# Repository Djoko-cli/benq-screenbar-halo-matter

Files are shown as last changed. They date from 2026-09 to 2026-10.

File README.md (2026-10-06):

[Français](README.fr.md) · **English**

# BenQ ScreenBar Halo → Matter

Control a **BenQ ScreenBar Halo (1st generation)** from any home-automation
app, by having an ESP32 pose as its 2.4 GHz remote.

The ESP32 is a native **Matter node**: no Homebridge, no MQTT broker. Since
Matter is multi-admin, the same device can be shared between several
ecosystems at once — see the certification caveats below.

Every document comes in English and in French (the `.fr.md` files), with a
language switch at the top.

## What is exposed

| Endpoint | Matter type | Controls |
|---|---|---|
| EP1 "Halo" | Color Temperature Light | on/off, brightness, temperature 153-370 mireds |
| EP2 "Halo avant" | On/Off Light | front lamp on (power AND front lamp) |
| EP3 "Halo arriere" | On/Off Light | back lamp on (power AND back lamp) |
| ~~EP4 "Halo auto"~~ | On/Off Plug-in Unit | **disabled by default** (see below): presses button A (auto mode), turns itself back off after 1 s (`matter impulsion <ms>`); pressing A on the remote triggers the same pulse |

- A radio frame carries a single value: both lamps share brightness and
  temperature, hence a single slider of each on EP1.
- Turning EP1 on restores the last lamp selection, like the remote's power
  button. Turning off EP2 then EP3 turns the lamp off.
- EP4, if re-enabled, is ignored when the lamp is off, and when it arrives
  together with a power or lamp command (room command, grouped tile): in
  Apple Home, show the accessories as separate tiles.
- Names are set in the app. The Kelvin values (~6500 to ~2700 K) are
  nominal, not measured.
- In `src/config.h`: `HALO1_SELECTORS_AS_LIGHTS 0` exposes EP2 and EP3 as
  outlets (a room-wide "turn off the lights" no longer touches them).
- Nothing is sent to the lamp at startup: the node restores the saved state,
  and only a command (Matter or `lampe ...`) triggers a transmission.

> **Upgrading to 0.3.0 from EP1..EP4** (Halo, front, back, auto): flash over
> the same environment (`pio run -e esp32c6thread -t upload` for the Apple
> Home Thread node), without `-t erase` or `decommission`: the pairing is
> kept, only EP4 disappears.
>
> **From the old endpoint layout** (power, front light, back halo, sensor,
> auto mode): the node must be commissioned again. Remove the accessory from
> each app, run `decommission` (or hold BOOT for 8 s, then release), then add
> it again with the pairing code (`matter`).

### EP4 "Halo auto": disabled for now

Since 0.3.0 (decision of Sep 23), `HALO1_EXPOSE_AUTO` defaults to 0: button A
is no longer exposed in Matter. The code remains, but is compiled out of the
firmware: no endpoint, no mirroring of the remote's A presses, no pulse
setting (`matter impulsion` says so, `matter` shows « bouton A (EP4) :
desactive »). EP1 to EP3 keep their numbers (EP4 was created last). Button A
remains available from the console: `lampe auto`.

On a node that is already paired, EP4 disappears from the node's endpoint
list, but Apple Home kept its "Halo auto" tile, "No Response", even after
restarting the bridge and the home hub (field test, 06/10). Since 0.4.1 the
bridge publishes the ConfigurationVersion attribute of Basic Information (EP0,
Matter 1.4) and raises it when its endpoint list changes (EP4 exposed or not,
EP2 and EP3 as lights or plugs), and on the first boot of a firmware that
tracks it: a controller that follows it then reads the device again.
`matter` prints the published version (`configuration` line). In the field
(06/10), the ESP32 layer of the stack refuses to store it (`pile REFUSE`): a
controller may still read 1, and the effect on Apple Home is not established.
What removed the tile: removing the bridge from Apple Home, `decommission` (or
8 s on BOOT), then pairing it again; "Halo auto" did not come back. "Remove
Accessory" from the tile removes the whole bridge: only do it for that.

To **bring it back**, add `-DHALO1_EXPOSE_AUTO=1` to the environment's
`build_flags` (for example `[env:esp32c6thread]` in `platformio.ini`), or
change the default in `src/config.h`, then reflash the same environment
(`pio run -e esp32c6thread -t upload`, without erasing). EP4 comes back with
the same number, its pulse duration saved in NVS (`halo1/impulsion`) is
restored, and the app shows it as a new accessory to place.

### Node identity

The Basic Information cluster (EP0) carries the product identity, set at
every boot before `Matter.begin()` (values in `src/config.h`, `MATTER_*`
macros, overridable with `-D`):

| Attribute | Value |
|---|---|
| VendorName | `Djoko-CLI` |
| ProductName | `Pont ScreenBar Halo` |
| NodeLabel | `Halo` (rewritten at every boot: a name written to this attribute by a controller is replaced) |
| SerialNumber | `HALO1-` + the factory MAC address as 12 hex digits, unique per board |
| HardwareVersion / HardwareVersionString | `1` / `ESP32-C6 SuperMini + BM5602` |
| SoftwareVersionString | `0.4.1-<commit>` ("Firmware" in Apple Home) |

- The VID and PID do not change (`0xFFF1` / `0x8000`, test certificate), nor
  do the discriminator and the pairing code: no re-commissioning. An app may
  take a while to re-read these values.
- `SoftwareVersionString` is the version from the application descriptor
  (`esp_app_desc`), which `src/app_desc.c` replaces: without it, it was the
  commit of Arduino's lib-builder (`6671d0b`). `FW_VERSION` is set in
  `platformio.ini` (`build_src_flags`); the commit comes from
  `tools/git_rev.py`, followed by `-dirty` if a tracked file was modified at
  build time, or if an untracked file was lying in `src/`, `include/` or
  `lib/`.
- `matter` shows these values as the stack reports them (`identite` and
  `versions` lines), except the NodeLabel (requested value, not read back),
  and flags any rejected value. Boot prints `firmware 0.4.1-<commit>` and
  warns if the descriptor read from the flashed image differs. Without a
  board, the same version (`App version`) can be read with:
  `pio pkg exec -p tool-esptoolpy -- esptool.py --chip esp32c6 image-info .pio/build/<env>/firmware.bin`.

## Companion app (macOS)

[Halo Compagnon](apps/macos/README.md) supervises the bridge over USB or over
the Thread network: target and raw state of the lamp, radio module, Thread
and Matter, live decoded frames, charts, commands and console. It installs
from a `.dmg` in the Halo Compagnon [releases](https://github.com/Djoko-cli/benq-screenbar-halo-matter/releases)
(`compagnon-vX.Y.Z`), then updates itself ([Installing](apps/macos/README.md#installing)).
Screenshots in demo mode (no hardware):

<p>
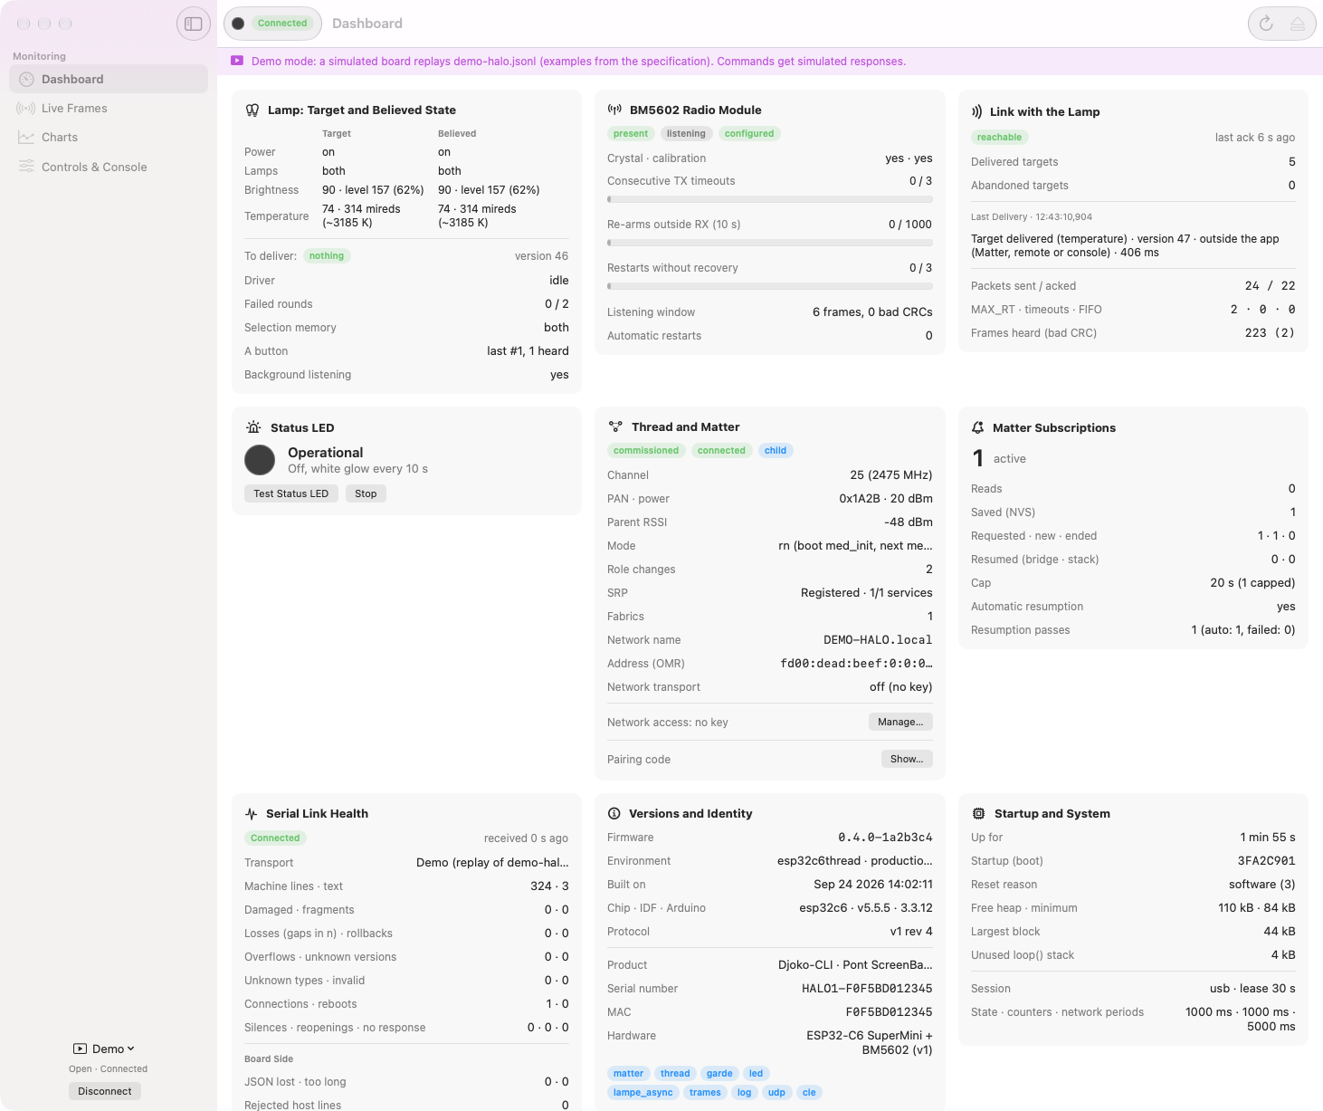
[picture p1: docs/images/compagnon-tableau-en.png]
Halo Compagnon: dashboard
  
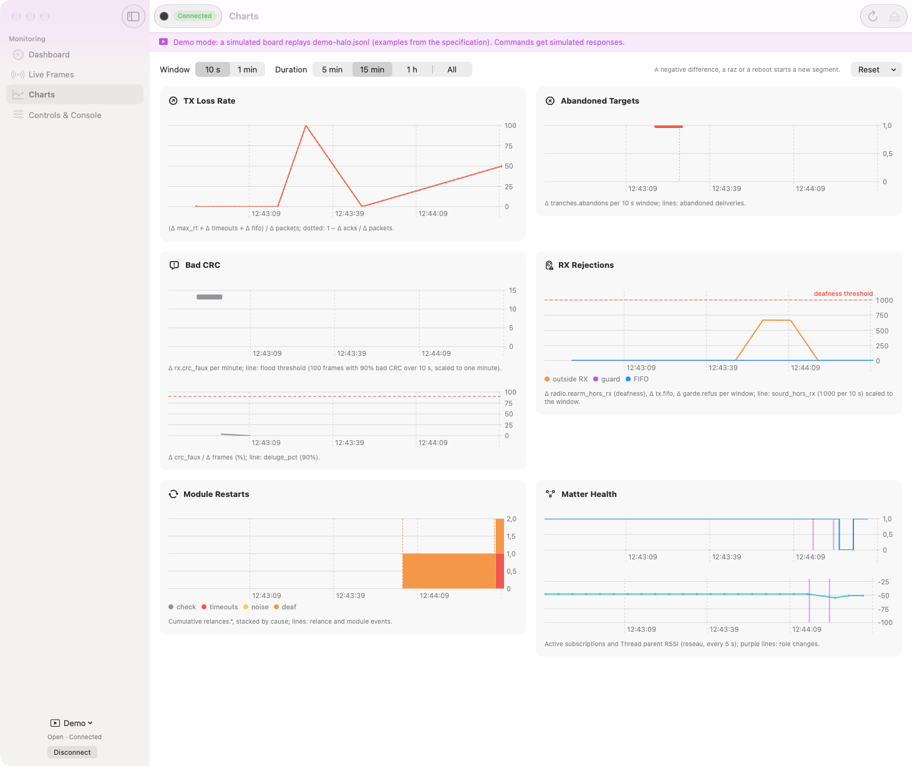
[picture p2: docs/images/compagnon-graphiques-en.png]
Halo Compagnon: charts
  
</p>

## Hardware

| Part | Role | Approx. price |
|---|---|---|
| **ESP32-C6 SuperMini** | MCU + Thread radio + Matter | ~€5 |
| **Holtek BM5602-60-1 RF module** | 2.4 GHz transceiver | ~$3–4 |

### Why the ESP32-C6

The bridge joins Apple Home over **Matter over Thread** (`esp32c6thread`
target). It needs an 802.15.4 radio: among the boards tried, only the C6 has
one. The C3, the S3 and the classic ESP32 only have Wi-Fi. Their targets still
build, as Matter over Wi-Fi, but the bridge does not use them and they are no
longer tested.

| Target | Matter network | Commissioning | Firmware size |
|---|---|---|---|
| **ESP32-C6 SuperMini** (`esp32c6thread`) ✅ | Thread | BLE | 2.50 MB |
| ESP32-C3, ESP32-S3 | Wi-Fi only | BLE | 1.79 / 1.97 MB |
| Classic ESP32 | Wi-Fi only | IP: credentials set first (`wifi <ssid> <mdp>`), the Bluetooth stack does not fit | 1.81 MB |

C6 size measured on Sep 24 (2,616,992 bytes). The other targets have not been
rebuilt since: their figures are older.

### Why the BM5602 and not a CC2500 or an nRF24L01+

The BenQ transmits **GFSK at 125 kbps**, with an Enhanced ShockBurst frame
format: preamble, 4-byte address, 9-bit PCF, CRC, and above all **hardware
auto-ACK** — the lamp answers *only* in the ACK slot.

| Chip | 125 kbps | Arbitrary 32-bit sync word | ESB auto-ACK |
|---|---|---|---|
| nRF24L01+ / BK2425 | ❌ 250 k / 1 M / 2 M only | ✅ | ✅ |
| CC2500 | ✅ | ❌ the 32-bit mode repeats the 16-bit word | ❌ must be done in software |
| **BC5602 / BM5602-60-1** | ✅ 125 / 250 / 500 k | ✅ | ✅ |

The nRF24 is ruled out right away: it cannot go down to 125 kbps. The CC2500
can, but you would have to reimplement the nRF24 CRC in software (computed
over address + PCF + payload, not the CC2500's), work around the sync word
limit, and produce the ACK within a window of about 130 µs. Doable on paper,
very painful in practice.

The BC5602 is **exactly the chip inside the lamp and the remote** (confirmed
by the FCC filings and by a PCB teardown). The whole protocol is handled in
hardware.

### Where to buy it

The module is the project's main friction point — it is not a mass-market
part.

- [Best Modules Corp](https://www.bestmodulescorp.com/en/bm5602-60-1.html) —
  a Holtek subsidiary, ~$3.10–4.28
- [Sourcengine](https://www.sourcengine.com/part-info/BM5602-60-1-145144816391)
- Official Holtek distributors
- [Holtek product page](https://www.holtek.com/page/vg/BM5602-60-1)

Buy two: at ~$4 each, it saves you wondering whether the module is dead when
something does not work.

## Wiring

See [docs/WIRING.md](docs/WIRING.md). In short, on the ESP32-C6 SuperMini
(the default target):

| BM5602 | C6 SuperMini |
|---|---|
| `VDD` / `VSS` | 3V3 / GND |
| `SCK` | IO18 |
| `GIO2` | IO19 (MISO) |
| `SDIO` | IO20 (MOSI) |
| `CSN` | IO14 |

> `GIO2` serves as MISO: the firmware switches the module to 4-wire SPI at
> init. The module has no markings, and the order of its pads reverses
> depending on the side you look at: see
> [docs/WIRING.md](docs/WIRING.md#bm5602-60-1-module-pinout).

In the enclosure, the C6 lies upside down (seen from the back) and the BM5602
flat side up, turned a quarter turn, antenna away from the C6:

<p align="center">
  Halo bridge wiring in its enclosure: six wires between the C6 SuperMini seen from the back and the BM5602 flat side up
</p>

## Enclosure

A 3D-printed enclosure holds both boards, with their antennas at opposite ends
(25 mm apart), and screws under the desk with two Ø3.5 × 16 mm countersunk wood
screws. The WS2812 status LED shows through a diffusing window, and the USB-C
port stays accessible.

<p align="center">
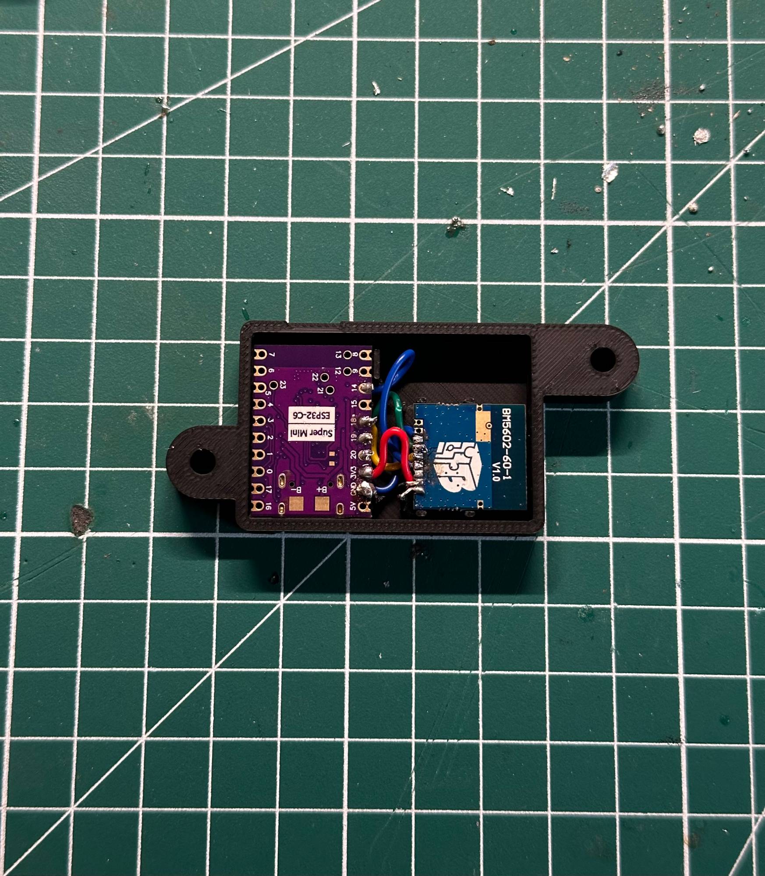
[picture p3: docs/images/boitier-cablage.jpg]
Both boards wired in the enclosure base
  
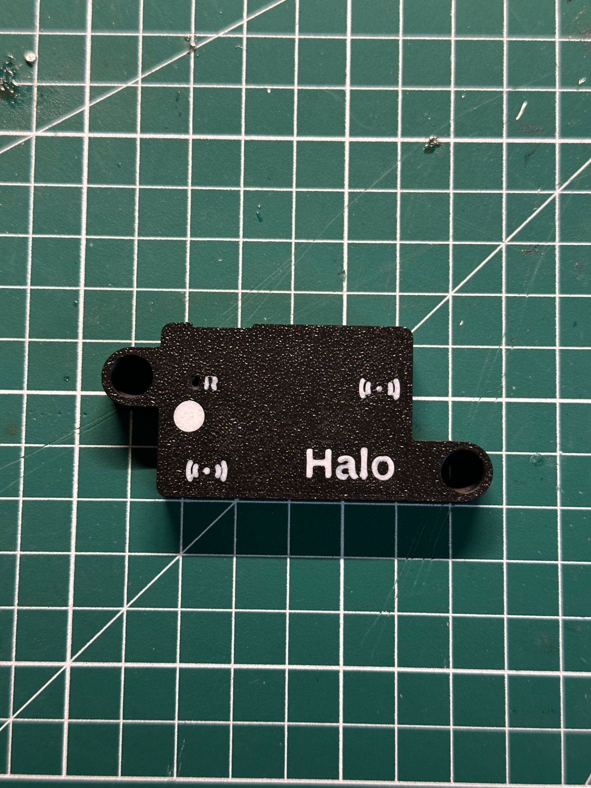
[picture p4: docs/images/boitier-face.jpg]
Engraved Halo face, with the status LED window
  
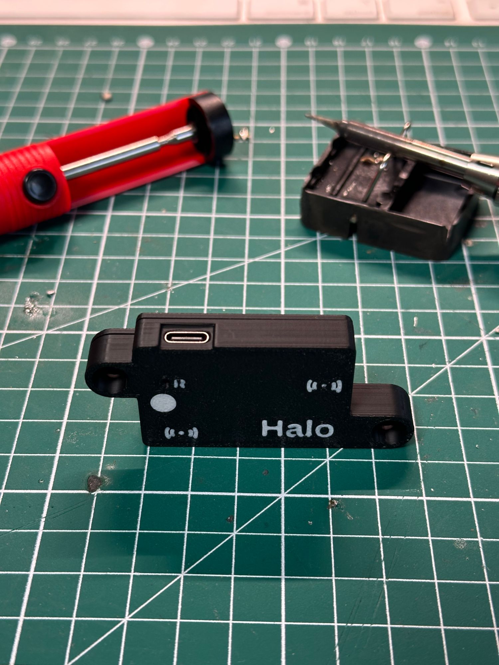
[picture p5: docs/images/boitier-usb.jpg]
Closed enclosure, USB-C side
  
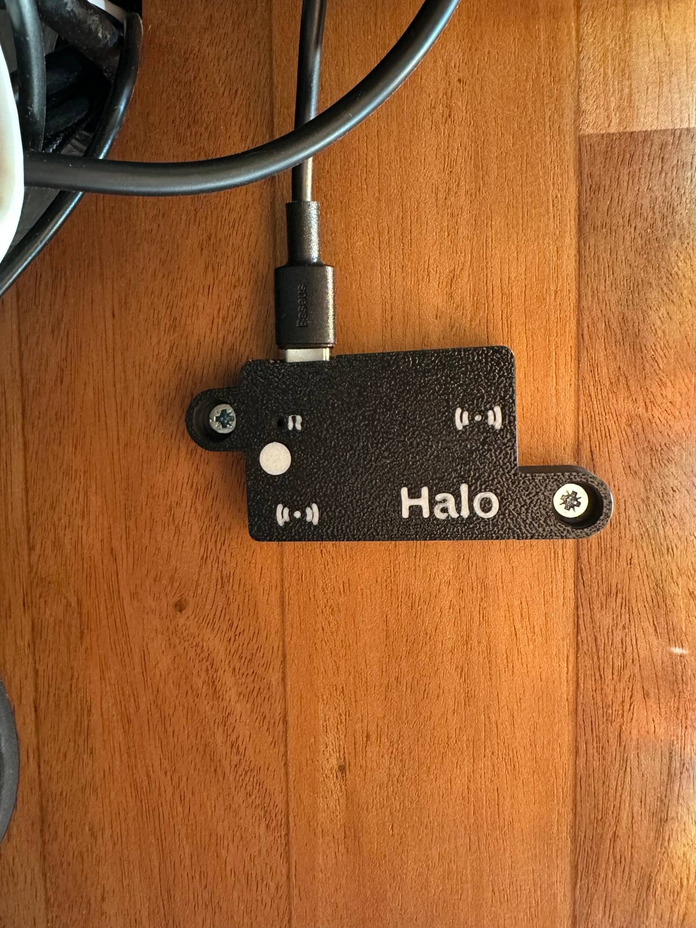
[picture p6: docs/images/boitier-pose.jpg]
Enclosure screwed under the desk
  
</p>
<p align="center">
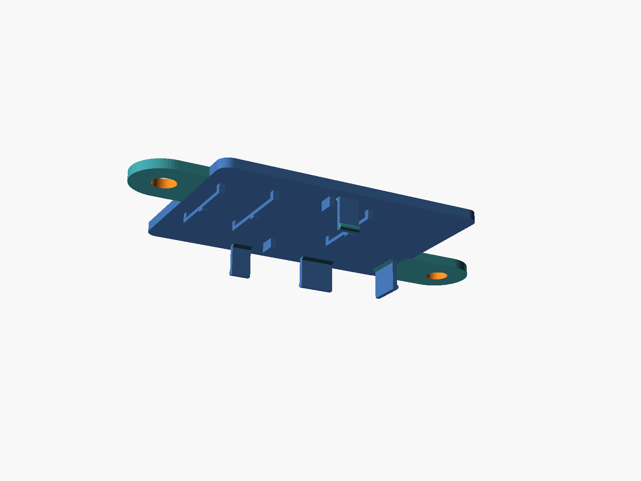
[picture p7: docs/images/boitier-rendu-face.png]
Render: engraved face
  
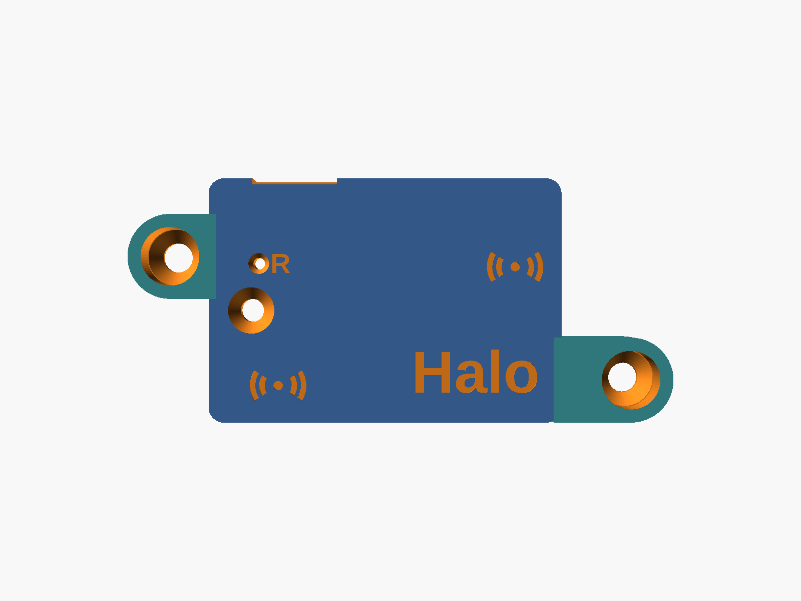
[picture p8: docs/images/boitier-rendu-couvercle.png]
Render: lid, clips and springs
  
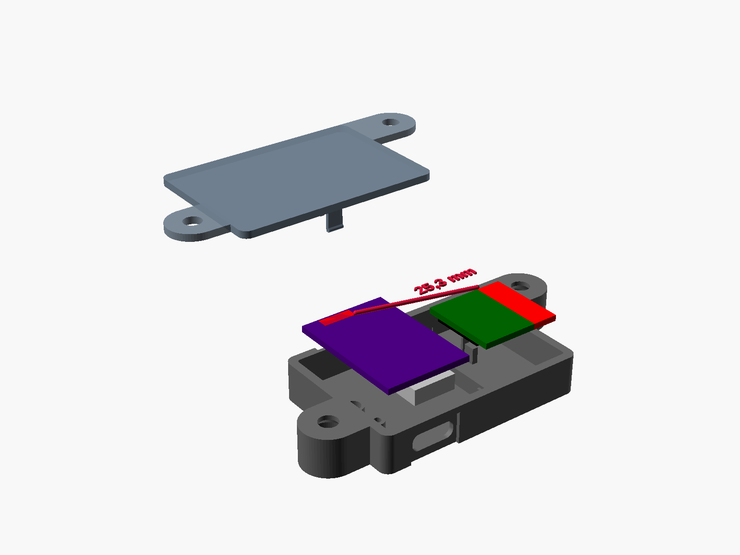
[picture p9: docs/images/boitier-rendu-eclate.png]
Exploded render: 25.3 mm between the antennas
  
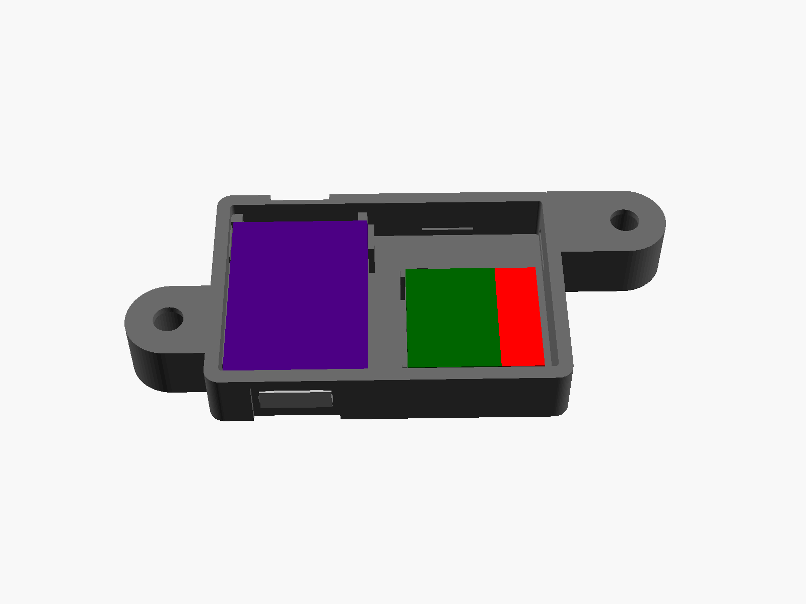
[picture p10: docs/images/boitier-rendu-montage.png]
Render: both boards in the base
  
</p>

The files are in [hardware/boitier](hardware/boitier):

| File | Part |
|---|---|
| `halo-bridge-housing.3mf` | Bambu Studio project: the four parts, already placed |
| `Back.stl` | base (70.7 × 31.6 × 8.2 mm): the visible face, engraved "Halo" |
| `Front.stl` | lid (70.7 × 31.6 × 7.0 mm): against the desk, clipped on; its springs press the boards down |
| `Diffuser.stl` | white disc for the status LED window (AMS option) |
| `Engravement.stl` | fill for "Halo", the R and the antenna marks (AMS option) |

**Printing**: black PLA, 0.2 mm layers, 4 walls, 15 % infill, no supports.
With an AMS, assign the engraving and the diffuser to a white PLA, without
moving them. **Without an AMS, delete them before slicing**: printed in black,
they would fill the engraving and block the status LED window.

**Assembly**: the C6 components side down, USB-C in its opening; the BM5602
flat side up, antenna toward the far wall (diagram above). The lid clips on,
then the two screws go through the whole assembly.

## Building

```bash
pio run -t upload -t monitor
```

The default target is `esp32c6thread` (Matter over Thread), the bridge's. The
others are selected with `-e`: `esp32c6supermini` (Matter over Wi-Fi),
`esp32c3`, `esp32s3`, `esp32dev`.

> Do not flash a Wi-Fi build onto a node paired over Thread: the pairing stays
> in NVS, but the node becomes unreachable until the Thread build comes back.

If the board boot-loops right after flashing, the clone's flash memory does
not like QIO mode: add `board_build.flash_mode = dio` to the environment.

Two build constraints, both already set in `platformio.ini`:

- **The platform is the [pioarduino](https://github.com/pioarduino/platform-espressif32) fork.**
  The Matter library ships with the Arduino-ESP32 3.x core (nothing to
  install through `lib_deps`), whereas PlatformIO's official platform stayed
  on core 2.0.x, which has no Matter at all.
- **`huge_app.csv` partitions** (3 MB APP). The Matter stack alone weighs
  ~1.4 MB. Accepted consequence: **no OTA** on a 4 MB flash.
  `min_spiffs.csv` would leave room for OTA but only fits on the C3 and the
  classic ESP32, with ~150 KB of headroom — it overflows on the S3 and C6.

## Commissioning

### 1. Check the link with the lamp

The firmware already knows the lamp's link address: `63 FD F0 4F` on air,
i.e. `4FF0FD63` in the BM5602's write order, channel 5 (2405 MHz), 125 kbps.
`lampe adresse` shows it. Nothing to search for.

In the serial monitor, listen to the remote while you use it (30 s by
default):

```
ecoute 4FF0FD63 5
```

Every gesture should print frames decoded with a correct CRC (`C4 xx` for
the dial, for example). Then `lampe` shows the driver state: target, raw
state, fields to deliver, link and radio. A first command, `lampe on` or
`lampe lum A0`, should end with an `ok ... accuses` line.

The link address depends on the remote (it comes from BenQ's pairing). For
another lamp/remote pair, `lampe adresse XXXXXXXX` (write order) stores it
in NVS. How it was found: [docs/PROTOCOL.md](docs/PROTOCOL.md).

### 2. Pair the Matter node

The pairing code is printed at boot, and `matter` shows it again:

```
code manuel : 34970112332
```

A Matter controller is required — HomePod, Apple TV, Google Nest, Echo, or
Home Assistant's *Matter Server* add-on.

Holding the **BOOT** button for 8 s, then releasing it, or the
`decommission` command, removes all fabrics so you can re-pair from scratch
(see "4. BOOT button").

### 3. Status LED

The product's indicator is the board's RGB LED (WS2812), on IO8, in the
`esp32c6thread` and `esp32c6supermini` builds. Low brightness, since it
lives under the desk: 24/255 at most per channel, 8/255 for the white glow.

| LED | Meaning |
|---|---|
| blinking blue (2 Hz) | not commissioned yet: add the accessory from the app |
| slow orange (1 s on, 1 s off) | commissioned, but no network (Thread lost; Wi-Fi for `esp32c6supermini`) |
| off, brief white glow every 10 s | all good (sign of life); also a glow when the network comes back |
| steady red | radio module down: automatic restarts did not help (see below), or module lost; lasts until it recovers |
| green flash (150 ms) | a command has just been delivered to the lamp (acknowledged) |
| red, 3 blinks | lamp unreachable: the driver gives up the command (also when the radio module is lost or down) |
| rainbow | "Identify" requested from Apple Home (Identify cluster), for the whole identification |
| red, black, purple, black, fast | BOOT button held 8 s: release to unpair, then unpairing in progress until the reboot (see "4. BOOT button") |
| white flash (150 ms) | BOOT button, short press released: reboot |

Priority: rainbow > BOOT button > red ×3 > steady red > green > network state
(the blacks of the three blinks remain visible over the steady red). On the
bench, `led test` plays each pattern in turn (21 s; the button takes over)
and `led` reports the current pattern and the radio module state. If green
and red are swapped, the board's WS2812 is not GRB:
`-DSTATUS_RGB_ORDER=LED_COLOR_ORDER_RGB` in `platformio.ini`.

The small LED on IO15 stays an input, so it is off whatever its polarity: a
single indicator. As an input, it also does not interfere with the CC2500's
GDO2, which lands on IO15 when the capture board is plugged in. The
diagnostic build only sets the WS2812 to black at boot: it keeps its last
color across a reset or a flash, and a product build's blue would otherwise
stay lit on the bench. Among the other targets, only `esp32dev` blinks its
simple LED (IO2) with the same patterns, without the glow; on the C3 and S3
DevKits, `PIN_STATUS_LED` (IO8, IO48) is the pin of their WS2812, not
declared: no visible indicator.

**Automatic radio module restart.** On Sep 24, the metal tip of a sliding
caliper resting on the BM5602's crystal locked it up for ~70 min: every
transmission timed out (186 in a row at the end), listening went deaf (no
frame at the end, after ~96,000 frames with a bad CRC since boot), while its
configuration still read back correctly; only `rfinit` cured it. So the
driver restarts the module on its own (`halo.begin()`, ~300 ms, up to
~0.5 s if the crystal or the calibration do not respond) on three chip
symptoms: 3 transmissions in a row with neither TX_DS nor MAX_RT (30 ms
timeout); while listening, at least 100 frames in 10 s, of which at least
90 % with a bad CRC (the remote's dial produces ~9 per second, with a
correct CRC); or deaf listening, at least 1000 re-arms in less than 10 s on
a chip that does not stay in receive mode (the incident produced ~450 per
second, seen within ~2-3 s; normally estimated at well under one per second,
inferred from the totals, to be confirmed with « hors RX » in
`lampe stats`). An unplugged lamp (MAX_RT, silence) never triggers a
restart. At most one restart per minute; after 3 restarts in a row without
recovery (an acknowledgement, a listening window with mostly correct CRCs,
or, after a restart for deafness, 10 s of listening during which the chip
stays in receive mode with no timed-out transmission), if the symptom comes
back, the module is **DOWN**: steady red, one attempt every 10 min. Each
restart writes `[lampe] BM5602 : ...` lines on the console (never blocking:
lost if the serial buffer is full); `lampe` shows the state and the last
restart, `lampe stats` the restarts by cause and the latest ones, with
timestamps. Details and thresholds:
[docs/PLAN-PILOTE-HALO1.md](docs/PLAN-PILOTE-HALO1.md), C.5.

### 4. BOOT button

In the 3D-printed case, only **BOOT** (IO9, marked B) remains accessible: no
RST. So it is used to reboot and to unpair. Everything is decided **on
release**:

| Press | LED during the press | On release |
|---|---|---|
| less than 2 s | nothing special | white flash (150 ms), then **reboot** (lamp state saved first, like `reboot`) |
| 2 to 8 s | nothing special | **cancelled**: nothing happens (safeguard against a mistake) |
| 8 s or more | red, black, purple, black, fast (100 ms each) from 8 s: "release to unpair" | **unpairing**: removal of all Matter fabrics (the accessory leaves Apple Home), then reboot; the LED keeps the red/purple until the reboot |

IO9 is a strapping pin: **held low at reset, it makes the C6 boot into
download mode**, where it stays inert until a power cycle. So the firmware
never acts while the button is pressed: it waits for the release (30 ms
debounce), then 100 ms of uninterrupted high readings, and reads the pin
again 100 ms right before acting (pressed and held again at that moment, the
action is abandoned). Finally, **every** software reboot (button, `reboot`,
`decommission`, and the end of unpairing, which the Matter stack triggers
itself a while later) waits until the pin has read high for 50 ms in a row:
BOOT held during a reboot delays it until release, with no limit (a stuck
button blocks the board, which restarts as soon as it is released, instead
of leaving it in download mode). Other safeguards:
- a button already pressed at boot is ignored until it is released;
- a new press while an action is pending abandons it: it counts on its own;
- during unpairing, the button is inert (a reboot in the middle of the erase
  would leave Matter half removed); if the board is still running 10 s
  later, it reboots on its own;
- if `loop()` was blocked for more than 100 ms during the press or at one of
  its edges (bench tool, radio module restart), the duration is uncertain:
  the press is ignored (except a long press already armed, which is
  certain);
- every decision is announced on the console, `[bouton] ...` (`log`
  message, `src` `bouton`, in `json log 1` mode, outside the log cap).

Diagnostic build (no Matter, no LED): a short press reboots; a long press
only explains itself on the console. Pure logic, tested on the host:
`src/boot_button.*`.

### Certification: what works and what needs an extra step

The firmware uses the **Matter SDK test certificates**: `VID 0xFFF1`,
`PID 0x8000`. This is the normal development mode, but each ecosystem
treats it differently:

| Ecosystem | Behavior |
|---|---|
| **Home Assistant** | accepts it directly (Matter Server) |
| **Apple Home** | adds the accessory while showing an "uncertified accessory" warning, which you just confirm |
| **Google Home** | refuses it, unless you create a project in the [Google Home Developer Console](https://developers.home.google.com/matter/get-started) declaring the same test VID/PID pair |
| **Alexa** | not checked |

Removing the warning entirely would require a CSA-assigned VID and a
certification — out of reach for a personal project.

## Serial commands

`help` lists everything. Commands and their output are in French.

| Command | Effect |
|---|---|
| `info` | hardware, radio configuration, driver state |
| `matter` | Matter state, pairing code, node identity and versions, bridge counters, Identify requests |
| `matter impulsion [300..15000]` | duration of the EP4 pulse in ms, kept in NVS (only when EP4 is re-enabled; otherwise a message says so) |
| `matter reprise` | (Thread) immediately restarts the resumption of Apple Home's saved subscriptions |
| `matter reprise auto [0\|1]` | (Thread) restarts on its own after a reboot: Thread + SRP ready for 10 s, not before 50 s (plus the saved floor), for each saved subscriber with no active subscription; CASE session first (a failure costs the stack nothing), then resumption; then 30 s, 60 s, 5 min after each failure, and a check every 5 min as long as a subscription is active (NVS) |
| `matter med [0\|1\|2]` | (Thread) device type at the next boot: 0 router, 1 MED from init (no new attach), 2 MED after `Matter.begin()` (old behavior) (NVS) |
| `matter maxint [0\|10..3600]` | (Thread) cap on the max interval of new subscriptions, 20 s by default, 0 = the controller's (NVS). Only applies from Apple's next new subscription: a resumed subscription keeps its saved interval |
| `lampe` | Halo 1 driver: target, raw state, fields to deliver, link, radio |
| `lampe on` / `lampe off` | turn on / off, same rules as Matter |
| `lampe avant on\|off` / `lampe arriere on\|off` | one lamp, front or back (like EP2 / EP3) |
| `lampe mode avant\|arriere\|deux` | lamps lit (and power on) |
| `lampe lum 4C..FE` / `lampe niveau 1..254` | raw brightness (hex) / Matter level |
| `lampe temp 0..100` / `lampe mired 153..370` | temperature: 0 cold, 100 warm / in mireds |
| `lampe auto` | button A (refused when the lamp is off) |
| `lampe sync` | resends everything known |
| `lampe trace 0\|1` / `lampe stats` | per-event log / counters, including the automatic module restarts by cause |
| `lampe adresse [8 hex]` | lamp address (write order), in NVS |
| `lampe help` | all `lampe` commands (settings and bench) |
| `led` | status LED: current pattern, displayed color, radio module state |
| `led test` / `led stop` | plays each LED pattern in turn (21 s), without blocking / stops it |
| `ecoute 4FF0FD63 5 [ms]` | passive listening to the remote, never acknowledging |
| `txack <adr> <canal> <charge> [n] [ms]` | bench: standard-format transmission, automatic acknowledgement, verdict per attempt |
| `regs` | dump of the BC5602 registers |
| `rfinit` | re-tests the module after fixing the wiring, without reflashing |
| `wifi <ssid> <mdp>` | Wi-Fi credentials (classic ESP32 only) |
| `decommission` | removes all Matter fabrics |
| `reboot` | saves the lamp state, then reboots |

`help` also lists the bench and reverse-engineering tools: `prxack`, chip,
spectrum and GIO3 probes, CC2500 module. `addr` and `chan` only configure
those tools; the driver has its own address (`lampe adresse`).

A line longer than 127 characters is refused (`Ligne refusee (trop_long)`),
instead of being truncated and then executed; Ctrl-U clears the current
line.

### Machine mode (companion app, since 0.4.0)

The supervision app (macOS first) talks to the board over the same USB
port, or over the Thread network (UDP, section 10), with the protocol in
[docs/PROTOCOLE-JSON.md](docs/PROTOCOLE-JSON.md): it sends console commands
prefixed with `id=<n> `, and the board answers with machine lines (RS byte
0x1E + a compact JSON object + LF, 1024 bytes at most), mixed with the usual
text. Without `json 1` and without `id=`, the human console is unchanged.

| Command | Effect |
|---|---|
| `json` | session state, as text |
| `json 1 [bail 0\|10..600]` | machine mode: echo, prompt and `Serial.flush()` disabled; `hello`, `config`, then the full snapshot; 30 s lease by default, renewed by any received line (`json ping`); `bail 0` on the bench: until `json 0` |
| `json 0` | back to human mode (`fin` message, then the prompt); over the network, also frees the session's slot (rev 4) |
| `json etat` / `json hello` | snapshot (`etat`, `compteurs`, `reseau`) / `hello` and `config`, once, even in human mode |
| `json periode\|compteurs\|reseau <ms>` | periods of the `etat` messages (0 or 200..60000, 1000 by default), `compteurs` (same), `reseau` (0 or 1000..60000, 5000); `hb` every 2 s if the `etat` messages are off or slow |
| `json trames 0\|1` / `json log 0\|1` | `rx` and `tx` events (on by default) / `[lampe]` and `[matter]` announcements as `log` messages instead of text |

- With `id=`, every line receives a `reponse`; the `lampe` state commands
  (`on`, `off`, `avant`, `arriere`, `mode`, `lum`, `niveau`, `temp`,
  `mired`, `auto`, `sync`) become asynchronous: `reponse` right away (code
  `accepte`, `differe` or `ok`), then `livraison` when the driver is done.
  The other commands keep their text, between `reponse debut` and
  `reponse fin`.
- The board never waits for the app: a line that does not fit in the
  transmit buffer is lost and counted (`etat.sante.sys.json_perdus`), and
  `n` skips. One exception, without blocking the loop: a deferred `reponse`
  (after the snapshot of `json 1`, `json etat`, `json hello`, or the `fin` of
  a command whose text filled the buffer, such as `help`) waits in a queue
  for room for a whole line. At most 20 lines per second from the host
  (`cadence`).
- Nothing is persisted: every boot starts in human mode. `json cle` sets the
  network transport key (section 10.4), over USB only.
- On the bench, `python3 tools/json_check.py <capture>` checks a raw capture
  of the port (framing, types, required fields, sizes, gaps in `n`); a field
  unknown to v1 is only a warning (`--strict`: an error).

## Halo 1 protocol

The protocol is established, and verified by transmitting to the lamp:
standard BC5602 frame (4-byte address, 9-bit PCF, hardware CRC-16), two-byte
payload (power / lamps / selector flags, then value), empty
acknowledgement. So the lamp's state cannot be read: the driver tracks the
state it sends and what it hears from the remote. Details, evidence and
still-open questions: [docs/PROTOCOL.md](docs/PROTOCOL.md) (header block,
then the Halo 1 sections at the end).

## Layout

```
platformio.ini            4 ESP32 targets, pioarduino platform, huge_app partitions
src/config.h              pins, Halo 1 driver settings, Matter identity
src/fw_version.h          firmware version (FW_VERSION + git revision)
src/app_desc.c            application descriptor: version reported by Matter
src/bc5602.{h,cpp}        low-level transceiver driver
src/cc2500.{h,cpp}        minimal CC2500 driver: raw listening (cc* commands)
src/swd.{h,cpp}           bit-banged SWD (swd command)
src/halo.{h,cpp}          module startup (also the driver's restart), bench tools
src/halo1_proto.{h,cpp}   pure Halo 1 protocol: frames, CRC, scheduling
src/halo1_map.{h,cpp}     Matter <-> lamp mappings, intent rules
src/halo1_radio.{h,cpp}   proven BC5602 sequences, non-blocking reconfiguration
src/halo1_watch.{h,cpp}   when to restart the module on a chip symptom (pure logic, tested on the host)
src/halo1_lamp.{h,cpp}    driver: target, acknowledged bursts, tracking of the remote
src/cli_lampe.cpp         'lampe ...' commands
src/matter_bridge.{h,cpp} Matter endpoints, intent box, mirror of the target, Identify
src/matter_resume.h       resumption schedule of Matter subscriptions (Thread bridge)
src/halo1_events.h        driver events as plain data (frames, packets, restarts, module)
src/json_out.{h,cpp}      JSON protocol: machine line writer, messages, queue (pure, tested on the host)
src/json_mode.{h,cpp}     machine mode: session, 'json' commands, periodic state, events, deliveries
src/h1_proto.{h,cpp}      H1 envelope of the network transport: sessions, MAC, replay (pure, tested on the host)
src/h1_crypto.cpp         HMAC-SHA256 and SHA-256 (mbedTLS)
src/net_udp.{h,cpp}       network transport: UDP over Thread, port 5480, key in NVS
src/status_led.{h,cpp}    status LED: patterns and priorities (pure logic, tested on the host)
src/boot_button.{h,cpp}   BOOT button: short press = reboot, 8 s = unpair (pure logic, tested on the host)
src/net.{h,cpp}           Wi-Fi for targets without BLE commissioning
src/cli.{h,cpp}           reverse-engineering serial console
src/main.cpp              assembly
docs/PROTOCOL.md          radio protocol, known / to confirm, capture methods
docs/PROTOCOLE-JSON.md    JSON protocol between the board and the companion app (machine mode)
docs/WIRING.md            wiring and hardware pitfalls
docs/AUDIT-2026-09-23.md  audit of the frame format and of the bugs, with their status
docs/PLAN-PILOTE-HALO1.md Halo 1 driver plan, steps and bench results
docs/BRIEF-BOITIER.md     brief for the 3D-printed case
docs/PISTES-FUTURES.md    ideas outside the current scope
docs/ETUDE-THREAD-COMPAGNON.md  study of the network transport and of the companion app
apps/macos/               macOS companion app (SwiftUI): USB and Thread network
hardware/boitier/         3D-printed enclosure: 3MF project and 4 STL parts
tools/test_halo1.sh       host tests of the Halo 1 protocol, module watchdog, status LED, BOOT button and JSON protocol, without a board
tools/json_check.py       checks captured machine lines (and the examples in docs/PROTOCOLE-JSON.md)
tools/git_rev.py          git revision for FW_GIT_REV (PlatformIO dynamic flag)
tools/halo_udp.py         bench client of the network transport (key, session, refusal)
tools/macos/thread-route/ macOS system helper that keeps the Thread route (kernel bug)
```

## Credits

The Halo 2 protocol was reverse-engineered by
[kuzmin-no](https://github.com/kuzmin-no/BenQ_ScreenBar_HALO_2_HA_integration)
(MicroPython, Raspberry Pi Pico W, MQTT output). This project started as a
C++ port of that work, for ESP32 with native Matter; the Halo 1 turned out to
speak a different protocol (two-byte payload, empty acknowledgement), and the
Halo 2 layer was removed once the Halo 1 driver was validated.

Identifying the BC5602 in the Halo 1 is credited to `hertzg`, and the PCB
teardown to `b4shful`, on the
[Home Assistant thread](https://community.home-assistant.io/t/benq-screenbar-support/490864).

Halo Compagnon embeds [Sparkle](https://sparkle-project.org) 2.10.0 (automatic
updates), under the MIT license; the text of the license is shipped in the
`.dmg`, next to the app (`Sparkle-LICENSE.txt`).

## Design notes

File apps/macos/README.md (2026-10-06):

[Français](README.fr.md) · **English**

# Halo Compagnon (macOS)

Native SwiftUI app that supervises the BenQ ScreenBar Halo 1's ESP32-C6
bridge over USB or over the Thread network (UDP, section 10), following the
machine protocol from [`docs/PROTOCOLE-JSON.md`](../../docs/PROTOCOLE-JSON.md)
(v1). The same protocol code will later serve the iOS app.

> **Status.** Tried on the bench with the bridge (firmware 0.4.0, protocol
> revision 4) on Sep 25 and Sep 27, over USB and over the Thread network: see
> "To Verify on the Bench". Faced with older firmware, the app detects it
> (`Commande inconnue : "id=1"`) and stays in console-only mode. Everything
> can be seen in **Demo Mode**, with no hardware: the screenshots below come
> from it.

## Screenshots

Demo Mode, no hardware: dashboard, live frames, charts, controls and console.

<p>
  Dashboard
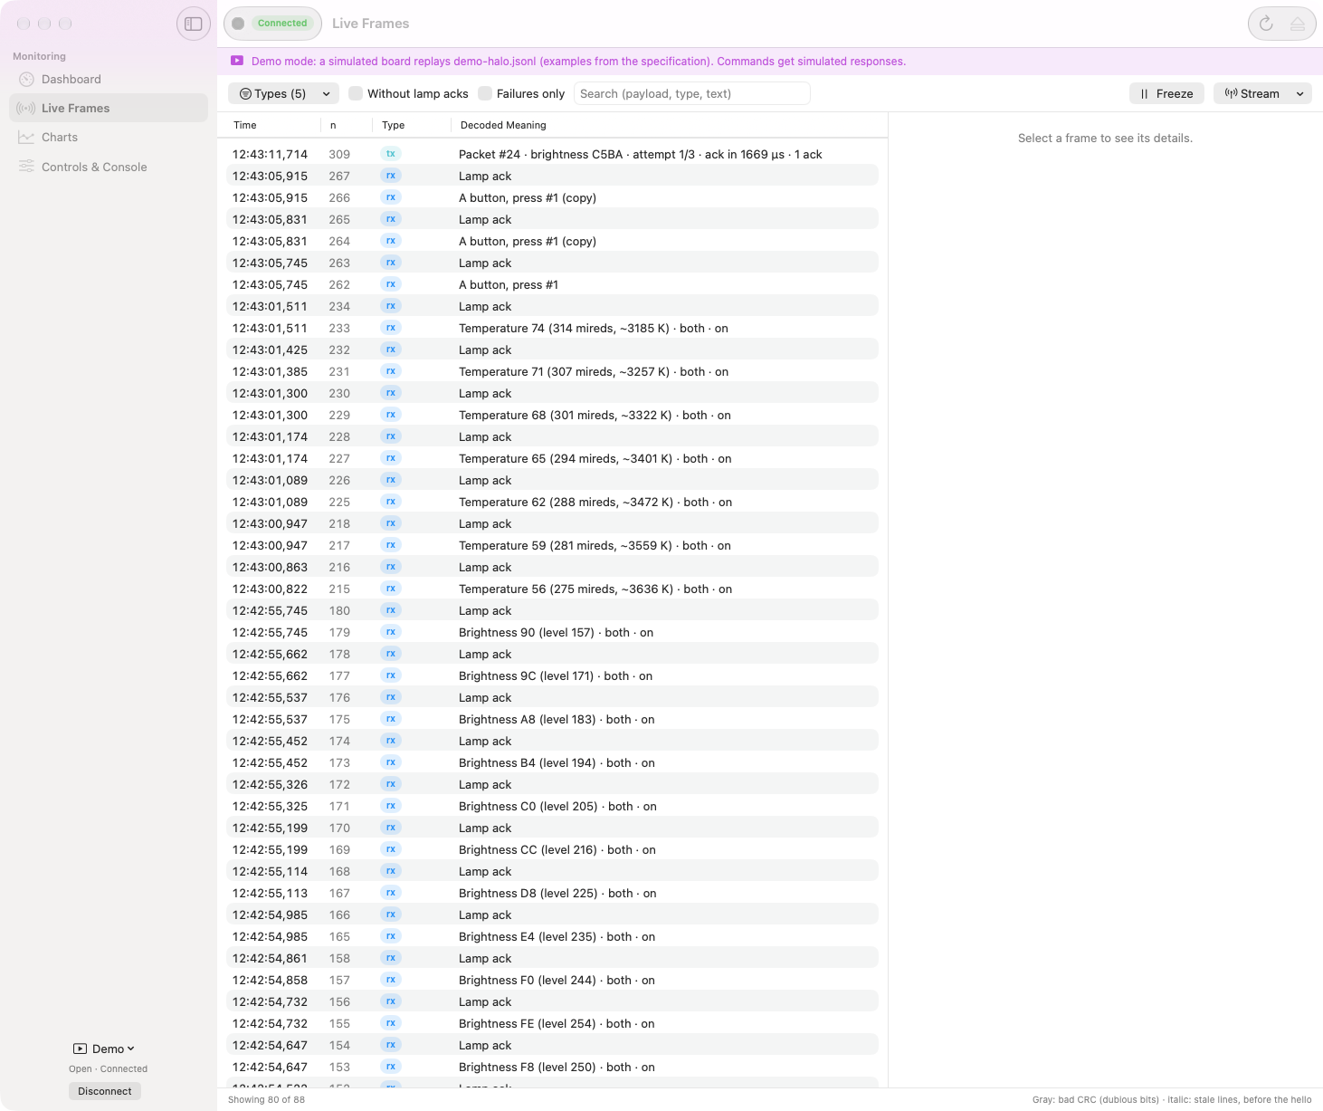
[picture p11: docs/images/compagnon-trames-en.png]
Live Frames
  
  Charts
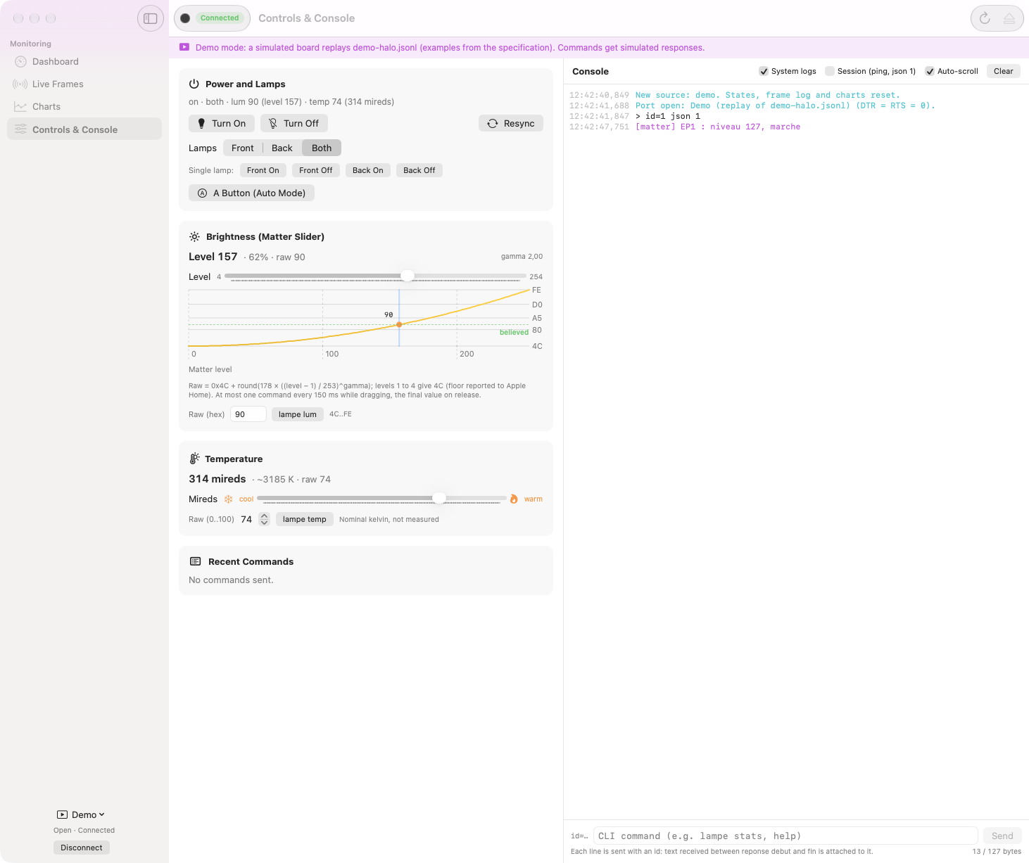
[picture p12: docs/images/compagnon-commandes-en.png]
Controls & Console
  
</p>

## The Four Screens

| Screen | Content |
|---|---|
| **Dashboard** | Target and raw state side by side (mismatches and fields awaiting delivery in orange), pilot phase, active slices; link with the lamp (acks, deliveries, drops); BM5602 module (mode, delay / deafness / restarts-without-recovery gauges, **DOWN** banner); status LED animated from `status_led.h` (and `led test`); Thread and Matter (role, parent RSSI, SRP, fabrics, network name and OMR address, network transport); Matter pairing: **Add to Home** card up front when the bridge is not commissioned (large QR code, 11-digit code grouped as in Home, Copy button, steps), otherwise a **Pairing code…** button in the Thread and Matter card (the bridge's label, and when it applies; codes received over USB only, firmware revision 3); subscriptions; serial link health (damaged lines, fragments, `n` gaps, JSON lost on the board side, last rejected line); versions, identity, capabilities; startup (`boot`, cause, `up_s`) and system. |
| **Live Frames** | `rx`, `tx`, `livraison`, `relance` events (and `module`, `intent`, `abonnement`, `thread`, `led`, `reponse`...) with their decoded meaning ("Brightness A5 (level 180) · both · on", "MAX_RT (no ack) at 11476 µs"...). Filters by type, without the lamp's acks, failures only, search; detail and JSON for each frame. Bad CRC in gray, old lines (before the `hello`) in italics. Stream menu: `json trames 0/1`, `json log 0/1`, `lampe ecoute 0/1`. |
| **Charts** | Swift Charts, computed as section 8 describes: `compteurs` block differences over a 10 s or 1 min window, new segment on a negative difference, `raz`, or restart. TX loss rate and its complement, dropped targets (and `livraison` `abandon` markers), bad CRC per minute and as a share of frames (flood thresholds), reception refusals (`rearm_hors_rx` with the deafness threshold, `tx.fifo`, `garde.refus`), stacked restarts by cause (`relance`, `module` markers), Matter health (active subscribers, parent RSSI, role changes). `lampe stats raz` with confirmation. |
| **Controls & Console** | Turn on, turn off, lamps (`lampe mode`, `lampe avant/arriere on/off`), button A, `lampe sync`; brightness slider in Matter level with the board's gamma mapping (`gamma_c`) plotted (level → raw 4C..FE); temperature slider from coldest to warmest (mireds, nominal Kelvin, raw value); raw values (`lampe lum`, `lampe temp`); recent commands and their fate (accepted, delivered, dropped, no response...). Raw console: each line leaves with an `id`, the text received between `reponse debut` and `fin` is attached to it, `reponse` and `livraison` are rendered human-readable there. |

## Installing

Download `Halo-Compagnon-X.Y.Z.dmg` from the latest Halo Compagnon
[release](https://github.com/Djoko-cli/benq-screenbar-halo-matter/releases) (`compagnon-vX.Y.Z`),
open it, and drag **Halo Compagnon** onto **Applications**. macOS 15 or later.

- **First launch (Gatekeeper).** The app is signed with a self-signed
  certificate, `Djoko-cli Code Signing`, not with an Apple Developer ID, and
  isn't notarized. macOS refuses to open it the first time: in System
  Settings, Privacy & Security, click "Open Anyway" next to Halo Compagnon,
  then confirm with your password (since macOS 15, a right-click no longer
  does it). Only once.
- **Automatic Updates** (Sparkle 2). The app checks for a new version at
  launch and then every 24 hours, downloads it, checks its Ed25519 signature,
  and installs it when the app quits, or right away with "Install and
  Relaunch". An update installed this way doesn't go back through Gatekeeper:
  the signature takes its place. "Check for Updates…" is in the Halo
  Compagnon menu; Settings, General, "Updates", has "Check for updates
  automatically" and "Install updates automatically", both on by default. A
  copy downloaded before the first version with Sparkle (1.0.0) doesn't
  update itself.
- **Keychain.** Every published version is signed by the same certificate:
  an update keeps access to the bridge's key in the keychain (network
  source). macOS will likely ask again only when switching between a work
  build, signed ad hoc, and a published version.
- **Thread Route.** The network source needs the Mac's route to the Thread
  network, which Thread Route keeps (see "No IPv6 route" under "Network
  Source"). It installs from a copy of this repository:
  `sh tools/macos/thread-route/installer.sh` (administrator password). If
  halo-routes, its former name, is still there, the installer stops it, waits
  (up to 25 s) until launchd has unloaded it, and only then removes its files;
  if the wait runs out, it stops with nothing removed. Settings, General,
  shows its status.

## Credits

The app embeds [Sparkle](https://sparkle-project.org) 2.10.0 (automatic updates), under the MIT
license; the text of the license is shipped in the `.dmg`, next to the app (`Sparkle-LICENSE.txt`).

## Build, Test, Run

Requirements: macOS 15 or later, Xcode 16 or later (developed with Xcode 27),
[XcodeGen](https://github.com/yonaskolb/XcodeGen) (`brew install xcodegen`).
One dependency, Sparkle 2 (2.10.0, the updates), through the Swift Package
Manager. The Xcode project is generated: only `project.yml` is tracked.

```sh
cd apps/macos
xcodegen generate
xcodebuild -project HaloCompagnon.xcodeproj -scheme HaloCompagnon -destination 'platform=macOS' build
xcodebuild -project HaloCompagnon.xcodeproj -scheme HaloCompagnon -destination 'platform=macOS' test
```

Swift 6 (full strict concurrency), warnings treated as errors: the build
produces no warnings at all.

Running it: open `Halo Compagnon.app` (in `DerivedData/.../Build/Products/Debug/`),
or `xed .` then ⌘R. Useful launch arguments:

```sh
open "…/Halo Compagnon.app" --args -demo -ecran trames   # démo directe, écran choisi
```

(`-ecran`: `tableau`, `trames`, `graphiques`, `commandes`.)

The app **never opens a port on its own**: you have to choose a source in
the sidebar (the Espressif port, VID 303A, is offered first) or Demo Mode
(⇧⌘D).

### Signing for the Network Source

`Signature.xcconfig` (committed) signs ad hoc by default: the repo builds
and tests everywhere, with no Apple account, but with no stable local
network authorization and no keychain that survives from one build to the
next. For the network source, create `apps/macos/Local.xcconfig` (ignored
by git, see `.gitignore`):

```
DEVELOPMENT_TEAM = <équipe, 10 caractères>
CODE_SIGN_IDENTITY = Apple Development
```

Team: `security find-certificate -c "Apple Development" -p | openssl x509 -noout -subject` (the OU field).

Two pitfalls hit on Sep 25:
- **Sandbox container.** Switching from an ad hoc install to team signing
  on an already-installed app: macOS protects the container created by the
  first ad hoc build. Quit the old app, then accept the system prompt about
  access to "other apps' data" — otherwise hosted tests stay stuck on
  "test runner hung before establishing connection".
- **`DerivedData` under `~/Documents`.** macOS adds extended attributes
  there that the test bundle's ad hoc signature rejects ("resource fork,
  Finder information, or similar detritus not allowed"). Always build with
  a `-derivedDataPath` outside `~/Documents`, for example:

  ```sh
  DD=$HOME/Library/Developer/Xcode/DerivedData/halo-sdd
  xcodebuild -project HaloCompagnon.xcodeproj -scheme HaloCompagnon -destination 'platform=macOS' -derivedDataPath "$DD" test
  ```

### Publishing a Version

`apps/macos/Outils/publier.sh X.Y.Z` publishes version X.Y.Z, the
`MARKETING_VERSION` of `project.yml`, from an up-to-date `main`. Before any
test, it checks that the tag and the version in the feed don't exist yet (and
that the version is higher than the head of the feed), that the tree is clean,
that the Git author and committer are `Djoko-cli` at the GitHub noreply address,
that the keychain holds a single `Djoko-cli Code Signing` certificate whose subject is
only that name, and that the anonymization check is on the Mac (it is
private): outside a rehearsal, without it, nothing is published. Then it runs
all the tests (the app in French and English, the host tests of the bridge,
Thread Route), builds in Release without debug symbols and with neutral source
paths, signs the app with that certificate (`IDENTITE_SIGNATURE`, in
`publier.sh` only: work builds and tests stay ad hoc), and makes the `.dmg`
(the app, a shortcut to Applications and Sparkle's license). It refuses any
binary (Sparkle's included) that carries the home folder, `/Users/` or the
account name, and any real data found by the anonymization check. It signs the
`.dmg` with the Ed25519 key of the keychain (`sign_update` from the Sparkle
2.10.0 archive, whose `bin` folder is given by `SPARKLE_BIN`), then adds the
version, with the notes of `NOTES-VERSIONS.md`, at the top of the update feed,
`apps/macos/appcast.xml`, which keeps every published version. Just before the
first public step it reads the state again (`main` unchanged and up to date,
`gh` logged in, `git push --dry-run` passing, release absent). It then creates
the GitHub release with `gh release create --target`, which also creates the
`compagnon-vX.Y.Z` tag (the app's own tags, apart from the bridge's) on the
checked commit, with the `.dmg`; commits the feed on `main` and pushes it right
away; and copies the `.dmg` to the Desktop. Each step done is noted in
`gestes.txt`, in `apps/macos/build/publication/X.Y.Z/`: if the script stops
halfway, the rest is resumed from that file and that folder, step by step, not
by running the script again. The build number, which Sparkle compares, is the
number of commits of `main` (the whole repository).
The app reads its feed in the repository, at
`https://raw.githubusercontent.com/Djoko-cli/benq-screenbar-halo-matter/main/apps/macos/appcast.xml`;
each `.dmg` stays in its release.
With `--repetition`, the same without GitHub or Desktop, for a local trial,
with a test key pair and a test certificate in a separate keychain if given;
only there may the anonymization check be missing.
A notarization step (Developer ID) is written but off: `NOTARISER=1`, with
`PROFIL_NOTARISATION`, the keychain profile of `notarytool store-credentials`.
Tests: `/usr/bin/python3 -m unittest discover -s Outils/tests`.

## Languages: French and English

The app speaks French (development language: the catalog keys are the
French text) and English. **Settings** (⌘,) › **Language**: "System
Default" (the default), *English*, or *Français*. The choice is kept in
the app's preferences (`langue`).

- **Live**: window content changes right away, without restarting or
  losing the current screen, filters, or console. Views (`Text("...")`)
  read the environment's locale; computed text (decoded meaning, labels,
  notes, errors, app menus) goes through `Localisation` (framework), which
  is observable: a view that has read one redraws itself. The decoded
  meaning in the frame log is recalculated (search follows along), as are
  the alert banner and the chart markers.
- **At the next launch**: what macOS draws itself (the Halo Compagnon,
  Edit, Window menus, system dialogs), which follows the app's
  `AppleLanguages`; the choice writes it. System Settings (Language &
  Region › Applications) writes to the same place: the value that was
  there before the first *English*/*Français* choice is kept
  (`AppleLanguagesAvantChoix`), and "System Default" restores it (or
  removes `AppleLanguages` if there wasn't one). Settings says so.
- **Keep their language until the next text update** (Settings says this
  too): lines already written to the console (it's a log), the reason for
  a reconnection or a port error in the sidebar, the last rejected line,
  and the console's input error. These texts are made at the moment of the
  event, partly from system text (`strerror`, decoding errors).
- **System Default**: the first of the preferred languages the app knows
  how to serve (`en-GB` gives English); none of them (German...): French,
  like AppKit, which falls back to the development language.
- **Formats** (times, numbers, bytes, relative dates): the chosen language
  combined with the user's region, as macOS does for a language chosen on
  a per-app basis (English in France: `en_FR`, 24 h, decimal comma, "kB"
  and not "ko"). Quantities keep their thousands separators; identifiers
  (`id`, packet numbers, versions), kelvins, microseconds, and hex stay
  raw, on every screen.
- **Technical terms stay unchanged** in both languages: JSON fields and
  values (`lum`, `temp`, `raz`...), CLI commands (`lampe stats raz`,
  `json trames 0`), hex, units. The only exceptions are the closed-list
  values with French names (`ValeurFirmware`): startup cause (`reset`:
  `mise_sous_tension` → *power-on*...), `build`, button A's outcome from an
  `intent`, origin, mode, and subscription-resumption verdicts; an unknown
  value stays raw. English lexicon: consigne → *target*, état
  cru → *believed state*, livraison → *delivery*, accusé → *ack*, relance
  du module → *module restart*, redémarrage de la carte → *reboot* (like
  the `reboot` command), désappairage → *unpairing*, voyant → *status
  LED*, tranche → *slice*, bail → *lease*, EN PANNE → *DOWN*. Case:
  sentence case in French; in English, *Title Case* for titles (screens,
  cards, sections, menus, buttons, alerts), sentence case for body text,
  row labels, checkboxes, and badges.

Catalogs (String Catalogs): `HaloProtocole/Localizable.xcstrings`
(framework: decoded meaning, labels, errors, session notes, with plurals),
`HaloCompagnon/Ressources/Localizable.xcstrings` (app), and
`HaloCompagnon/Ressources/Titres.xcstrings` (section titles whose French
text already serves as the label, with different English casing). Keys
are extracted by the compiler (`SWIFT_EMIT_LOC_STRINGS`): Xcode adds them
while building; from the command line, after a text change:

```sh
I=<DerivedData>/Build/Intermediates.noindex/HaloCompagnon.build/Debug
xcrun xcstringstool sync HaloProtocole/Localizable.xcstrings \
    --stringsdata $I/HaloProtocole.build/Objects-normal/arm64/*.stringsdata
xcrun xcstringstool sync HaloCompagnon/Ressources/*.xcstrings \
    --stringsdata $I/HaloCompagnon.build/Objects-normal/arm64/*.stringsdata
```

then translate the new keys. The tests (`LocalisationTests`) check that
every key has its English counterpart (complete plurals, matching
interpolated values), that none is stale, and that the code and the
catalogs are in sync. To test the whole app in the other language:
`xcodebuild ... test -testLanguage en -testRegion US`.

## Demo Mode

The "Demo Mode" source replaces the serial port with a simulated board
(`HaloCompagnon/Demo/`). It replays `HaloCompagnon/Ressources/demo-halo.jsonl`,
a 195 s timeline built from the examples in section 12:

| t | Event |
|---|---|
| 0 s | connection snapshot from 12.1, word for word (`hello`, `config`, `etat`, `compteurs`, `reseau`) |
| 6 s | Apple Home sets the brightness (`intent`, level 127), 3 packets acked, `livraison`, green status LED |
| 14 s | **remote's dial**: service frame, 26 `lum` frames and their acks, 2 bad CRCs |
| 22 s, 27 s | temperature dial, button A (3 copies of the same press) |
| 33 s | Matter: brightness and temperature, two slices delivered |
| 40-58 s | **lamp unplugged**: Matter command failing (5 MAX_RT per round, 3 rounds, `livraison` `abandon` `injoignable`, red status LED); your own commands fail too during this window |
| 64-66 s | an IDF log cuts a machine line in two (damaged line + fragment), two lines lost (a gap in `n`) |
| 74-84 s | the chip goes deaf (rearms outside RX), **module restart** `sourde` |
| 96-105 s | the Thread parent disappears (`thread` `detached`, subscription ended, orange status LED), then comes back |
| 116-150 s | TX delays on every command, three restarts without recovery, **`module` `panne`** (DOWN, solid red) |
| 176 s, 182 s | `module` `retabli`, then Apple Home turns the lamp off |

Periodic blocks are only written to the file when they change: the
simulated board re-emits them at the session's rate (`json periode`,
`json compteurs`, `json reseau`, `hb` if the link is down). It answers the
app's lines the way firmware 0.4.0 would: `json 1` (echo and human-mode
prompt beforehand), snapshot, `json ping`, a 30 s lease, `json etat`,
`json hello`, asynchronous `lampe` commands (`reponse`
`accepte`/`differe`/`usage`/`refuse`, 3 `tx`, `livraison` carrying the
`id`s, status LED), legacy commands (`reponse debut`, text, `reponse fin`),
`led test`, `lampe stats raz`, `reboot`. The app's commands override the
target and the counters until the next change coming from the file.

At the end of the timeline, the board "reboots": the stream closes like a
USB re-enumeration, the app reopens after 300 ms and sees a new `boot`
(states cleared, new chart segment), and the demo starts over.

File format (JSON-lines, ASCII): a machine line exactly as the board emits
it between RS and LF (object with `v`), or `{"texte": "...", "ms": N}`
(human text line), or `{"demo": "<directive>", "ms": N, ...}`
(`lampe_debranchee`, `lampe_rebranchee`, `ligne_coupee`, `saut_n`,
`entete`). The file is regenerated with `python3 Outils/generer_demo.py`;
the script checks that the first lines match the examples in 12.1 and that
its `brut` frames match those in 12.3 (a port of `encodeAir` and the CRC).

## Connecting to the Board (Section 3)

- `/dev/cu.*` port (never `/dev/tty.*`) opened with
  `O_RDWR | O_NOCTTY | O_NONBLOCK`, then `ioctl(TIOCEXCL)`: `pio device
  monitor` cannot attach to it at the same time.
- **DTR and RTS set to 0 in a single `ioctl(TIOCMSET)`** right after
  opening, and never touched again: never the RTS=1, DTR=0 state that
  restarts the C6. `HUPCL` removed (closing doesn't touch the lines),
  `cfmakeraw`, 8N1, `CLOCAL | CREAD`, 115200. Code:
  `HaloCompagnon/Serie/PortSerie.swift`.
- On opening: everything before the first LF is discarded, then
  `0x15 0x0A` and `id=<n> json 1`. With no `hello` within 2 s: three
  resends, then one attempt every 30 s ("download mode?").
  `Commande inconnue : "id=1"`: old firmware, console-only (lines with no
  `id`).
- The session is established on this attempt's `hello`, and the command
  queue only resumes at the `json 1`'s `reponse fin` (one command in
  flight at a time, 6.5). A response with no `hello` (hello lost or cut by
  a log, `ok:false`, `cadence`) establishes nothing: `json 1` goes out
  again 2 s later. A response lost after the `hello`: considered lost
  after 3 s, and the queue resumes.
- `json ping` after 10 s with no other command, or at a third of the lease
  if it's shorter (`json 1 bail 10` typed into the console); silence of
  3 × max(period, 2 s) (outside a bench command): `json 1`, then closing
  and reopening with no `hello` within 5 s. Before any `json 1` sent
  mid-session (silence, lease expired, restart), the in-flight command is
  marked lost; on restart, expected deliveries are too.
- Re-enumeration (restart, `reboot`, cable): IOKit reports ports leaving
  and arriving (`IOServiceAddMatchingNotification` on
  `IOSerialBSDClient`); the app reopens after 300 ms, then 1 s, 2 s, 5 s,
  and finds the same board again by its USB serial number (its MAC
  address). After 40 timed attempts (~3 min), it stops trying blindly but
  still reopens whenever the port comes back.
- **Release Port** (⇧⌘L, the ⏏ button): `json 0`, then closing once the
  tty's output queue is empty (`TIOCOUTQ`, 300 ms at most: the descriptor
  is `O_NONBLOCK` and closing would drop the rest), no reopening before
  "Reconnect": `pio run -t upload` can then flash it. "Disconnect",
  changing source, and quitting the app also send `json 0`, except during
  a bench command (the CLI stops reading).
- Port open: the app holds a `ProcessInfo` activity (no App Nap),
  otherwise the ping could miss the 30 s lease while the window is hidden.
- One command in flight at a time, at most 20 lines per second (50 ms
  between two lines, `cadence` refusal from 6.5); with no `reponse` within
  3 s: "no response", `json etat`, never a re-send. A `debut` (even
  arriving after this verdict) makes it a bench command: nothing goes out,
  neither ping nor a silence `json 1`, until its `fin`. Sliders: at most
  one command every 150 ms during the drag (queued values are merged), the
  final value on release.
- Console: at most 127 bytes including the prefix (judged with the longest
  possible `id`), printable ASCII, never JSON or RS; confirmation required
  for `reboot`, `decommission`, `erase`, `wifi`, `addr`, `chan`, `xo`,
  `debit`, `amble`, `aw`, `holtek`, `regcfg`, `lampe oublie`,
  `lampe adresse <x>`, `lampe stats raz`, `matter med|maxint|reprise auto`,
  `json cle efface`; `json 0` refused (use "Release Port" instead);
  `json cle nouvelle` refused (use the Thread and Matter card's "New
  key…" instead: the returned key has to go into the keychain); the key
  in `json cle` is masked everywhere it could be displayed (console, log,
  rejected lines, recent commands; any case and spacing, any run of 64 hex
  digits; inside a damaged line, a fragment, or an overflow, wherever a
  log might cut the key, also the `"cle":"` field with no closing quote,
  and any run of 16 hex digits or more), and it never enters the input
  history. Before the response to `json 1`, a typed line waits in the
  queue with its `id`.

### Sandbox: Yes, with `com.apple.security.device.serial` and `com.apple.security.network.client`

The app is sandboxed (`HaloCompagnon/HaloCompagnon.entitlements`) with two
entitlements, nothing else: `com.apple.security.device.serial`, the one
the spec calls for (3.1), for serial ports and the IOKit registry (read
access, allowed inside the sandbox; it covers `open`, `TIOCEXCL`,
`TIOCMSET`, and `termios` on `/dev/cu.*`); and
`com.apple.security.network.client`, for the network source (outgoing UDP
only; details, local network authorization, and signing in "Network
Source (UDP over Thread)" further below). Nothing else on disk is opened;
and the same app will be signable and distributable with no changes. If
the bench turned up a sandbox refusal on an `ioctl`, removing
`com.apple.security.app-sandbox` is enough (no code depends on the
sandbox).

## Network Source (UDP over Thread)

A second source reaches the bridge with no cable: UDP over Thread, through
Apple border routers (see `docs/PROTOCOLE-JSON.md`, section 10). Once
connected, the app shows the same screens as over USB, within the limits
of the bridge's allowlist and its remote profile. The `H1` envelope and
`TransportUDP` live in the `HaloProtocole` framework (`Reseau/`,
`Transport/TransportUDP.swift`), not in the app: their tests need a local
UDP peer, which a test hosted inside the app's sandbox does not allow.

**Creating the key (USB only).** The bridge only talks over the network if
it shares a key with this Mac. **Settings › Thread Network Access**,
"Bridge Plugged In over USB" section (the bridge connected over USB):
bridge with no key → "Enable network access…" button; bridge's key = this
Mac's key (same fingerprint) → "Key known to this Mac", with "New key…"
as an option; a different key → "Key unknown to this Mac" (in orange),
and the same button. The "Thread and Matter" card on the dashboard shows
this status read-only, with "Manage…", which opens this tab. The
confirmation warns that any network sessions in progress will drop. The
created key is stored in this Mac's keychain and never appears anywhere
else (console, log, command tracking): the command is shown without its
random value, and the response's `cle` field is masked everywhere the
line might be displayed. A response arriving after the 3 s USB timeout is
still stored; a creation interrupted by the transport closing is noted in
the console; a new attempt is only allowed once the previous one has
finished. Demo Mode simulates a "DEMO-HALO" bridge with its own in-memory
keychain, isolated from the real keychain, from the "Network" section,
and from the default source choice.

**Connecting.** Sidebar, source menu. "Serial Ports" only lists Espressif
boards (VID `303A`: no Bluetooth, no debug console, no displays), under
the board's name: its model, taken from its serial number (`id.serie`
`HALO1-<MAC>` from the `hello`, learned by MAC address on first
connection and kept in preferences; "ESP32" before that), then its MAC
address ("HALO1 · 58:E6:C5:66:5B:CE"), with the port path as subtitle
(`/dev/cu.usbmodem…`). "Network": clicking a known bridge connects to it
directly; same naming ("Halo Bridge" as long as the board has never been
seen), "`<nom>.local` · key XXXXXXXX" as subtitle. **Settings › Thread
Network Access** lists known bridges; "Forget…" removes a bridge's key
from this Mac's keychain after confirmation (the bridge keeps its own;
"Enable network access" over USB recreates one).

**What's allowed remotely.** The bridge applies its own allowlist
(section 10.5): `json 1/0/etat/hello/ping`, period settings within their
network bounds, `json trames`/`json log`, `lampe` commands, and
`led test|stop`. Everything else (`json cle...`, `reboot`,
`decommission`, `erase`, `wifi`, `matter ...`, the radio bench tools)
comes back `interdite`, nothing is executed; the board has the final say,
but the app also grays out these commands (Controls screen, bench tools)
with the reason as help text. The remote profile (section 10.6) applies
as soon as the network `json 1` happens: `etat` every 2 s, no
`compteurs`, `reseau` every 30 s, neither trames nor `log`. R3 (MAX_RT
with a remote client) is not measured: the app does not ask for any
faster rate for now.

**Errors and recovery.**

| Case | Banner / message | Recovery |
|---|---|---|
| Keychain missing or erroring, bridge without a key ("port unreachable", ICMPv6 `ECONNREFUSED`) | banner; "Reconnect" button in the sidebar panel | stopped: recreate or check the key over USB |
| Local network denied (System Settings › Privacy & Security › Local Network; macOS refuses to resolve `<nom>.local`: `NoSuchRecord` right away) | banner, held during retries | automatic, like the next row: a denied attempt never leaves the Mac, and the connection resumes on its own as soon as access is reauthorized |
| No IPv6 route (`EHOSTUNREACH`, `ENETUNREACH`, `ENETDOWN`), bridge not found (`<nom>.local` with no response within 5 s, or `EHOSTDOWN`: the node isn't responding), no DEFI (a different key, or a keyless bridge whose ICMPv6 never comes back), path lost mid-session ("Network connection lost: <cause>") | sidebar status line ("waiting: ...") and a note in the console; no banner | automatic: 0.3 s, 1 s, 2 s, 5 s (40 attempts), then on a network path change or when the Mac wakes |
| DEFI received, then no `hello` (two other sessions already active?) | "No answer to json 1 over the network…" banner | new handshake 30 s after the last `json 1`, and so on (see below) |

The same cause is logged only once in the console as long as it doesn't
change.

**No `hello` after the handshake.** The board first opens only a
provisional H1 session, which it forgets 30 s after the SALUT (or as soon
as another SALUT replaces it), and only establishes it on the first valid
message if it still has one of its two slots free
(`docs/PROTOCOLE-JSON.md`, 10.4). With no `hello`, `json 1` is resent with
the same `id` at 2, 4, and 6 s; at 8 s, the banner appears. 30 s after the
last `json 1`, the app does not resend `json 1` on a session the board
has forgotten: it closes and reopens the source (note "new handshake",
new name resolution, new SALUT, then `json 1`), and so on, roughly every
30 s; "Retry json 1" does the same right away. The banner persists from
one attempt to the next, its note is not repeated, and it clears on the
first `hello`.

**Closing.** "Disconnect", "Release Port", changing source, clicking the
already-connected bridge again, and quitting the app all send `json 0`
(sealed) before closing a session or an attempt in progress: its slot on
the board frees up right away. On a network source, "Release Port" has
nothing to flash: the note and the sidebar say "Network session closed",
and nothing reopens before "Reconnect".

The "No IPv6 route" message depends on Thread Route, the
`tools/macos/thread-route/` system helper (formerly halo-routes). The app
reads its status from macOS (`SMAppService.statusForLegacyPlist`, which the
sandbox allows), with every message and every time Settings opens (General,
Thread Route): active, the message says the route comes back on its own;
absent, or halo-routes still there, it points to
`sh tools/macos/thread-route/installer.sh`; turned off in System Settings,
it says to allow it there.

**Signing and local network authorization.** The network source requires
the `com.apple.security.network.client` entitlement and
`INFOPLIST_KEY_NSLocalNetworkUsageDescription` (French and English, via
`InfoPlist.xcstrings`). Signing with an Apple Development team is
necessary for this authorization and the keychain to stay stable from one
build to the next: see "Build, Test, Run".

**`halo_udp.py` and the keychain.** `tools/halo_udp.py` reads back the key
the app created, in this order: `HALO_CLE` (file); the keychain
(`security find-generic-password -s fr.djoko.halo.pont -a <nom> -w`; for
a plain address, the only bridge in the keychain, an error if there is
more than one; macOS asks once to authorize `security`, "Always Allow");
`~/.config/halo-pont/cle` as a last resort, with a warning on stderr (key
missing from the keychain, or access denied: this file may be stale; the
key is never displayed). Its `cle <port>` command (bench use without the
app) requires `HALO_CLE` and warns that the app's key then becomes stale.

`json cle nouvelle` typed into the console is refused, on any transport:
the board would change its key, but the returned key would not be stored
anywhere (use "New key…" instead). Limitation left aside for now: the
iOS app remains out of scope (phase 3).

## Architecture

```
apps/macos/
├── project.yml                  XcodeGen project (3 targets, 1 scheme)
├── HaloProtocole/               framework without AppKit or SwiftUI: the protocol, independent of transport
│   ├── Tramage/                 RS + JSON + LF over raw bytes (2.4), text classification (2.5)
│   ├── Messages/                one Codable per (t, block), tolerant enums (unknown case), decoder
│   ├── Commandes/                id=<n> lines (2.6), console rules and allowlist (6.4, 10.5), correlation (6.2-6.5)
│   ├── Session/                 session state machine (3.3-3.6): json 1, resends, old firmware, ping, silence, reboot, n continuity
│   ├── Etat/                    last snapshot of each (t, block), timestamping by ms and the hello anchor
│   ├── Courbes/                 section 8 calculations
│   ├── Correspondances/         Matter level <-> raw mapping (gamma), mireds <-> temp mapping (port of halo1_map.cpp)
│   ├── Interpretation/          decoded meaning and labels
│   ├── Localisation/            current language (observable), the language setting's choice, formatting locale
│   ├── Localizable.xcstrings    framework text (French source, English)
│   ├── Reseau/                  H1 envelope (EnveloppeH1, CryptoKit), ErreurReseau, CleReseau (10.4): pure code, tested without a network
│   └── Transport/                Transport protocol (open, send, close, byte stream); TransportUDP (UDP over Thread, section 10)
├── HaloProtocoleTests/          Swift Testing: framing, decoding of every example line from the spec, key coverage (no field lost), correlation, session, charts, mappings, demo file, catalogs and decoded meaning in both languages, H1 envelope and TransportUDP (local UDP peer)
├── HaloCompagnon/               the app
│   ├── Serie/                   PortSerie (POSIX, DTR/RTS), TransportSerie (DispatchSource), SurveillantUSB (IOKit)
│   ├── Demo/                    ScriptDemo, SimulateurDemo (actor), TransportDemo
│   ├── Modele/                  Pont (@Observable, main actor): connects transport, receiver, engine, state, logs; language setting; network source and key creation; updates (MisesAJour, Sparkle)
│   ├── Reseau/                  Trousseau (this Mac's session keychain, service fr.djoko.halo.pont), AlerteReseau (banner, "No IPv6 route" message), ThreadRoute (Thread Route status)
│   ├── Vues/                    the four screens, their components, Settings
│   └── Ressources/              demo-halo.jsonl, text catalogs (Localizable, Titres)
├── HaloCompagnonTests/          end-to-end on the simulated board (connection, delivered command, refusal, whole timeline sped up, restart, source change), app language
├── NOTES-VERSIONS.md            release notes, in French and English
└── Outils/                      generer_demo.py (demo timeline generator), publier.sh and publication.py (publishing a version, tests in Outils/tests)
```

The protocol layer is pure code: `RecepteurLignes`, `MoteurSession`, and
`Correlateur` are `struct`s that take the time as an argument and return
effects (send, reopen, restart detected...). `Pont` feeds them from the
transport and executes the effects. A transport is a `Transport`
(`HaloProtocole/Transport/Transport.swift`): the network source uses
`TransportUDP` (`HaloProtocole/Transport/TransportUDP.swift`, one
datagram = one line, `H1` envelope from `HaloProtocole/Reseau/`, section
10.4) without touching the rest; `PolitiqueCommandes.autoriseeADistance`
already applies the allowlist from 10.5. The iOS app (phase 3) will reuse
the same framework; to add it there, extend the `HaloProtocole` target's
platforms (it only imports Foundation, Observation, CryptoKit, Network,
dnssd, and Synchronization, all available on iOS).

## Interpretation Choices

- **Old lines**: whatever arrives before the session's `hello` is logged
  (in italics) but does not update the state (3.1, step 5).
- **Timestamping**: everything is timestamped by `ms`, mapped to the local
  time at the last `hello` (signed 32-bit difference, correct across
  `millis()` wraparound).
- **An RS earlier in a line** (the start of a machine line with no LF of
  its own): counted as a damaged line, never shown as text; the text
  before it remains text.
- **Delivery**: it covers every accepted command whose `id` does not
  exceed the largest of its `ids` (target merging, `ids_perdus`).
- **`id` numbers**: increasing over the app's whole lifetime, never reset
  to 1 on reconnection: the board's list of pending ids survives a
  reconnection, and a late `livraison` must not land on a new command
  with the same number.
- **Lost fin**: an `etat` or `hb` block received after a `reponse debut`
  proves the board's loop is running again (it emits nothing during a
  command): the command is closed as "lost fin" and the queue resumes.
- **Source change** (another port, demo): engine, `boot`, states, frame
  log, and charts all start over from zero (no false restart).
- **Charts**: a gap of more than max(30 s, 3 `compteurs` periods) between
  two blocks (app suspended, sleep) opens a new segment, just like a
  `raz`; the flood threshold is `deluge_trames` × `deluge_pct`% bad CRC
  per `fenetre_ms` (540 per minute at the default values), as in
  `halo1_watch.cpp`.
- **Capabilities** (`hello.caps`, 5.1): status LED test with no `led`,
  `json trames` with no `trames`, `json log` with no `log`, and Thread and
  Matter cards with no `matter` are not offered; with no `lampe_async`,
  the Controls screen warns that every `lampe` command blocks the board.
- **Restart** seen outside a `hello` (`etat`, `hb`): `json 1` is resent;
  seen in the `hello` of a new connection: states cleared only.
- **Required fields**: the envelope (`v`, `t`, `n`) and, per message,
  whatever carries the meaning (`reponse`: `id`, `etape`, `ok`, `code`;
  `etat.lampe`: `consigne`, `cru`; `rx.type`, `tx.verdict`,
  `livraison.issue`...); everything else is optional, and a `null`
  invalidates nothing.

## To Verify on the Bench (App Side)

- **U1, U2**: 50 open-close cycles by the app, `boot` unchanged and `up_s`
  continuous (the dashboard shows them; a restart shows up as a marker).
- **U3**: `reboot` from the console (confirmation): re-enumeration,
  reconnection in under 5 s, `hello` with `reset` `logiciel`.
- **U4**: `chiplog` active: damaged lines and fragments show up in
  "Serial Link Health", with no wrong value displayed.
- **U5**: Mac asleep or app suspended for 60 s: fragments classified as
  such on wake (`NSWorkspace.didWakeNotification`), lease expired then
  `json 1` resent.
- The sandbox against `PortSerie`'s `ioctl`s (`TIOCEXCL`, `TIOCMSET`).
- **Network key**: app connected over USB, Settings › Thread Network
  Access → "Enable network access…" → "Key XXXXXXXX known to this Mac";
  then `python3 tools/halo_udp.py session <nom SRP>.local --duree 10`
  (macOS asks to authorize `security`: "Always Allow") → session opens
  with the app's key.
- **Network source**: "Release Port", then the source menu → "Network"
  section → connect (local network authorization the first time) →
  `hello` rev 4 transport `udp`, `etat` every 2 s; `lampe niveau 200`
  from the app, delivered; `lampe stats raz` grayed out.
- **R5**: restart the bridge (USB: `reboot`, from the app or
  `pio device monitor` with no `json cle`) → the app recovers on its own
  within ~15 s. Seen on Sep 25 (power outage): 4.5 s after plugging back
  in.
- **First local network authorization**: on a Mac where the app has never
  yet joined the local network, first network connection → macOS prompt;
  note what the app shows during the prompt, then click "Allow": does the
  app recover on its own (does the `NWPathMonitor` path monitor call back
  on the authorization change?), or is "Reconnect" needed? Seen on
  Sep 25: the prompt did appear on the first connection.
- **R7**: System Settings › Privacy & Security › Local Network: turn off
  Halo Compagnon → an open session keeps going (the flow routed to the
  bridge's ULA isn't cut); "Reconnect" → "Local network access denied…"
  banner, retrying in the background; re-authorize → recovers on its own
  within 1 to 2 s. Seen on Sep 25: no banner, "Bridge not found" instead
  (fixed).
- **Network source debug log** (connection states, paths, raw
  Network.framework errors): quit the app, then
  `open --env HALO_DEBUG_RESEAU=1 --stderr /tmp/halo-udp.log "<chemin>/Halo Compagnon.app"`.
  Launch it with `open`, not from the shell: that way macOS grants local
  network authorization to the app, not to the terminal.
- **Route**: remove the static IPv6 route to the OMR prefix → sidebar
  status line "No IPv6 route…" (no banner) and a console note, "Transport
  closed: Network connection lost: …" if a session was open; then
  recovery by the `tools/macos/thread-route` helper (log
  `/Library/Logs/fr.djoko.thread.route.log`). Note the errno seen: the
  message states it ("No IPv6 route": `EHOSTUNREACH`, `ENETUNREACH`, or
  `ENETDOWN`; "Bridge not found": `EHOSTDOWN` or a resolution failure);
  `python3 tools/halo_udp.py refus <adresse OMR> 5480` shows the raw
  errno. Seen on Sep 25: one socket gets `EHOSTUNREACH`, the app gets
  `ENETDOWN` (Network.framework); **an open session keeps going with no
  route** (its flow keeps its existing next hop): only new connections
  fail. Helper active: a 0.3 s gap, nothing visible. To see the status
  line, stop the helper (`sudo launchctl bootout
  system/fr.djoko.thread.route`: it removes its routes on the way out),
  then "Disconnect" and "Reconnect"; restart it (`sudo launchctl bootstrap
  system /Library/LaunchDaemons/fr.djoko.thread.route.plist`): recovery 8 s
  after the route came back on Sep 25, at most one reconnection delay
  since then (a connection with no route gives up right away).
- **Bridge without a key**: `json cle efface` over USB, then a network
  connection → "No answer from the bridge…" (no DEFI) in the status
  line, with automatic recovery: seen on Sep 25, the keyless bridge stays
  silent (the port is still held by OpenThread: neither ICMPv6 nor
  `ECONNREFUSED`, `refus` returns DELAI just as with a key), and "The bridge has no key anymore…" does not appear with this firmware. Then
  recreate the key (Settings › Thread Network Access): macOS asks again
  for keychain access for `security` on the first read by `halo_udp.py`
  ("Always Allow"; with no response, the prompt expires and
  `halo_udp.py` falls back to `~/.config/halo-pont/cle`, and says so).
- **Three clients**: two sessions already open (two
  `python3 tools/halo_udp.py session <nom SRP>.local --duree 300`), then
  the app → DEFI but no `hello` (verdict `complet` on the board side,
  `udp.rejets` climbs): "No answer to json 1 over the network…" banner at
  8 s, then a "new handshake" note roughly every 30 s, banner steady, its
  note only once; stop one of the `halo_udp.py` instances (Ctrl-C:
  `json 0`) → `hello` on the next attempt, banner cleared. Then a new
  click on the already-connected bridge: `json 0` first, the new session
  gets its `hello` without waiting for the old one's 30 s of silence (the
  remaining `halo_udp.py` keeps its slot). Seen on Sep 25 (firmware
  rev 3): handshake redone every 36.5 s; `json 0` didn't free the slot
  (`hello` 43 s later, once the departed session had been silent for
  30 s); fixed in rev 4 (R9: `hello` 1 s after a client's `json 0`, seen
  on Sep 27). A `halo_udp.py` launched in the background by a script
  ignores Ctrl-C (SIGINT ignored outside a terminal): launch it in a
  terminal instead.
- **Release Port** on the network source: note "Network session closed:
  json 0 sent…", sidebar status "Network session closed (json 0)",
  nothing reopens before "Reconnect". Seen on Sep 25: as expected.
- **Status LED (U11, rev 4)**: the app's status LED white glow and the
  board's, at the same time, over USB and over the network, including
  after a green flash (`lampe` command) and after `led test`. Seen on
  Sep 27: in sync.
- **Source menu**: only Espressif boards, "HALO1 · MAC" with the
  `/dev/cu.…` path as subtitle; network bridge under the same name;
  Settings › Thread Network Access: known bridges, "Forget…", the
  plugged-in bridge's key; the Thread card's "Manage…" opens this tab.
  Seen on Sep 27: as expected.
- **`cc` with the BM5602 plugged in** (firmware): refused with its
  explanation, the board no longer crashes (reported and verified on
  Sep 27).

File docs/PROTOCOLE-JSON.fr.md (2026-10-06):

**Français** · [English](PROTOCOLE-JSON.md)

# Protocole JSON du pont Halo (v1)

Specification du protocole machine entre le firmware (ESP32-C6, env produit
`esp32c6thread`, env de banc `esp32c6diag`) et l'application de supervision :
d'abord l'app macOS native SwiftUI (`apps/macos/`, liaison USB), plus tard
l'app iOS par le reseau (Thread -> routeur de bordure Apple -> LAN). Le meme
protocole sert aux deux : seuls le transport et l'authentification changent.

Etat : IMPLEMENTE dans le firmware 0.4.0 (transport USB valide au banc le
24/09 ; transport reseau, section 10, valide au banc le 25/09 : R1 et une
partie de R2, voir 10). Les marques **(a ajouter)** datent de la
specification : les champs concernes existent desormais.
Chaque champ cite sa source dans le code (`fichier : symbole`), pour que
l'implementation n'invente rien.

## 0. Decisions en bref

| Sujet | Decision |
|---|---|
| Tramage | Une ligne machine = octet RS (0x1E) + un objet JSON compact en ASCII + LF. Au plus 1024 octets, RS et LF compris (budget de pire cas : 896). Tout le reste du flux est du texte humain ou des logs, affiches tels quels par la console. |
| Sens app -> carte | Lignes de texte de la CLI existante, prefixees `id=<n> ` pour la correlation. Pas de JSON vers la carte. |
| Session | `json 1` (mode machine, avec bail de 30 s renouvele par `json ping`), `json 0`, `json etat`. Rien n'est persiste : chaque demarrage repart en mode humain. |
| Reponses | Toute ligne portant un `id` recoit un message `reponse` (etape `fin`, precedee d'une etape `debut` pour les commandes historiques). Les commandes d'etat de la lampe portant un `id` deviennent asynchrones : `reponse` tout de suite, `livraison` ensuite. |
| Etat periodique | `etat` (1 Hz), `compteurs` (1 Hz), `reseau` (0,2 Hz), chacun en plusieurs blocs d'une ligne. Les evenements (`rx`, `tx`, ...) sont des indices ; la verite est l'instantane periodique. |
| Compatibilite | Version majeure `v` dans chaque ligne ; ajouts sans changer `v` ; l'app ignore champs, types et valeurs inconnus. |
| Reseau (0.4.0, build Thread) | Memes messages en datagrammes UDP sur l'IPv6 Thread (port 5480, nom d'hote SRP du noeud), cle partagee + HMAC-SHA256 (enveloppe H1), liste blanche de commandes a distance (section 10). |

## 1. Vocabulaire et principes

- **consigne** : l'etat voulu par Matter, la CLI ou l'app (`Halo1Lamp::target()`).
- **etat cru** : ce que le pilote croit de la lampe (`Halo1Lamp::believed()`).
- **carte** : l'ESP32-C6 et son firmware ; **app** : le client (macOS, iOS).
- **ligne machine** : une ligne RS + JSON (section 2) ; **texte** : toute autre ligne.
- **transport** : le port serie USB (v1), UDP sur Thread (section 10).

Principes :

1. **La carte n'attend jamais l'app.** Une ligne machine qui ne tient pas dans le
   tampon d'emission est perdue et comptee, comme les traces du pilote
   (`Halo1Lamp::trace`, `Halo1Lamp::notice` : `Serial.availableForWrite()`).
2. **Un seul producteur.** Toutes les lignes machine sont formatees et ecrites
   dans la tache loop (celle de `loop()`, `tick()` et de la CLI). Les rappels
   de la tache CHIP et de la tache des evenements IDF ne font que poser des
   compteurs, comme aujourd'hui (`matter_bridge.cpp : post`, `sSubMux`) ; la
   tache loop les traduit en messages.
3. **L'etat est periodique, les evenements sont des indices.** Une ligne perdue
   ou abimee ne fausse rien durablement : l'instantane suivant corrige. L'app
   ne reconstruit jamais un etat en cumulant des evenements.
4. **Rien de nouveau ne part vers la lampe** a cause du protocole : l'app passe
   par les memes consignes que Matter et la CLI (`Halo1Lamp::request`,
   `resolveMatter`).

## 2. Tramage sur le port serie partage

### 2.1 Ce qui circule sur le port

Le port USB CDC du C6 (USB Serial/JTAG, `HWCDC`) porte deja, entremeles :

| Source | Forme | Exemple |
|---|---|---|
| Sorties des commandes de la CLI | texte francais ASCII, lignes CRLF | `  consigne : allumee deux lum A5 temp 35 (a livrer : -)` |
| Echo des caracteres tapes, invite | caracteres isoles, `> ` sans fin de ligne | `> lampe` |
| Annonces du pilote et du pont | `[lampe] ...`, `[matter] ...` (`Halo1Lamp::notice`, `trace`, `bridgeLog`) | `[lampe] injoignable : consigne abandonnee` |
| Logs ESP-IDF (autres taches) | `E (12345) tag: ...` ; console secondaire USB Serial/JTAG (`CONFIG_ESP_CONSOLE_SECONDARY_USB_SERIAL_JTAG=y`), niveau par defaut ERROR, sans couleurs (`CONFIG_LOG_COLORS` absent) | `E (48213) chip[DL]: ...` (avalees par `quietVprintf` tant que `chiplog` est coupe) |
| Logs du core Arduino | `[ 1234][E][fichier.cpp:12] fonction(): ...` | |
| Banniere de demarrage, ROM | `=== BenQ ScreenBar Halo -> Matter ===`, `ESP-ROM:esp32c6-...` | rarement vues : le port se re-enumere au redemarrage |

Deux chemins materiels differents ecrivent dans la meme FIFO USB : le tampon
circulaire de `HWCDC` (4096 octets, `Serial.setTxBufferSize(4096)` dans
`setup()`) et la console secondaire d'IDF, qui ecrit directement dans la FIFO
depuis n'importe quelle tache. **Un log IDF peut donc s'intercaler au milieu
d'une ligne machine.** Le tramage ne l'empeche pas : il le rend detectable.

### 2.2 La ligne machine

```
RS  JSON  LF
0x1E {"v":1,"t":"etat","n":42,"ms":61234,...} 0x0A
```

Regles (toutes obligatoires pour la carte) :

1. Elle commence par l'octet **RS (0x1E)**, suivi immediatement de `{"v":`.
   RS n'apparait dans aucune autre sortie de la carte, d'IDF, du core ou de la
   ROM (les couleurs ANSI utilisent ESC, 0x1B). L'idee vient des sequences de
   textes JSON (RFC 7464), sans en reprendre l'exclusivite : ici, du texte
   circule entre les lignes machine.
2. Un seul objet JSON, **compact** (aucun espace hors des chaines), sur une
   seule ligne, termine par **LF (0x0A)** seul. Jamais de CR dans la ligne
   (le texte humain de la CLI finit en CRLF : l'app tolere un CR final).
3. **ASCII imprimable seulement** (0x20 a 0x7E) entre RS et LF. Dans les
   chaines, `"` et `\` sont echappes (`\"`, `\\`) ; tout octet hors de
   0x20..0x7E est remplace par `?`. Aucune sequence `\uXXXX` n'est emise.
4. **Longueur maximale : 1024 octets, RS et LF compris.** Budget de pire cas
   en v1 (tous les compteurs a 4294967295, toutes les chaines a leur taille
   maximale) : **896 octets** par message, pour laisser 128 octets aux ajouts
   de 9.1 ; un message qui approcherait le budget gagne un bloc (`bloc`),
   jamais de longueur. Plus de 1024 octets reste un bogue : non emis, compte
   (`json_trop_longs`, voir `etat.sante.sys`).
5. Les quatre premiers champs sont toujours `v`, `t`, `n`, `ms`, dans cet
   ordre, puis `bloc` pour les messages en blocs (`hello`, `etat`,
   `compteurs`, `reseau`). L'app ne doit pas en
   dependre (voir 2.4), mais cela aide a lire une capture.

Pourquoi RS plutot qu'un prefixe imprimable ou `{"v":1` en debut de ligne :
une ligne machine peut arriver apres un reste de texte sans fin de ligne (la
fin d'un log coupe, ou l'invite `> ` d'une session humaine) ; avec RS, l'app la
retrouve n'importe ou dans la ligne. RS est invisible dans `pio device monitor`
et dans un terminal : la ligne y reste lisible.

### 2.3 Emission cote carte

- Formatage dans un tampon statique de 1024 octets, puis **un seul appel**
  `Serial.write(buf, len)` : `HWCDC::write` tient son verrou (`tx_lock`) pour
  tout l'appel, donc aucune autre ecriture Arduino ne s'intercale.
- Avant d'ecrire : `Serial.availableForWrite() >= len`, sinon la ligne est
  perdue et comptee (`json_perdus`). Jamais d'ecriture partielle, jamais
  d'attente : avec `setTxTimeoutMs(1000)`, un `HWCDC::write` sur un hote qui ne
  lit plus peut bloquer jusqu'a 20 x 1000 ms (core 3.3.12, `max_consec_timeouts`).
- Lignes periodiques : au plus **une par tour de `loop()`**, et seulement s'il
  reste ensuite au moins 1024 octets libres (la place d'un evenement). Sinon
  reportee au tour suivant ; perdue (comptee) apres 500 ms de retard. Les
  instantanes complets (`json 1`, `json etat`, `json hello`) passent par cette
  file : ~4,6 Ko au pire pour `etat`, `compteurs` et `reseau` (~5,4 Ko avec
  le bloc `ip` du build Thread), ~6,3 Ko avec `hello` et `config` (~7,1 Ko),
  plus que les 4096 octets du tampon de `HWCDC` ; ecrits d'un seul trait, des
  lignes seraient perdues a chaque `json 1`. Chaque transport a sa file (une
  ligne par tour et par transport) ; sur le reseau, la place d'un evenement
  est un datagramme libre dans la file d'emission, et le retard admis 6 s.
- Evenements : ecrits tout de suite s'ils tiennent, sinon perdus (comptes).
- Le texte que le protocole emet lui-meme (fin de bail, invite apres `json 0`)
  prend le meme chemin non bloquant (3.5, 3.8).
- `n` est incremente pour chaque ligne **produite**, qu'elle soit ecrite ou
  perdue : un trou dans `n` signale une perte, cote carte (`json_perdus`) ou
  sur le fil (ligne abimee, voir 2.4).
- Jamais de formatage ni d'ecriture sous la garde d'antenne
  (`Halo1Radio::sendOne`, verrou OpenThread tenu), sous un verrou OpenThread
  ou de la pile CHIP, ni dans une section critique (`sSubMux`, `sInboxMux` :
  `portENTER_CRITICAL` masque les interruptions sur ce C6 mono-coeur). Les
  evenements `tx` se forment apres le verdict ; `sSubs`, `sResume`, `sRoles`
  sont copies sous `sSubMux` puis formates (comme `tracePoll`). Ordre des
  verrous du pont (`matter_bridge.cpp`) : jamais celui de la pile pris en
  tenant celui d'OpenThread (la tache CHIP prend OpenThread en tenant le sien).
  Un seul tampon statique : aucun formatage ne doit en appeler un autre.

### 2.4 Reception cote app

Algorithme (sur des octets bruts : aucun decodage de caracteres avant d'avoir
separe texte et JSON) :

```
tampon += octets lus
si le tampon depasse 2048 octets sans LF : le vider comme texte, compter "debordements"
pour chaque ligne terminee par LF (0x0A) :
    retirer un CR final eventuel
    i = position du DERNIER RS (0x1E) de la ligne
    si i absent :
        si la ligne finit par '}' et suit une ligne machine abimee
           (ou est la premiere lue apres une pause de lecture de l'app : veille
           du Mac, app suspendue) :
            fragment -> compter "fragments", filtre "logs systeme" seulement
        sinon :
            ligne texte -> console (decodage UTF-8 avec remplacement, jamais d'echec)
    sinon :
        avant = ligne[0..i[  -> si non vide apres retrait des espaces : texte
        json  = ligne[i+1..]
        si len(json) > 1022, ou json ne commence pas par '{"v":',
           ou ne finit pas par '}', ou n'est pas un objet JSON valide,
           ou v/t/n absents ou mal types :
            compter "lignes_abimees", ignorer (ne PAS l'afficher comme texte)
        sinon si v n'est pas une version geree : compter "versions_inconnues", ignorer
        sinon : distribuer selon t (type inconnu : ignorer)
```

Le **dernier** RS : si une ligne machine a ete coupee par un log sans que son
LF passe, sa suite peut contenir un RS valide.

Une ligne machine coupee laisse sa suite sur la ligne suivante, sans RS : un
log IDF ecrit directement dans la FIFO entre deux paquets de 64 octets, ou
`flushTXBuffer` qui jette les octets les plus anciens (le debut d'une ligne)
quand l'hote ne lit plus. C'est un fragment, jamais du texte de commande.

Controle de continuite : pour chaque transport, l'app garde le dernier `n`
recu. `n` qui saute : pertes (compter `n_nouveau - n_attendu`). `n` qui
recule : redemarrage de la carte (le confirmer par `boot`, voir 3.6) ou
lignes anciennes (voir 3.1, tampon a l'ouverture).

### 2.5 Ce que l'app classe et ignore

Lignes texte (hors RS) :

| Motif (apres retrait des sequences ANSI `ESC [ ... lettre`) | Classe | Traitement |
|---|---|---|
| `^[EWIDV] \(\d+\) [^:]+: ` | log IDF | console, filtre "logs systeme" ; niveau = premiere lettre |
| `^\[\s*\d+\]\[[EWIDV]\]\[` | log du core Arduino | idem |
| `^\[(lampe\|matter)\] ` | annonce du firmware | console ; en mode `json log 1` elles arrivent en `log` et ne passent plus ici |
| `^ESP-ROM:`, `^rst:0x`, `^boot:0x`, `^=== BenQ ScreenBar Halo` | demarrage | console, et indice de redemarrage (voir 3.6) |
| `^> ?$` | invite de la CLI (mode humain) | ignoree |
| autre | texte de commande | console, rattache a la commande en cours (voir 6.4) |

L'app ne tire **aucune** information d'etat du texte : seulement des lignes
machine. Le texte sert a la console et au journal.

### 2.6 Sens app -> carte

- Lignes ASCII imprimables (0x20..0x7E), terminees par LF ; un CR avant LF est
  ignore par la CLI (`cliPoll` : `if (c == '\r') continue`).
- **127 octets au plus**, prefixe `id=` compris : le tampon de la CLI fait 128
  octets (`cli.cpp : buf[128]`) et tronque aujourd'hui EN SILENCE au-dela.
  En v1 la carte refuse une ligne trop longue (`reponse` code `trop_long`,
  rien n'est execute) **(a ajouter)**.
- Jamais d'octet RS ni de JSON vers la carte.
- Octet 0x15 (Ctrl-U) : vide la ligne en cours de saisie **(a ajouter)**.
  L'app l'envoie a l'ouverture du port (voir 3.3) pour effacer un reste de
  ligne laisse par une session precedente, qui serait sinon execute.
- Le tampon de reception de `HWCDC` fait 256 octets (`setRxBufferSize(256)`
  dans `HWCDC::begin`) : pendant une commande bloquante, deux lignes au plus
  peuvent y attendre. D'ou la regle d'une commande en vol (6.5). Au-dela de
  256 octets en attente, l'ISR de `HWCDC` jette l'excedent sans rien dire
  (`xQueueSendFromISR` refuse) : une ligne amputee de son LF se recollerait a
  la suivante ; le `0x15` en tete de chaque tentative de connexion (3.3)
  efface un tel reste.
- En mode machine, la carte ignore tout octet recu hors 0x20..0x7E, sauf LF,
  CR, 0x15 et retour arriere **(a ajouter)**, pour que
  `Commande inconnue : "%s"` ne renvoie jamais un RS.

## 3. Session

### 3.1 Ouverture du port (macOS, C6 USB natif)

Le C6 expose l'USB Serial/JTAG : VID:PID `303A:1001`. Le debit (115200) est
ignore par ce peripherique ; l'app le regle quand meme (une variante a pont
UART, comme `esp32dev`, en a besoin : voir 9).

1. Ouvrir `/dev/cu.usbmodem*` (jamais `/dev/tty.*`, qui attend DCD) en
   `O_RDWR | O_NOCTTY | O_NONBLOCK`, puis `ioctl(TIOCEXCL)` : acces exclusif,
   `pio device monitor` ne pourra pas s'y attacher en meme temps. App
   macOS sandboxee : droit `com.apple.security.device.serial`.
2. `cfmakeraw`, 8N1, `CLOCAL | CREAD`, **`HUPCL` retire**, 115200.
3. **DTR et RTS** : voir 3.2. Recommande : les deux a 0 dans un seul
   `ioctl(TIOCMSET)` juste apres l'ouverture, et ne plus y toucher.
4. Resynchronisation : jeter tout ce qui precede le premier LF recu.
5. **Lignes anciennes** : quand l'hote ne lisait plus, `HWCDC` a pu garder
   jusqu'a 4 Ko de sortie (et, cable debranche, il remplace les plus
   anciennes : `flushTXBuffer`). Elles arrivent en premier. L'app date tout
   avec `ms` (et `boot`), jamais avec l'heure d'arrivee, et considere comme
   historique ce qui precede la reponse a son `json 1`.
6. Ouvrir le port **ne redemarre pas** la carte si les regles de 3.2 sont
   tenues. En revanche, tout redemarrage de la carte (`reboot`, panique, chien
   de garde, bouton) **re-enumere l'USB** : le noeud `/dev/cu.*` disparait
   (lecture en erreur ou EOF) puis revient, souvent sous le meme nom. L'app
   surveille l'arrivee de `303A:1001` (IOKit, `IOServiceAddMatchingNotification`
   sur `IOSerialBSDClient`) et rouvre, avec un delai de 300 ms puis 1 s, 2 s,
   5 s. Le numero de serie USB du peripherique est l'adresse MAC de la puce :
   il permet de retrouver la meme carte parmi plusieurs (a confirmer au banc).
7. Un flash (`pio run -t upload`) echoue tant que l'app tient le port
   (`TIOCEXCL`) : l'app offre "Liberer le port" (envoie `json 0` et ferme ;
   DTR et RTS sont deja a 0) et ne rouvre pas avant un clic.
8. Carte en mode telechargement (apres un flash rate, ou BOOT tenu) : meme
   VID:PID, mais la ROM ne parle que le protocole d'esptool. Aucun `hello` :
   l'app l'annonce ("aucune reponse : carte en mode telechargement ?").

### 3.2 DTR et RTS : le piege du C6

Le peripherique USB Serial/JTAG interprete DTR et RTS comme esptool les
utilise, sans aucun cablage : d'apres le manuel technique (chapitre USB
Serial/JTAG, table "CDC-ACM Settings with RTS and DTR", a relire dans sa
derniere version) et la sequence `USBJTAGSerialReset` d'esptool :

| RTS | DTR | Effet |
|---|---|---|
| 0 | 0 | aucun (efface l'indicateur de mode telechargement) |
| 0 | 1 | pose l'indicateur de mode telechargement |
| 1 | 0 | **REDEMARRE LA PUCE** (en mode telechargement si l'indicateur est pose) |
| 1 | 1 | aucun |

Consequences pour l'app :

- **Jamais l'etat RTS=1, DTR=0, meme un instant.** Un programme qui change
  DTR et RTS par deux appels separes (proprietes `rts`/`dtr` d'une
  bibliotheque, par exemple ORSSerialPort) peut y passer. Toujours
  `ioctl(fd, TIOCMSET, &bits)` avec les deux bits a la fois.
- A la fermeture, un pilote qui baisse DTR avant RTS (`HUPCL`) passe par
  RTS=1, DTR=0 : c'est le redemarrage "a la fermeture du terminal" rapporte
  sur C3 (esp-idf, issue 13075). D'ou : `HUPCL` retire, et DTR = RTS = 0 des
  l'ouverture (passage direct 1,1 -> 0,0), de sorte que la fermeture ne
  change rien.
- `HWCDC` ne conditionne pas l'emission a DTR (connexion jugee sur les trames
  SOF et la releve de la FIFO : `HWCDC::isCDC_Connected`) : DTR a 0 ne coupe
  pas le flux.
- Le registre `USB_SERIAL_JTAG_CHIP_RST_REG` a un bit `USB_UART_CHIP_RST_DIS`
  qui coupe ce redemarrage cote puce ; il couperait aussi le reset automatique
  d'esptool (flash) et un fil du forum Espressif le dit inoperant sur C6 face a
  DTR. **Non retenu** ; a n'essayer qu'au banc.

A confirmer au banc avant de s'y fier (tests U1 et U2, section 11) : 50
ouvertures-fermetures de l'app et de `pio device monitor`, `boot` inchange et
`up_s` continu.

### 3.3 Sequence de connexion

```
App                                                  Carte
ouvre le port, DTR=RTS=0, jette jusqu'au 1er LF
envoie 0x15 0x0A  ---------------------------------> ligne en cours videe, ligne vide ignoree
envoie "id=1 json 1\n" ----------------------------> mode machine : echo et invite coupes
                  <--------------------------------- hello (base, identite)
                  <--------------------------------- config
                  <--------------------------------- etat (lampe, tranches, sante)
                  <--------------------------------- compteurs (pilote, radio, matter)
                  <--------------------------------- reseau (thread, abonnements, ip)
                  <--------------------------------- reponse id=1 fin ok
... puis etat + compteurs chaque seconde, reseau toutes les 5 s, evenements
envoie "id=k json ping\n" apres 10 s sans autre commande
```

Les lignes qui suivent `json 1` passent par la file des periodiques (2.3), une
par tour de `loop()` ; la `reponse` part apres la derniere.

Sans `hello` 2 s apres `json 1` : renvoyer (3 fois). Puis :
- texte `Commande inconnue : "id=1". Tape 'help'.` recu (l'ancien firmware
  lit `id=1` comme nom de commande ; motif `^Commande inconnue : "id=\d+"`) :
  firmware sans protocole JSON ; l'app reste en console seule et le dit
  ("flasher >= 0.4.0") ;
- rien du tout, ou du texte sans `hello` : mauvais port, mode telechargement,
  ou commande de banc en cours lancee par une session precedente ; l'app
  reste a l'ecoute et renvoie `\x15\n` puis `json 1` toutes les 30 s, pas
  plus souvent : pendant une commande de banc la CLI ne lit plus, chaque envoi
  s'empile dans les 256 octets de reception (2.6), et chaque `json 1` en file
  serait execute a la sortie (instantane complet a chaque fois).

### 3.4 La commande `json`

Nouvelle famille de la CLI **(a ajouter)**, dans `cli.cpp : handleLine`. Tout
est en RAM (voir 3.7). `json` rejoint la liste `radioFree` (`cli.cpp :
kFree`), et le prefixe `id=` est retire AVANT ce test : sinon chaque ligne de
l'app (`id=17 ...`, premier mot `id=17`) et chaque `json ping` (toutes les
10 s) ferait `lamp.settleRadio()` (jusqu'a 200 ms) puis
`lamp.invalidateRadio()`, soit une reconfiguration complete du BM5602 et
`ChipWatch::forget()`, qui efface la serie de delais, la fenetre de 10 s du
deluge et celle de la surdite : la relance automatique L2 serait retardee, ou
empechee pour un deluge qui met plus de 10 s a atteindre son seuil.

| Commande | Effet | Bornes |
|---|---|---|
| `json` | etat de la session, en texte humain | |
| `json 1 [bail <s>]` | passe en mode machine sur ce transport : echo et invite coupes, reglages de session remis aux valeurs par defaut, puis `hello`, `config` et l'instantane complet par la file des periodiques (~6,3 Ko au pire), la `reponse` `fin` apres la derniere ligne. Idempotent : renvoyer `json 1` resynchronise. | bail 0 (aucun) ou 10..600 s, defaut 30 |
| `json 0` | retour au mode humain : message `fin`, puis l'invite `> ` ; par le reseau, la place de la session revient aussi au client suivant (rev 4, 10.4) | |
| `json etat` | instantane complet : `etat` (3 blocs), `compteurs` (3 blocs), `reseau` (2 blocs, 3 en build Thread), places dans la file des periodiques (une ligne par tour de `loop()`, 1024 octets libres apres, 2.3) ; la `reponse` `fin` part apres la derniere ligne. Pire cas cumule ~4,6 Ko (~5,4 Ko en build Thread), plus que le tampon de 4096 octets de `HWCDC` : jamais d'un seul trait. Marche aussi en mode humain (une fois). | |
| `json hello` | `hello` (2 blocs) et `config`, par la meme file. Marche aussi en mode humain. | |
| `json ping` | renouvelle le bail ; la `reponse` porte `bail_s` et `up_s` | |
| `json periode <ms>` | periode des `etat` | 0 (coupe) ou 200..60000, defaut 1000 |
| `json compteurs <ms>` | periode des `compteurs` | 0 ou 200..60000, defaut 1000 |
| `json reseau <ms>` | periode des `reseau` | 0 ou 1000..60000, defaut 5000 |
| `json trames 0\|1` | evenements `rx` et `tx` | defaut 1 |
| `json log 0\|1` | annonces et traces du firmware en messages `log` au lieu de texte | defaut 0 |
| `json cle [nouvelle <64 hexa>\|efface]` | cle du transport reseau (section 10.4), USB seulement ; `nouvelle` exige un `id` (la cle part dans la reponse) | build Thread ; ailleurs `refuse` |

Reglages par transport : l'USB et chaque abonne reseau ont les leurs.

### 3.5 Bail et ping

L'app peut disparaitre sans envoyer `json 0` (plantage, veille du Mac, cable
tire, `kill`). Sans garde-fou, la carte continuerait d'emettre pour personne,
et un humain qui ouvrirait ensuite `pio device monitor` recevrait du JSON.

- La carte date le dernier octet recu du transport et la fin de la derniere
  commande executee ; le bail court depuis le plus recent des deux (une
  commande de banc de 60 s ne fait donc pas expirer le bail a sa sortie).
- Bail echu : retour au mode humain, message `fin` (`cause` : `bail`), puis
  la ligne de texte `json : mode machine coupe (hote muet depuis 30 s)` et
  l'invite, ecrites par le meme chemin non bloquant que les lignes machine
  (`availableForWrite()` d'abord, sinon perdues et comptees) : l'hote est
  justement muet, et un `Serial.println` bloquerait `loop()` jusqu'a
  20 x 1000 ms.
- L'app envoie `id=<n> json ping` apres 10 s sans autre commande. Au banc,
  un humain qui tape `json 1 bail 0` garde le mode machine jusqu'a `json 0`
  ou au redemarrage.

### 3.6 Battement, silence, redemarrage

- Les blocs `etat` servent de battement. Si `periode_ms` vaut 0 ou plus de
  2000, la carte emet un `hb` toutes les 2000 ms.
- **Silence** : aucune ligne (machine ou texte) depuis 3 x max(periode, 2 s),
  hors commande en vol (6.5). L'app renvoie `json 1` ; sans reponse sous 5 s,
  elle ferme et rouvre le port.
- **Redemarrage** : `boot` (8 chiffres hexa tires au demarrage, voir
  `hello.boot` **(a ajouter)**) change, ou `up_s` recule. L'app vide ses
  etats derives, garde ses series de courbes (nouveau segment) et renvoie
  `json 1` si le mode machine est retombe (il retombe toujours : 3.7).

### 3.7 Persistance : aucune

Le mode machine et ses reglages ne sont **pas** ecrits en NVS. Au demarrage,
la carte est en mode humain, periodes par defaut. Raisons :
- sur l'USB natif, tout redemarrage re-enumere le port : l'app se reconnecte
  de toute facon, et renvoie `json 1` (idempotent) ;
- un mode persiste inonderait de JSON le `pio device monitor` d'apres un
  flash ou un redemarrage, ou une session de banc ;
- zero ecriture flash de plus (le pilote evite deja d'ecrire pres des
  emissions : `kPersistAfterTxMs`).

### 3.8 Echo et invite

En mode machine, `cliPoll` n'echo plus les caracteres, n'emet plus le saut de
ligne apres Entree ni l'invite `> `, et n'appelle plus `Serial.flush()` apres
la commande **(a ajouter)** : `HWCDC::flush()` attend jusqu'a 1000 ms sans
progres, puis met `connected` a faux et vide tout le tampon d'emission
(`flushTXBuffer(NULL, 0)`), lignes machine comprises, sans que `json_perdus`
le voie. Seul le texte des commandes historiques reste bloquant. L'app
affiche elle-meme la commande envoyee dans la console. `json 0` et
l'expiration du bail reaffichent l'invite (non bloquante). Le retour arriere
reste gere (inutile pour l'app). A verifier au banc (U5) : sans `flush`, pas
d'octets perdus entre deux commandes (le commentaire de `cliPoll` dit que
l'USB CDC du C6 en perdait "si on enchaine trop vite").

## 4. Enveloppe et conventions

Champs communs a toutes les lignes machine :

| Champ | Type | Sens | Source |
|---|---|---|---|
| `v` | entier | version majeure du protocole, 1 | constante (a ajouter) |
| `t` | chaine | type de message (sections 5 et 6) | |
| `n` | entier 0..4294967295 | numero de ligne produite sur ce transport depuis le demarrage (pas remis a 0 par `json 1`) | compteur (a ajouter) |
| `ms` | entier 0..4294967295 | `millis()` a la production de la ligne (repart a 0 apres 49,7 jours) | `millis()` |
| `bloc` | chaine | pour `hello`, `etat`, `compteurs`, `reseau` : partie du message | |

Conventions :

- **Entiers seulement**, jamais de flottant : un gamma de 2,00 s'ecrit
  `gamma_c: 200` (centiemes). Les compteurs sont des `uint32_t` qui
  reviennent a 0 apres 4294967295.
- **Unites dans le nom** : `_ms`, `_s`, `_us`, `_dbm`, `_kbps`, `_c`
  (centiemes). Sans suffixe : un nombre d'evenements.
- **Octets en hexa** : chaines majuscules sans `0x`, 2 chiffres par octet,
  dans l'ordre de l'air : charge `"C5A5"`, trame brute `"0962D2D86B000000"`,
  registre `"2E"`. Identifiants de noeud Matter : `"0x"` + 16 chiffres (ils
  depassent 2^53, limite des nombres JSON surs), comme `nodeText`.
- **Booleens** `true`/`false` ; **`null`** = inconnu ou sans objet ; un champ
  optionnel peut etre absent.
- **Enumerations** : chaines ASCII minuscules sans accents, `_` comme
  separateur. Les roles et etats OpenThread gardent le texte d'OpenThread
  (`"child"`, `"Registered"`).
- **Pas d'horloge murale** : la carte n'a pas l'heure. L'app date a la
  reception d'un `hello` (heure locale <-> `ms`) et en deduit le reste.

Objet **Etat** (consigne ou etat cru), reutilise par plusieurs messages :

| Champ | Type | Plage | Source (`halo1::State`, `halo1_map.h`) |
|---|---|---|---|
| `marche` | booleen | | `State::power` |
| `lampes` | chaine | `avant`, `arriere`, `deux` | `State::lamps & F_LAMPS` (`lampsText`) |
| `lum` | entier | 76..254 (0x4C..0xFE), brut comme sur l'air | `State::bright` |
| `niveau` | entier | 4..254, niveau Matter canonique | `levelFromRaw(bright)` |
| `temp` | entier | 0 (froid)..100 (chaud), brut (0x00..0x64) | `State::temp` |
| `mired` | entier | 153..370 | `miredFromTemp(temp)` |

`niveau` est la valeur canonique ; Apple Home peut afficher un niveau voisin
qui donne la meme luminosite brute (`displayLevel`, affichage stable E.2).

Codes de champs de consigne (`a_livrer`, `confirme`, `champs`) : `marche`
(`FLD_FLAGS` : marche et lampes), `lum` (`FLD_BRIGHT`), `temp` (`FLD_TEMP`).

## 5. Messages periodiques et de session (carte -> app)

Chaque instantane est une suite de lignes d'un meme type, une par `bloc`.
L'app remplace les valeurs d'un (`t`, `bloc`) a chaque reception ; les blocs
d'un meme cycle ne sont pas forcement dans le meme `ms`.

### 5.1 `hello`

Emis apres `json 1`, sur `json hello`, et de nouveau si une valeur change
(jamais en pratique hors `json 1`). Deux blocs : d'un seul tenant, le pire
cas (957 octets) depassait le budget de 896 (2.2).

**Bloc `base`** (pire cas 627 octets) :

| Champ | Type | Sens | Source |
|---|---|---|---|
| `rev` | entier | revision mineure du protocole : 0 en v1.0 ; 1 = motifs `led` `desappairage` et `redemarrage`, `log` de `src` `bouton` (bouton BOOT, 24/09) ; 2 = transport reseau (section 10 : caps `udp` et `cle`, `session.transport` `udp`, bloc `reseau` `ip`, `reponse` `cle` et `empreinte`, code `interdite`) ; 3 = `reseau.thread.matter.code_manuel` et `qr` aussi une fois en service (USB) ; 4 = `led.depuis_ms` (bloc `sante` et evenement `led`), `json 0` par le reseau rend sa place (10.4) | `jsonp::kRev` (`json_out.h`) |
| `fw` | chaine | version complete du firmware, ex. `0.4.0-1a2b3c4` | `FW_VERSION_FULL` (`fw_version.h`) |
| `fw_desc` | chaine | version du descripteur d'application, celle que Matter publie ; doit egaler `fw` | `esp_app_get_description()->version` |
| `date`, `heure` | chaines | compilation | `esp_app_get_description()->date`, `->time` |
| `env` | chaine | env PlatformIO, ex. `esp32c6thread` | `FW_ENV` (a ajouter : `tools/git_rev.py`, `env["PIOENV"]`) |
| `build` | chaine | `produit` ou `diag` | `DIAG_ONLY` |
| `reseau_build` | chaine | `thread`, `wifi`, `aucun` | `MATTER_NET_THREAD`, `DIAG_ONLY` |
| `puce` | chaine | `esp32c6` | `CONFIG_IDF_TARGET` |
| `idf` | chaine | ex. `v5.5.5` | `esp_get_idf_version()` |
| `arduino` | chaine | ex. `3.3.12` | `ESP_ARDUINO_VERSION_STR` |
| `boot` | chaine 8 hexa | identifiant de ce demarrage | `esp_random()` dans `setup()` avant `matterBridgeBegin()` (donc avant `Matter.begin()`), entre `bootloader_random_enable()` et `bootloader_random_disable()` (a ajouter) : aucune radio n'est encore active, et IDF ne garantit alors qu'un aleatoire pseudo |
| `reset` | chaine | `mise_sous_tension`, `broche`, `logiciel`, `panique`, `chien_int`, `chien_tache`, `chien`, `baisse_tension`, `usb`, `inconnue` | `esp_reset_reason()` (meme table que `resetReasonText`) |
| `reset_n` | entier | valeur brute de `esp_reset_reason()` | idem |
| `up_s` | entier | secondes depuis le demarrage | `esp_timer_get_time() / 1000000` |
| `session` | objet | reglages en vigueur : `transport` (`usb`, `udp`), `periode_ms`, `compteurs_ms`, `reseau_ms`, `bail_s`, `trames`, `log` | session (a ajouter) |
| `limites` | objet | `ligne_max` (1024), `cmd_max` (127) | |

**Bloc `identite`** (pire cas 467 octets) :

| Champ | Type | Sens | Source |
|---|---|---|---|
| `boot` | | comme le bloc `base` | |
| `mac` | chaine 12 hexa | MAC-48 d'usine | `esp_read_mac(mac, ESP_MAC_BASE)` |
| `id.fabricant` | chaine <= 32 | | `MATTER_VENDOR_NAME` |
| `id.produit` | chaine <= 32 | | `MATTER_PRODUCT_NAME` |
| `id.serie` | chaine <= 32 | `HALO1-` + MAC | `sSerial` (`matter_bridge.cpp : applyIdentity`) ; build diag : meme calcul, hors du pont (a ajouter) |
| `id.nom` | chaine <= 32 | NodeLabel | `MATTER_NODE_LABEL` |
| `id.hw` | entier | | `MATTER_HW_VERSION` |
| `id.hw_txt` | chaine <= 64 | | `MATTER_HW_VERSION_STRING` |
| `caps` | tableau de chaines | capacites de ce build (voir ci-dessous) | |

Capacites v1 : `matter` (pont Matter compile), `thread` (Matter sur Thread),
`garde` (garde d'antenne presente : `Halo1Radio::hasAirGuard()`), `ep4`
(`HALO1_EXPOSE_AUTO`), `led` (voyant d'etat : `PIN_RGB_STATUS_LED` ou LED
simple, hors build diag), `lampe_async` (commandes `lampe` asynchrones avec
`id`, 6.2), `trames` (`rx`/`tx`), `log`, `udp` (transport reseau, section 10),
`cle` (gestion de la cle, 10.4). L'app se regle sur `caps`, pas sur la
version du firmware.

### 5.2 `config`

Reglages lents : emis avec `hello`, et apres toute commande qui en change un
(`lampe rafale|ecart|rx|leger|garde|gamma|adresse`, `matter
med|maxint|reprise auto|impulsion`). Pire cas : 696 octets.

| Champ | Type | Source |
|---|---|---|
| `lampe.adresse` | 8 hexa, ordre d'ecriture | `Halo1Lamp::address()` |
| `lampe.air` | 8 hexa, ordre sur l'air | `Halo1Radio::air()` |
| `lampe.canal` | entier (5) | `halo1::kChannel` |
| `lampe.debit_kbps` | entier (125) | `bc5602::DATARATE_125K` |
| `reglages.paquets`, `accuses_min`, `paquets_max` | entiers | `Halo1Lamp::tuning.repeats`, `minAcks`, `maxAttempts` |
| `reglages.ecart_ms`, `reprise_ms`, `reprises` | entiers | `tuning.gapMs`, `retryMs`, `planRetries` |
| `reglages.rearm_ms`, `silence_ms` | entiers | `Halo1Radio::tuning.rearmMs`, `silenceMs` |
| `reglages.rearm_fort`, `leger`, `garde` | booleens ; `garde` : null si `!radio.hasAirGuard()` (diag, Wi-Fi) | `tuning.strongRearm`, `lightSwitch`, `airGuard` |
| `reglages.gamma_c` | entier (200 = 2,00) | `mapGamma()` |
| `seuils.delais_suite` (3), `deluge_trames` (100), `deluge_pct` (90), `fenetre_ms` (10000), `sourd_hors_rx` (1000), `sans_guerison` (3), `ecart_ms` (60000), `repli_ms` (600000) | entiers | `ChipWatch::kTimeoutRun`, `kNoiseMinFrames`, `kNoiseBadPct`, `kNoiseWindowMs`, `kDeafMinRearms`, `kFruitless`, `kGapMs`, `kBackoffMs` |
| `matter.endpoints` | objet `principal`, `avant`, `arriere`, `auto` (absent sans EP4) | `getEndPointId()` des endpoints (a ajouter) |
| `matter.lampes_en` | `lumieres` ou `prises` | `HALO1_SELECTORS_AS_LIGHTS` |
| `matter.mired_min`, `mired_max`, `niveau_plancher` | entiers | `kMiredCold`, `kMiredWarm`, `kMatterLevelFloor` |
| `matter.impulsion_ms` | entier (EP4 seulement) | `matterAutoPulseMs()` |
| `matter.med`, `matter.med_boot` | 0 routeur, 1 MED des l'init, 2 MED apres `Matter.begin()` | `matterMedMode()`, `sMedBoot` (statique : a exposer) |
| `matter.maxint_s` | entier (0 = celui du controleur) | `matterMaxIntervalCap()` |
| `matter.reprise_auto` | booleen | `matterResumeAuto()` |

Les `seuils` servent a tracer les lignes de declenchement sur les courbes.
`matter` vaut `null` dans le build diag.

### 5.3 `etat`

Periode `periode_ms` (1000 par defaut). Trois blocs : `lampe` d'un seul
tenant (pire cas 917 octets) depassait le budget de 896 (2.2), ses tranches
en sortent.

**Bloc `lampe`** (pire cas 623 octets) :

| Champ | Type | Sens | Source |
|---|---|---|---|
| `boot`, `up_s` | | comme `hello` | |
| `consigne` | Etat | etat voulu | `Halo1Lamp::target()` |
| `cru` | Etat | etat cru de la lampe | `Halo1Lamp::believed()` |
| `a_livrer` | tableau de codes | champs de la consigne pas encore livres | `Halo1Lamp::dirty()` |
| `confirme` | tableau de codes | champs confirmes depuis le demarrage | `Halo1Lamp::confirmed()` |
| `version` | entier | +1 a chaque changement de consigne | `Halo1Lamp::version()` |
| `phase` | `repos`, `rafale`, `reprise` | | `Halo1Lamp::phase_` (a ajouter) |
| `reprise_ms` | entier ou null | avant la reprise, en phase `reprise` | `max(0, (int32_t)(retryAt_ - millis()))` (a ajouter) |
| `echecs` | entier 0..`reglages.reprises` (2) | tours rates de la consigne en cours ; le suivant l'abandonne (`giveUp()` le remet a 0) | `failures_` (a ajouter) |
| `lien` | `inconnu`, `ok`, `perdu` | | `Halo1Lamp::link()` |
| `accuse_ms` | entier ou null | age du dernier accuse de la lampe (null : aucun depuis le demarrage) | `lastAckAt_`, `acked_` (a ajouter) |
| `dernier_a` | entier 0..255 | dernier numero d'appui A | `Halo1Lamp::lastAuto()` |
| `a_entendus` | entier | appuis A de la telecommande entendus (jamais remis a zero) | `remoteAutoCount()` |
| `memoire` | lampes | memoire de selection | `memoryLamps()` |
| `livrees` | entier | consignes livrees depuis le demarrage (jamais remis a zero) | `deliveredCount()` |
| `abandons` | entier | consignes abandonnees (idem) | `giveUpCount()` |
| `sauve_attente` | booleen | etat cru pas encore ecrit en NVS | `persistDirty_` (a ajouter) |
| `ecoute` | booleen | ecoute de fond de la telecommande | `listening()` |
| `trace` | booleen | traces du pilote | `tracing()` |

**Bloc `tranches`** (pire cas 422 octets, 119 sans tranche active) :

| Champ | Type | Sens | Source |
|---|---|---|---|
| `boot`, `up_s` | | comme `hello` | |
| `tranches` | tableau de 0 a 4 objets | tranches actives : `tranche` (`lum`, `temp`, `a`, `brut`), `charge` (hexa), `accuses`, `essais`, `paquets` | `slots_` : `Slot.pay`, `acks`, `attempts`, `repeats` (a ajouter) |

**Bloc `sante`** (pire cas 726 octets) :

| Champ | Type | Sens | Source |
|---|---|---|---|
| `boot`, `up_s` | | | |
| `radio.presente` | booleen | BM5602 detecte | `Halo1Radio::present()` |
| `radio.perdue` | booleen | niveau L3 : relance ratee ou sans effet | `Halo1Lamp::lost()` |
| `radio.mode` | `inconnu`, `reset`, `emission`, `ecoute`, `veille` | | `Halo1Radio::mode()` |
| `radio.configuree` | booleen | la puce porte la configuration du pilote | `Halo1Radio::configured()` |
| `radio.quartz`, `radio.calib` | booleens | au dernier `halo.begin()` | `radio.chip()->crystalReady()`, `calibrated()` |
| `surveil.panne` | booleen | EN PANNE | `ChipWatch::failed()` |
| `surveil.defaut` | booleen | critere du rouge fixe de la LED | `Halo1Lamp::moduleFault()` |
| `surveil.symptome` | `delais`, `bruit`, `sourde` ou null | symptome present (`symptom()` ne rend jamais `Verify`) | `ChipWatch::symptom()` |
| `surveil.delais_suite` | entier 0..255 | delais TX de suite (seuil 3) | `timeoutRun()` |
| `surveil.fen_trames`, `fen_crc_faux` | entiers | fenetre d'ecoute en cours (10 s) | `windowFrames()`, `windowBad()` |
| `surveil.hors_rx_10s` | entier | rearmements hors RX sur 10 s glissantes (seuil 1000) | `deafRearms()` |
| `surveil.sans_guerison` | entier | relances de suite sans guerison (EN PANNE a 3) | `unrecovered()` |
| `surveil.attente_ms` | entier | avant la prochaine relance permise | `waitMs(millis())` |
| `surveil.relances` | entier | relances automatiques comptees | `total()` |
| `surveil.derniere` | objet ou null | `cause`, `il_y_a_s` | `history(&e, 1)` |
| `led.motif` | voir `led` (7.9) | motif affiche ; null en diag | `statusLedPoll` : `sFrame.p` (a ajouter) |
| `led.test` | booleen | `led test` en cours ; null en diag | `Logic::testing()` |
| `led.depuis_ms` | entier | age de la phase du motif (ms) a l'emission : l'app cale son voyant dessus (en `operationnel`, lueur de 600 ms quand `depuis_ms % 10000 < 600`) ; null en diag (rev 4) | `statusLedState` : `millis()` moins le depart de phase note au dernier `statusLedPoll` (`Frame.t`) |
| `matter` | objet ou null | `en_service`, `connecte`, `identify` | `matterIsCommissioned()`, `matterIsConnected()`, `matterIdentifying()` ; null en diag |
| `sys.heap`, `heap_min`, `heap_bloc` | octets | tas libre, minimum historique, plus grand bloc | `esp_get_free_heap_size()`, `esp_get_minimum_free_heap_size()`, `heap_caps_get_largest_free_block(MALLOC_CAP_8BIT)` |
| `sys.pile_boucle` | octets | pile de la tache loop jamais utilisee | `uxTaskGetStackHighWaterMark(NULL)` |
| `sys.boucle_max_ms` | entier | plus long tour de `loop()` depuis le bloc precedent | mesure (a ajouter) |
| `sys.json_perdus`, `json_trop_longs`, `rejets` | entiers | par transport (la session qui recoit la ligne) : lignes machine perdues (tampon d'emission ou file des datagrammes pleins, retard, ligne deja en cours de formatage), trop longues (bogue), lignes de l'hote refusees (`trop_long`, `cadence`, `interdite`, et a distance une ligne sans `id`) | compteurs de la session (`json_mode.cpp : Sink`) |

`matterIsConnected()` sur Thread ne prend jamais le verrou OpenThread en
attente (`netPoll` : `otLockTry(0)`, une fois par seconde) : sans risque pour
`tick()`.

### 5.4 `compteurs`

Periode `compteurs_ms` (1000). Trois blocs, compteurs cumulatifs : l'app
calcule les courbes par differences (section 8). `lampe stats raz`
(`Halo1Lamp::clearStats`) remet a zero les blocs `pilote` et `radio`
(`relances.*` compris, `ChipWatch::clearCounts`), ainsi que
`etat.sante.surveil.relances` et `surveil.derniere` ; ni `sans_guerison`,
`panne`, `attente_ms`, ni `tx.total`, `livrees`, `abandons`, `a_entendus`, ni
le bloc `matter`. Le champ `raz` (nombre de `lampe stats raz` depuis le
demarrage, **a ajouter**) signale la coupure.

**Bloc `pilote`** (pire cas 701) - source `Halo1Lamp::stats` sauf mention :

| Champ | Source |
|---|---|
| `raz` | (a ajouter) |
| `tx.consignes`, `paquets`, `accuses`, `ack_trame`, `max_rt`, `delais`, `fifo` | `requests`, `packets`, `acks`, `ackForeign`, `maxRt`, `timeouts`, `fifoRefused` |
| `tx.total` | `Halo1Lamp::txCount()` (jamais remis a zero, brut compris) |
| `tranches.faibles`, `preemptees`, `annulees`, `reprises`, `abandons`, `attentes` | `weakFails`, `preempted`, `cancelled`, `retries`, `giveUps`, `holdoffs` |
| `a.livres`, `a.refuses` | `autoSent`, `autoIgnoredOff` |
| `rx.trames`, `etat`, `a`, `accuses_lampe`, `service`, `favori`, `invalides`, `crc_faux` | `rxFrames`, `rxState`, `rxAuto`, `rxLampAcks`, `rxService`, `rxReserved`, `rxInvalid`, `rxCrcBad` |
| `divers.sauvegardes`, `traces_perdues`, `relances_module` | `persisted`, `traceDropped`, `restarts` |

**Bloc `radio`** (pire cas 523) :

| Champ | Source |
|---|---|
| `raz` | (a ajouter) |
| `radio.configs`, `reconf_silence`, `reconf_tx`, `verif_ratees`, `rearm`, `rearm_hors_rx`, `brutes`, `bascules` | `Halo1Radio::stats` : `fullConfigs`, `silenceReconf`, `txReconf`, `verifyFail`, `rearms`, `rearmsOffRx`, `rxRaw`, `lightSwitches` |
| `garde` (null sans garde) : `active`, `gardes`, `refus`, `attentes`, `plafonnees`, `max_us` | `tuning.airGuard` ; `stats.guarded`, `guardRefused`, `guardWaits`, `guardCapped`, `guardMaxUs` |
| `relances.total`, `verif`, `delais`, `bruit`, `sourde` | `ChipWatch::total()`, `count(Relaunch::Verify / TxTimeout / RxNoise / RxDeaf)` |

**Bloc `matter`** (pire cas 341 ; absent en diag) - `matter_bridge.cpp : sStats`
(statique : a exposer) :

| Champ | Source |
|---|---|
| `fenetres`, `ignorees` | `windows`, `bootIgnored` |
| `a_appuis`, `a_refuses`, `a_entendus`, `a_perdus` (EP4 seulement) | `autoFired`, `autoRefused`, `autoHeard`, `autoLost` |
| `reflets`, `ecritures`, `echecs`, `verrou`, `traces_perdues` | `reflects`, `writes`, `writeFails`, `lockBusy`, `logDropped` |
| `identify` | `sIdentifyCount` |

### 5.5 `reseau`

Periode `reseau_ms` (5000). Build Thread seulement (build Wi-Fi : bloc
`thread` sans l'objet `thread` ; diag : jamais). Trois blocs (`ip` depuis la
revision 2). Les lectures
OpenThread se font sous `otLockTry(0)` (jamais d'attente) et celles de la pile
sous `TryLockChipStack()` : verrou pris ailleurs, la carte renvoie les
dernieres valeurs lues et `frais_ms` dit leur age.

**Bloc `thread`** (pire cas 685) :

| Champ | Source |
|---|---|
| `frais_ms` | age de la derniere lecture sous verrou (a ajouter) |
| `matter.en_service`, `connecte` | `Matter.isDeviceCommissioned()`, `matterIsConnected()` |
| `matter.reseau` (`thread`, `wifi`), `matter.wifi` | `Matter.getSelectedNetwork()`, `Matter.isWiFiConnected()` |
| `matter.fabriques` | nombre de fabriques (Apple Home, Google...) : `chip::Server::GetInstance().GetFabricTable().FabricCount()` sous verrou (a ajouter, facultatif) |
| `matter.code_manuel`, `matter.qr` | l'etiquette du pont, sur l'USB, mis en service ou non (revision 3 ; avant : seulement hors service) : `Matter.getManualPairingCode()` et la charge `MT:...` = parametre `data=` de `getOnboardingQRCodeUrl()`, dont `GetQRCodeUrl` encode `:` en `%3A` (decoder les `%XX`) ; valeurs en cache dans la bibliotheque, sans verrou. Elles ne servent que pendant une fenetre de mise en service (pont neuf, remis a zero, ou retire de son dernier controleur). Toujours null sur le transport reseau. |
| `thread.role` | `otThreadGetDeviceRole` -> `otThreadDeviceRoleToString` (`disabled`, `detached`, `child`, `router`, `leader`) |
| `thread.canal`, `thread.mhz` | `otLinkGetChannel` ; `2405 + 5 x (canal - 11)` |
| `thread.pan` | `otLinkGetPanId`, `"0x%04X"` |
| `thread.tx_dbm` | `otPlatRadioGetTransmitPower` |
| `thread.parent_rssi` | `otThreadGetParentAverageRssi` (null si erreur) |
| `thread.mode` | `otThreadGetLinkMode` -> `linkModeText` (`rn` = MED, `rdn` = FTD) |
| `thread.type_boot`, `type_suivant` | `routeur`, `med_init`, `med_tard` : `sMedBoot`, `matterMedMode()` |
| `thread.pret_ms` | premier instant attache + hote SRP enregistre, ou null : `sNet.readyAt` |
| `thread.roles` | changements de role depuis le demarrage : `sRoleChanges` |
| `thread.mle.attaches`, `detache`, `enfant`, `routeur`, `chef`, `parent_change` | `otThreadGetMleCounters` : `mAttachAttempts`, `mDetachedRole`, `mChildRole`, `mRouterRole`, `mLeaderRole`, `mParentChanges` |
| `thread.srp.client`, `hote`, `services`, `enregistres`, `serveur`, `port` | `otSrpClientIsRunning`, `otSrpClientItemStateToString(hote)`, services comptes et enregistres, `otSrpClientGetServerAddress` |

**Bloc `abonnements`** (pire cas 530) :

| Champ | Source (`matter_bridge.cpp`) |
|---|---|
| `abonnements.actifs`, `lectures` | `sCount.subs`, `sCount.reads` (`countPoll`, toutes les 2 s) |
| `abonnements.sauves` | `collectSaved(...)` total sous `TryLockChipStack()` (lecture NVS de chaque abonnement, verrou de la pile tenu) : au plus toutes les 30 s et sur `json etat`, derniere valeur gardee ; null si verrou ou iterateur occupe |
| `abonnements.demandes`, `neufs`, `repris_pont`, `repris_pile`, `termines`, `plafonnes` | `sSubs.requested`, `fresh`, `byBridge`, `byStack`, `terminated`, `capped` |
| `abonnements.plafond_s`, `reprise_auto` | `sMaxIntCap`, `sResumeAuto` |
| `reprise.passages`, `auto`, `sessions`, `ouvertes`, `echecs`, `sans_nouvelles`, `reprises` | `sResume.runs`, `autoRuns`, `opened`, `ok`, `failed`, `lost`, `resumed` |
| `reprise.en_cours` | `resumeInFlight(millis())` |

**Bloc `ip`** (build Thread, revision 2 ; pire cas ~770) - `net_udp.cpp :
netUdpJson`, releve OpenThread sous `otLockTry(0)` au plus toutes les 5 s,
cle ou pas (l'app lit nom et adresses par l'USB avant de regler une cle) :

| Champ | Source |
|---|---|
| `frais_ms` | age du releve (null : jamais lu) |
| `srp.nom` | nom d'hote SRP du noeud (`otSrpClientGetHostInfo()->mName`, celui que Matter enregistre), a resoudre en `<nom>.local` (10.3) ; null inconnu |
| `adresses` | au plus 4 objets : `adr` (texte IPv6), `type` (`omr` : SLAAC hors maillage, joignable du LAN ; `ml_eid` : maillage seulement ; `autre`), `pref` (preferee) ; ni RLOC, ni ALOC, ni lien local (`otIp6GetUnicastAddresses`) |
| `udp.port` | 5480 |
| `udp.ouvert` | socket ouvert (une cle existe) |
| `udp.empreinte` | empreinte de la cle (10.4), null sans cle : l'app verifie qu'elle a la bonne |
| `udp.sessions`, `udp.provisoire` | sessions H1 etablies (0..2), poignee de main en cours |
| `udp.rx`, `udp.rejets`, `udp.rx_perdus`, `udp.defis` | messages acceptes ; datagrammes refuses en silence (forme, cle, sid, MAC, rejeu, limite, SALUT sans place pour son `DEFI`) ; perdus avant lecture (trop grands, file de reception pleine, jetes a la fermeture du socket) ; `DEFI` emis |
| `udp.tx`, `udp.tx_perdus`, `udp.tx_erreurs` | datagrammes remis a OpenThread ; perdus apres leur mise en file (4 s sans depart, refus d'OpenThread, file videe par un changement de cle, session partie) ; parmi eux, ceux qu'OpenThread a refuses (une fois par datagramme). Une ligne qui ne trouve pas de place dans la file est comptee dans le `json_perdus` de sa session. |
| `udp.tampons_libres`, `udp.tampons_min` | tampons de messages OpenThread libres au releve, minimum vu avant un envoi (null : inconnu) |

### 5.6 `hb` et `fin`

`hb` : battement quand les `etat` sont coupes ou lents (3.6). Champs `boot`,
`up_s`, `json_perdus`.

`fin` : dernier message d'une session machine. `cause` : `commande` (`json 0`)
ou `bail`.

## 6. Commandes de l'app (app -> carte)

### 6.1 Choix : texte de la CLI prefixe par `id=<n>`

L'app envoie les commandes de la CLI existante, telles qu'un humain les
taperait, precedees de `id=<n> ` :

```
id=17 lampe niveau 200
```

`n` : entier decimal 1..999999999, croissant par connexion, repart a 1 apres
999999999. Sur le reseau, une connexion est une session H1 : les `id` y
croissent, et une reconnexion refait une poignee de main (10.2). Le prefixe est retire avant l'aiguillage (`handleLine`) ; aucune
commande ne commence par `id=`.

Pourquoi pas des commandes JSON :
- **un seul analyseur** cote carte, celui de la CLI, deja teste et documente
  (`lampe help`, README) ; pas de bibliotheque JSON a lier (flash : le firmware
  C6 pese deja 2,41 Mo pour une partition `huge_app` de 3 Mo, `platformio.ini`) ;
- la **console brute** de l'app et les commandes de ses boutons sont le meme
  flux, et chaque commande de l'app se rejoue a la main dans un terminal ;
- les commandes tiennent en 127 octets ; il n'y a rien a echapper ;
- le transport reseau transporte la meme ligne, dans une enveloppe signee.

Ce que l'on perd : le typage des arguments. Il est rendu par les reponses : un
argument refuse donne `code` `usage` (commandes JSON et lampe asynchrones), et
l'app ne construit ses lignes que depuis des valeurs deja bornees.

### 6.2 Semantique d'une ligne avec `id`

| Commande | Deroulement | Messages |
|---|---|---|
| famille `json` | instantanee ; `json 1`, `json etat`, `json hello` passent par la file des periodiques | lignes produites, puis `reponse` (`fin`) apres la derniere |
| `lampe on\|off`, `lampe avant\|arriere on\|off`, `lampe mode ...`, `lampe lum ...`, `lampe niveau ...`, `lampe temp ...`, `lampe mired ...`, `lampe auto`, `lampe sync` | **asynchrone** : memes regles que la commande humaine (`runIntent`, `runState`, `pressAuto`, `reassert`), mais **sans** `waitIdle` ni bilan texte | `reponse` (`fin`) en quelques ms, puis `livraison` portant l'`id` quand le pilote a fini |
| toute autre commande (dite historique) | inchangee : texte humain, parfois bloquante | `reponse` `debut`, le texte, puis `reponse` `fin` |

Sans `id`, rien ne change : texte humain, commandes `lampe` bloquantes avec
bilan (`printBilan`), aucune `reponse`. Le mode machine (`json 1`) ne change
que l'echo, l'invite et les emissions ; c'est l'`id` qui fait la semantique.

Commandes asynchrones, detail (cli_lampe.cpp) :
- `radioReady()` faux : `reponse` `ok:false`, `code` `radio_absente` ou
  `radio_perdue`, rien n'est demande ;
- arguments hors bornes : `code` `usage` (bornes de `cmdLampe` : `lum`
  4C..FE en hexa, `niveau` 1..254, `temp` 0..100 en DECIMAL, `mired`
  153..370) ;
- `lampe auto` lampe eteinte (`pressAuto()` faux) : `code` `refuse` ;
- sinon la consigne est posee ; si le pilote est occupe (`busy()`) : `code`
  `accepte`, `suite` `livraison`, et l'`id` rejoint la liste des id en attente
  (8 au plus, les plus anciens sortent : `ids_perdus`) ; une `livraison`
  (`livree`, `abandon` ou `annulee`) suivra toujours ;
- pas occupe mais des champs restent a livrer (`dirty()` non nul : lampe
  eteinte, la luminosite partira a l'allumage) : `code` `differe`, `suite`
  `aucune` ; aucune `livraison` ne viendra pour cet `id` ;
- ni l'un ni l'autre : `code` `ok`, `suite` `aucune`.

La `livraison` suivante (7.3) porte tous les id en attente : la carte fond les
consignes (une nouvelle preempte une tranche en cours), donc une livraison
couvre toutes les commandes acceptees depuis la precedente.

### 6.3 Message `reponse`

| Champ | Type | Sens |
|---|---|---|
| `id` | entier | celui de la ligne |
| `etape` | `debut` ou `fin` | `debut` : commande historique qui commence (la boucle va peut-etre bloquer) |
| `cmd` | chaine <= 40 | la commande recue, sans le prefixe, tronquee |
| `ok` | booleen | |
| `code` | chaine | voir ci-dessous |
| `msg` | chaine <= 120, facultatif | explication en francais |
| `duree_ms` | entier (`fin`) | duree d'execution |
| `suite` | `livraison` ou `aucune` (lampe asynchrone) | |
| `consigne`, `a_livrer`, `version` | (lampe asynchrone) | consigne apres la commande |
| `bail_s`, `up_s` | (`json ping`, `json 1`) | |
| `cle` | 64 hexa (`json cle nouvelle`, USB, une seule fois) | cle du transport reseau (10.4) : l'app la masque partout |
| `empreinte` | 8 hexa ou null (`json cle ...`) | empreinte de la cle, null sans cle |

Codes :

| Code | ok | Sens |
|---|---|---|
| `ok` | oui | executee |
| `accepte` | oui | lampe asynchrone : une `livraison` suivra |
| `differe` | oui | lampe asynchrone : rien a emettre maintenant |
| `en_cours` | oui | etape `debut` |
| `execute` | oui | commande historique terminee ; son resultat est dans le texte (la carte ne sait pas si elle a affiche un `Usage`) |
| `usage` | non | arguments invalides (commandes JSON et lampe asynchrones) |
| `refuse` | non | refusee par une regle (`msg` dit laquelle) |
| `radio_absente`, `radio_perdue` | non | BM5602 absent ou perdu (L3) |
| `inconnue` | non | commande inconnue (branche finale de `handleLine`) |
| `trop_long` | non | ligne de plus de 127 octets : rien d'execute |
| `cadence` | non | plus de 20 lignes par seconde sur ce transport : rien d'execute |
| `interdite` | non | interdite sur ce transport (10.5) |
| `deja_traite` | non | reseau : `id` deja traite, reponse plus disponible (ou autre commande sous cet `id`) ; rien n'est reexecute (10.2) |

### 6.4 Commandes utilisees par l'app

| Ecran | Action | Ligne envoyee | Suite attendue |
|---|---|---|---|
| tous | connexion | `json 1`, puis `json ping` | 3.3, 3.5 |
| tableau de bord | rafraichir | `json etat` | instantane complet |
| tableau de bord | tester la LED | `led test` / `led stop` | `led` (evenements), texte |
| commandes | marche / arret | `lampe on` / `lampe off` | `reponse`, `livraison` |
| commandes | lampe avant / arriere | `lampe avant on`, `lampe arriere off` | idem (regles Matter, memoire de selection) |
| commandes | mode | `lampe mode avant\|arriere\|deux` | idem (allume aussi) |
| commandes | luminosite (curseur Matter) | `lampe niveau <4..254>` (plancher `kMatterLevelFloor` ; la CLI accepte 1..254, mais 1..3 donnent 4C et sont rapportes 4) | idem |
| commandes | luminosite brute | `lampe lum <4C..FE>` (hexa) | idem |
| commandes | temperature (curseur) | `lampe mired <153..370>` | idem |
| commandes | temperature brute | `lampe temp <0..100>` (decimal) | idem |
| commandes | bouton A | `lampe auto` | idem, ou `refuse` lampe eteinte |
| commandes | resynchroniser | `lampe sync` | idem (tout est renvoye) |
| trames | pause / reprise du flux | `json trames 0\|1` | |
| trames | ecoute de fond | `lampe ecoute 0\|1` (banc) | etat visible dans `etat.lampe.ecoute` |
| courbes | remise a zero | `lampe stats raz` (confirmation) | `compteurs` avec `raz` + 1 |
| console | tout le reste | ligne tapee, prefixee d'un `id` | `reponse` `debut`, texte, `reponse` `fin` |

Curseurs : l'app envoie au plus une commande toutes les 150 ms pendant le
glissement, et toujours la valeur finale au relachement. La carte fond les
consignes (la valeur finale obtient toujours sa rafale complete :
`Halo1Lamp::setSlot`) ; inutile d'aller plus vite que la telecommande (~9
trames par seconde a la molette).

**Console brute.** Chaque ligne tapee part avec un `id`, pour que l'app sache
ou finit la sortie : le texte recu entre `reponse debut` et `reponse fin` de
cet `id` lui est rattache (au mieux : un log IDF peut s'y glisser). Les
commandes `lampe` d'etat tapees dans la console deviennent donc asynchrones
(6.2) ; l'app rend `reponse` et `livraison` en texte lisible dans la console.
Confirmation demandee par l'app avant d'envoyer : `reboot`, `decommission`,
`erase`, `wifi`, `addr`, `chan`, `xo`, `debit`, `amble`, `aw`, `holtek`,
`regcfg`, `lampe oublie`, `lampe adresse <x>`, `lampe stats raz`, `matter
med|maxint|reprise auto`, `json cle nouvelle|efface`. Apres `reboot` ou
`decommission`, l'app attend la re-enumeration (3.1).
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

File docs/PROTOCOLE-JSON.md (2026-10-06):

[Français](PROTOCOLE-JSON.fr.md) · **English**

# Halo bridge JSON protocol (v1)

Specification of the machine protocol between the firmware (ESP32-C6, product
env `esp32c6thread`, bench env `esp32c6diag`) and the supervision application:
first the native SwiftUI macOS app (`apps/macos/`, USB link), later the iOS
app over the network (Thread -> Apple border router -> LAN). The same
protocol serves both: only the transport and the authentication change.

Status: IMPLEMENTED in firmware 0.4.0 (USB transport validated on the bench
on Sep 24; network transport, section 10, validated on the bench on Sep 25:
R1 and part of R2, see 10). The **(to add)** marks date from the
specification: the fields in question now exist.
Every field cites its source in the code (`file : symbol`), so the
implementation invents nothing.
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

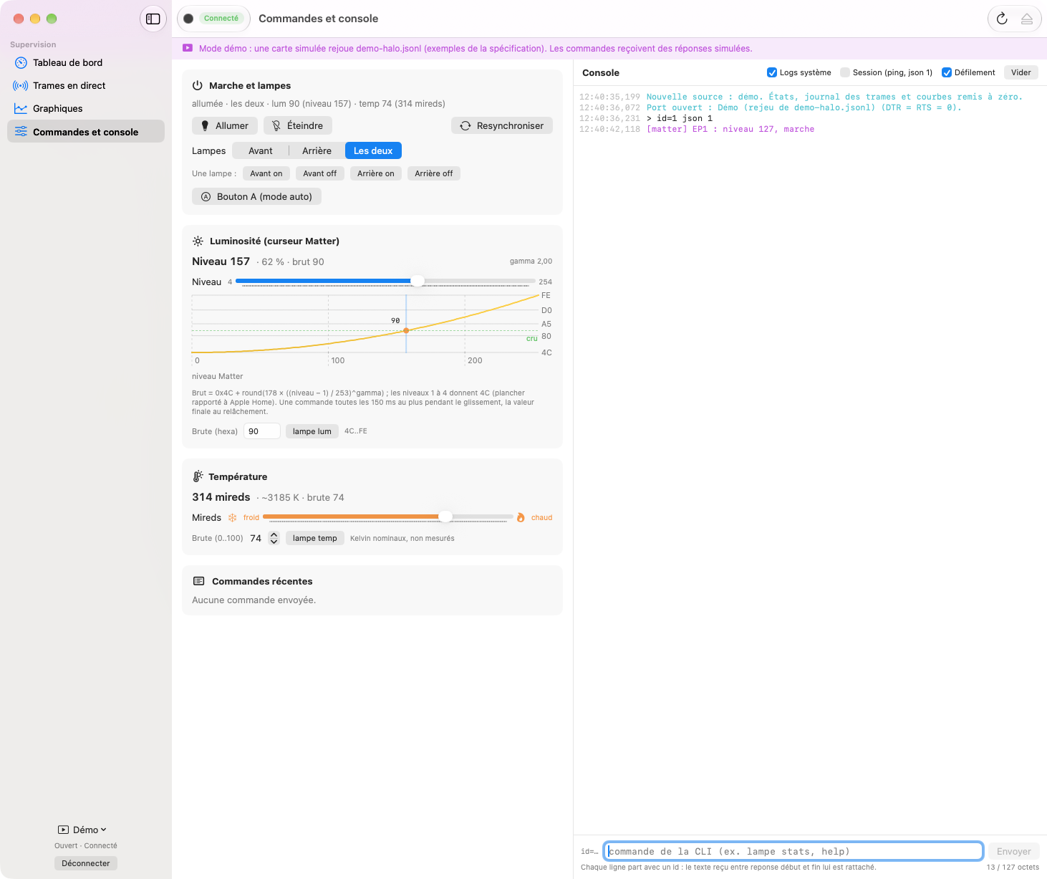
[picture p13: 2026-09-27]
docs/images/compagnon-commandes-fr.png

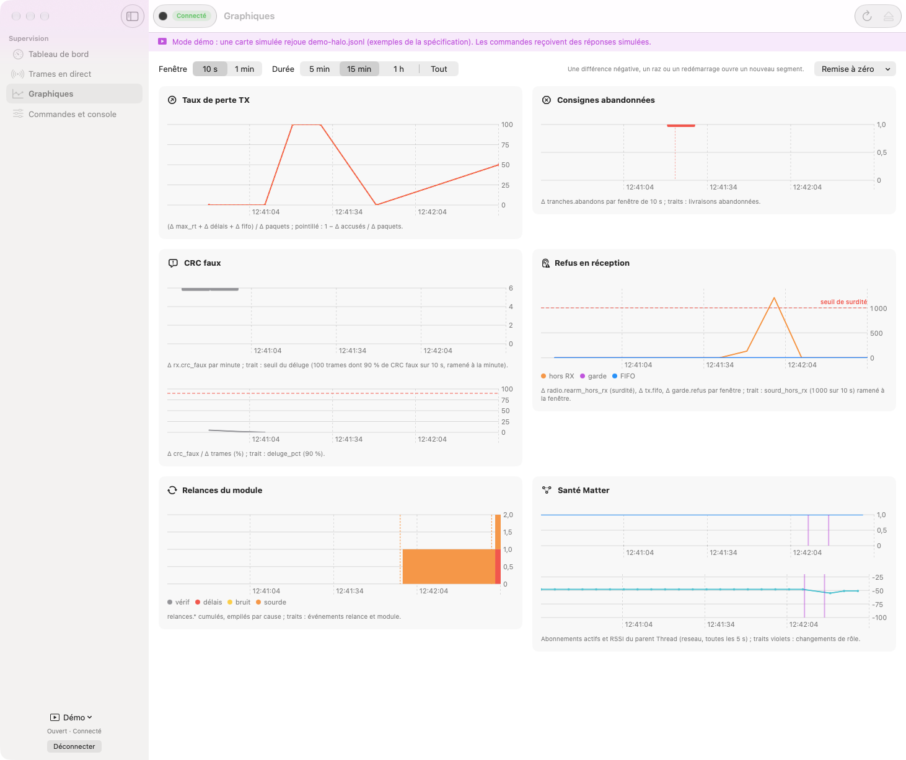
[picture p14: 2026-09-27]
docs/images/compagnon-graphiques-fr.png

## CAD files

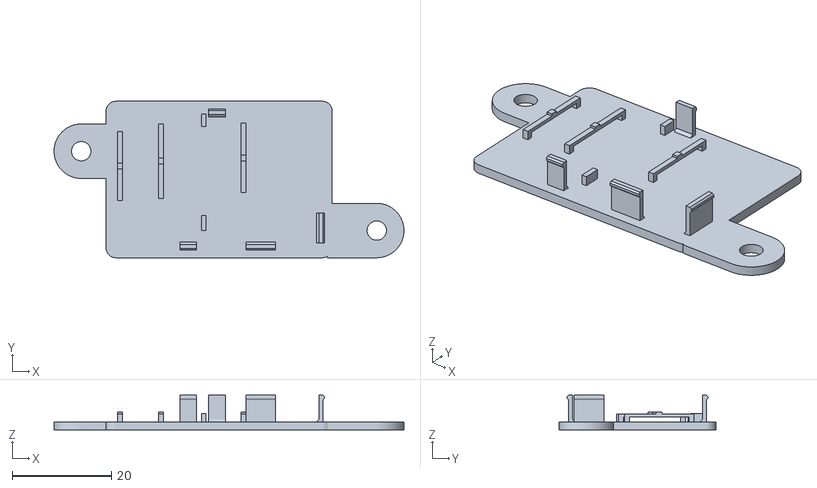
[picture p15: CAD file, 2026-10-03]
hardware/boitier/Front.stl
70.7 x 31.6 x 7.01

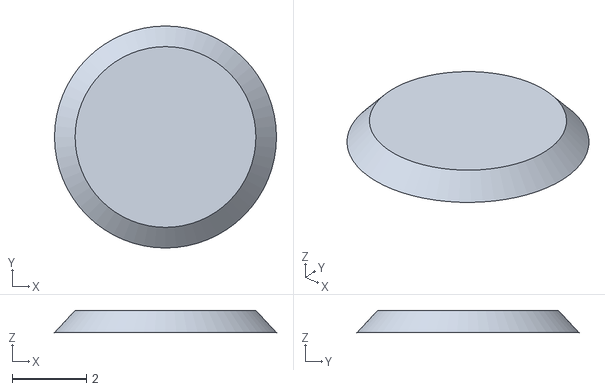
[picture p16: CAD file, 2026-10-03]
hardware/boitier/Diffuser.stl
5.98 x 5.98 x 0.6

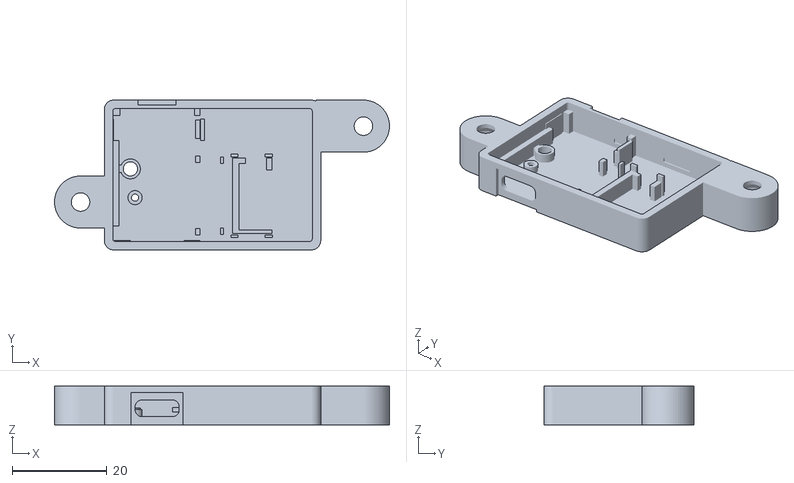
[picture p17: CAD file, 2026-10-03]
hardware/boitier/Back.stl
70.7 x 31.6 x 8.21

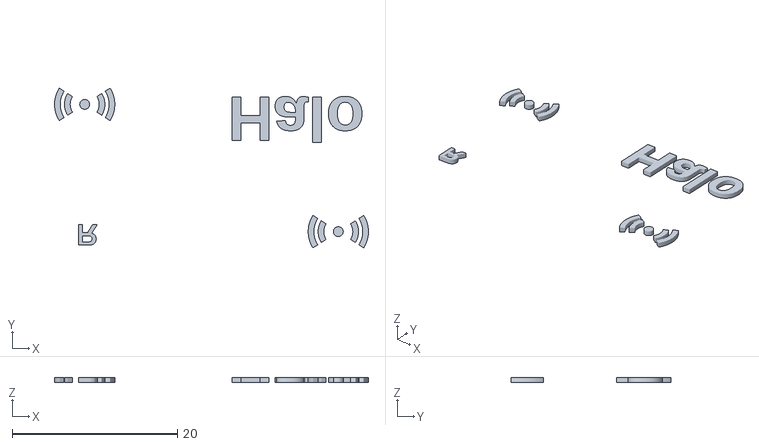
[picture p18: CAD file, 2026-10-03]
hardware/boitier/Engravement.stl
38.0 x 19.3 x 0.6

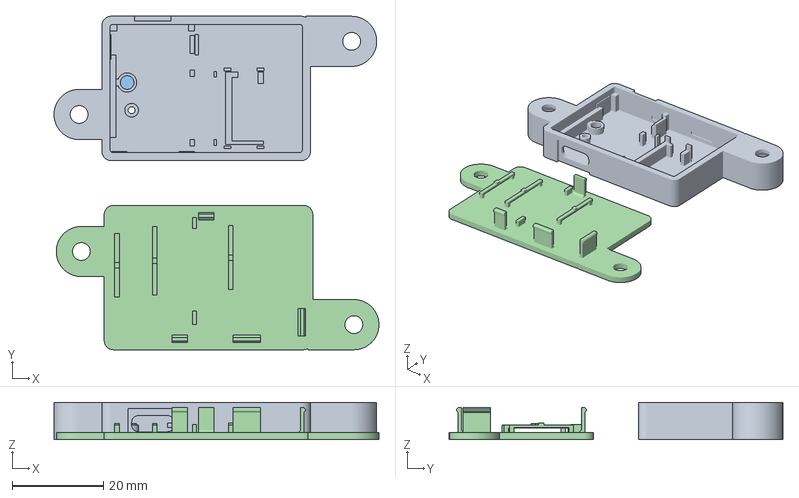
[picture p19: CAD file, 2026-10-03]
hardware/boitier/halo-bridge-housing.3mf
71.2 x 73.1 x 8.21 mm
Fond
Gravure - option AMS
Diffuseur voyant - option AMS
Couvercle (PRET A IMPRIMER).stl

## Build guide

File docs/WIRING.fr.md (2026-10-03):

**Français** · [English](WIRING.md)

# Câblage

## Module BM5602-60-1 → ESP32

Le BM5602 démarre en SPI **3 fils** (`SDIO` bidirectionnel). Le firmware bascule
le registre `IO1` en mode **4 fils** dès l'init : `GIO2` devient alors la sortie
de données, donc le MISO côté ESP32.

## Brochage du module BM5602-60-1

Le module **n'a aucun marquage sérigraphié** sur ses pastilles, et le texte
`BM5602-60-1 V1.0` est imprimé sur **ses deux faces** : il ne suffit pas à
l'orienter. Prends la **face composants**, celle de la puce et du quartz, antenne
en haut : les 9 pastilles du bord inférieur sont alors, **de gauche à droite** :

| # | 1 | 2 | 3 | 4 | 5 | 6 | 7 | 8 | 9 |
|---|---|---|---|---|---|---|---|---|---|
| | `VSS` | `VDD` | `GIO1` | `CSN` | `SCK` | `GIO2` | `SDIO` | `GIO3` | `GIO4` |
| | GND | 3V3 | — | CS | horloge | **MISO** | **MOSI** | — | — |

**Sur la face plate, l'ordre est inversé** : `GIO4` à gauche, `VSS` à droite.
Les pastilles sont des trous traversants, visibles des deux côtés : c'est le
piège.

`GIO1`, `GIO3` et `GIO4` ne servent pas. Les deux pastilles isolées sur les
bords gauche et droit, près de l'antenne, sont des `VSS` supplémentaires.

**Vérifie avant de souder** : au multimètre, en continuité, la pastille 1
(`VSS`) sonne avec ces pastilles isolées. C'est la seule de la rangée.

Source : le schéma de câblage du
[projet Halo 2](https://github.com/kuzmin-no/BenQ_ScreenBar_HALO_2_HA_integration/blob/main/img/connection_diagramm.png),
qui montre la face composants.

| BM5602-60-1 | Rôle SPI | **C6 SuperMini** | ESP32-C3 | ESP32-S3 | ESP32 (WROOM) |
|---|---|---|---|---|---|
| `VDD`  | 3,3 V | 3V3 | 3V3 | 3V3 | 3V3 |
| `VSS`  | GND | GND | GND | GND | GND |
| `SCK`  | horloge | **IO18** | GPIO 4 | GPIO 12 | GPIO 18 |
| `GIO2` | MISO | **IO19** | GPIO 5 | GPIO 13 | GPIO 19 |
| `SDIO` | MOSI | **IO20** | GPIO 6 | GPIO 11 | GPIO 23 |
| `CSN`  | chip select | **IO14** | GPIO 7 | GPIO 10 | GPIO 5 |

### Pourquoi IO14 et IO18–20 sur le C6 SuperMini

Cette carte a peu de broches vraiment libres :

- **IO12 / IO13** portent l'USB natif — les utiliser coupe le port série ;
- **IO2, IO4, IO5, IO8, IO9, IO15** sont des broches de *strapping* : leur
  niveau est échantillonné au reset. Un module qui en pilote une pendant le
  démarrage peut empêcher la carte de booter ;
- **IO8** est une LED adressable WS2812 : c'est le voyant d'état du firmware ;
- **IO15** porte une LED simple, laissée en entrée (donc éteinte) par le
  firmware ; **IO9** est le bouton BOOT — le firmware s'en sert déjà.

Restent **IO14** et **IO18–IO20**, toutes sur la rangée qui porte aussi `3V3`,
`GND` et `5V`. Dans l'ordre de la sérigraphie, au dos de la carte :
`8 · 9 · 14 · 15 · 18 · 19 · 20 · 3V3 · GND · 5V`. Les six fils, alimentation
comprise, tiennent donc sur une seule rangée :

```
IO14 ── CSN
IO15    (LED simple, on saute)
IO18 ── SCK
IO19 ── GIO2
IO20 ── SDIO
3V3  ── VDD
GND  ── VSS
```

IO21 et IO22 existent aussi, mais en **trous intérieurs** et non sur le bord
castellé : pénibles à souder, à éviter.

Les broches sont définies par `build_flags` dans [platformio.ini](../platformio.ini) —
change-les là plutôt que dans le code.

> **3,3 V uniquement.** Le BC5602 ne tolère pas le 5 V. L'ESP32 étant lui aussi
> en 3,3 V, aucun adaptateur de niveau n'est nécessaire.

## Points à ne pas négliger

**Découplage (optionnel).** Un 100 nF **plus** un 10 µF au plus près de `VDD`
est une bonne pratique peu coûteuse. Mais tout le projet a été mesuré **sans**
(0 perte au banc hors Thread, 23/09), et le module a vraisemblablement son
propre découplage : rien n'a jamais montré qu'il était nécessaire.

**Cohabitation 2,4 GHz.** Le BenQ travaille à 2405 MHz. Le pont, lui, parle
Thread, de préférence sur un canal loin de la lampe (le 25, à 2475 MHz, chez
l'auteur). Mais chaque émission Thread du C6 désensibilise le BM5602 tout
proche : au banc, 0 trame perdue sans Thread, jusqu'à 18 % de trames sans
accusé avec Thread, toujours rattrapées par les renvois. Deux précautions :

- éloigne l'antenne du module de celle du C6, aux deux bouts du boîtier, et ne
  la pose ni sur un plan de masse ni sous un fil ;
- le canal Wi-Fi 1 (2412 MHz) recouvre celui de la lampe : si ton point
  d'accès est tout près, mets-le sur le canal 11 (2462 MHz) si tu le peux.

**Longueur du bus SPI.** 1 MHz par défaut (`RF_SPI_HZ` dans
[src/config.h](../src/config.h)). Inutile de monter plus haut : une commande
Halo 1 porte 2 octets de charge. Si tu utilises une nappe longue, descends
plutôt à 500 kHz.

**Antenne.** Le BM5602-60-1 embarque une antenne imprimée. Ne la colle pas
contre une masse, un blindage ou un boîtier métallique.

## Vérification

Au démarrage, le moniteur série doit afficher :

```
=== BenQ ScreenBar Halo -> Matter ===
firmware 0.2.0
```

puis, avec `info` :

```
  BM5602        : detecte (version puce 0x......)
```

`ABSENT` signifie que la lecture SPI renvoie `0x000000` ou `0xFFFFFF` :
- `0xFFFFFF` → MISO n'est pas relié, ou relié ailleurs que sur `GIO2` ;
- `0x000000` → pas d'alimentation, `CSN` non relié, ou SCK/MOSI inversés.

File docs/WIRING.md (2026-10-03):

[Français](WIRING.fr.md) · **English**

# Wiring

## BM5602-60-1 module → ESP32

The BM5602 starts up in **3-wire** SPI (`SDIO` bidirectional). The firmware
switches the `IO1` register to **4-wire** mode at init: `GIO2` then becomes
the data output, i.e., the MISO on the ESP32 side.

## BM5602-60-1 module pinout

The module **has no silkscreen markings** on its pads, and the
`BM5602-60-1 V1.0` text is printed on **both sides**: it is not enough to
orient it. Take the **component side**, the one with the chip and the crystal,
antenna at the top: the 9 pads on the bottom edge are then, **left to right**:

| # | 1 | 2 | 3 | 4 | 5 | 6 | 7 | 8 | 9 |
|---|---|---|---|---|---|---|---|---|---|
| | `VSS` | `VDD` | `GIO1` | `CSN` | `SCK` | `GIO2` | `SDIO` | `GIO3` | `GIO4` |
| | GND | 3V3 | — | CS | clock | **MISO** | **MOSI** | — | — |

**On the flat side, the order is reversed**: `GIO4` on the left, `VSS` on
the right. The pads are through-holes, visible from both sides: that is the
trap.

`GIO1`, `GIO3`, and `GIO4` are not used. The two isolated pads on the left
and right edges, near the antenna, are extra `VSS` pads.

**Check before soldering**: with a multimeter in continuity mode, pad 1
(`VSS`) beeps with these isolated pads. It is the only one in the row that
does.

Source: the wiring diagram from the
[Halo 2 project](https://github.com/kuzmin-no/BenQ_ScreenBar_HALO_2_HA_integration/blob/main/img/connection_diagramm.png),
which shows the component side.

| BM5602-60-1 | SPI role | **C6 SuperMini** | ESP32-C3 | ESP32-S3 | ESP32 (WROOM) |
|---|---|---|---|---|---|
| `VDD`  | 3.3 V | 3V3 | 3V3 | 3V3 | 3V3 |
| `VSS`  | GND | GND | GND | GND | GND |
| `SCK`  | clock | **IO18** | GPIO 4 | GPIO 12 | GPIO 18 |
| `GIO2` | MISO | **IO19** | GPIO 5 | GPIO 13 | GPIO 19 |
| `SDIO` | MOSI | **IO20** | GPIO 6 | GPIO 11 | GPIO 23 |
| `CSN`  | chip select | **IO14** | GPIO 7 | GPIO 10 | GPIO 5 |

### Why IO14 and IO18–20 on the C6 SuperMini

This board has few truly free pins:

- **IO12 / IO13** carry the native USB — using them cuts off the serial port;
- **IO2, IO4, IO5, IO8, IO9, IO15** are *strapping* pins: their level is
  sampled at reset. A module driving one of them during boot-up can prevent
  the board from booting;
- **IO8** is an addressable WS2812 LED: it is the firmware's status LED;
- **IO15** carries a simple LED, left as an input (so off) by the firmware;
  **IO9** is the BOOT button — the firmware already uses it.

That leaves **IO14** and **IO18–IO20**, all on the row that also carries
`3V3`, `GND`, and `5V`. In the order printed on the back of the board:
`8 · 9 · 14 · 15 · 18 · 19 · 20 · 3V3 · GND · 5V`. The six wires, power
included, therefore fit on a single row:

```
IO14 ── CSN
IO15    (simple LED, skipped)
IO18 ── SCK
IO19 ── GIO2
IO20 ── SDIO
3V3  ── VDD
GND  ── VSS
```

IO21 and IO22 also exist, but as **inner holes** rather than on the
castellated edge: painful to solder, to avoid.

The pins are defined by `build_flags` in [platformio.ini](../platformio.ini) —
change them there rather than in the code.

> **3.3 V only.** The BC5602 does not tolerate 5 V. Since the ESP32 is also
> 3.3 V, no level shifter is necessary.

## Points not to overlook

**Decoupling (optional).** A 100 nF **plus** a 10 µF as close as possible to
`VDD` is a low-cost good practice. But the whole project was measured
**without** it (0 loss on the bench outside Thread, Sep 23), and the module
most likely has its own decoupling: nothing has ever shown it to be
necessary.

**2.4 GHz coexistence.** The BenQ operates at 2405 MHz. The bridge itself
speaks Thread, preferably on a channel far from the lamp (25, at 2475 MHz, in
the author's home). But every Thread transmission from the C6 desensitizes the
nearby BM5602: on the bench, 0 frames lost without Thread, up to 18 % of frames
without an acknowledgment with Thread, always recovered by the retries. Two
precautions:

- keep the module's antenna away from the C6's, at opposite ends of the
  enclosure, and never over a ground plane or under a wire;
- Wi-Fi channel 1 (2412 MHz) overlaps the lamp's: if your access point is very
  close, move it to channel 11 (2462 MHz) if you can.

**SPI bus length.** 1 MHz by default (`RF_SPI_HZ` in
[src/config.h](../src/config.h)). No need to go higher: a Halo 1 command
carries a 2-byte payload. If you use a long ribbon cable, go down to
500 kHz instead.

**Antenna.** The BM5602-60-1 has a built-in printed antenna. Do not place it
against a ground plane, a shield, or a metal enclosure.

## Verification

At boot, the serial monitor should show:

```
=== BenQ ScreenBar Halo -> Matter ===
firmware 0.2.0
```

then, with `info`:

```
  BM5602        : detecte (version puce 0x......)
```

`ABSENT` means the SPI read returns `0x000000` or `0xFFFFFF`:
- `0xFFFFFF` → MISO is not connected, or connected somewhere other than
  `GIO2`;
- `0x000000` → no power, `CSN` not connected, or SCK/MOSI swapped.

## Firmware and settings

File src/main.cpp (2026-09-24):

// ===========================================================================
//  BenQ ScreenBar Halo (1re generation) -> Matter
//  ESP32 + module RF Holtek BM5602-60-1 (transceiver BC5602)
//
//  L'ESP32 se fait passer pour la telecommande 2.4 GHz de la lampe et l'expose
//  comme un noeud Matter. Matter etant multi-admin, le meme appareil se
//  jumelle simultanement a Apple Home, Google Home, Alexa et Home Assistant.
//
//  Premier demarrage :
//    1. moniteur serie a 115200 bauds
//    2. 'ecoute 4FF0FD63 5' verifie le lien de la lampe (sur l'air 63 FD F0 4F)
//    3. appairage Matter avec le code affiche au demarrage ('matter' le rappelle)
//    4. 'help' pour la liste des commandes
// ===========================================================================

#include <Arduino.h>
#include <esp_app_desc.h>
#include <esp_ota_ops.h>
#include <esp_system.h>
#include <esp_log.h>
#include <stdarg.h>
#include <string.h>
#ifndef DIAG_ONLY
#include <lib/support/logging/CHIPLogging.h>
#endif
#include <sdkconfig.h>

#include "boot_button.h"
#include "cli.h"
#include "config.h"
#include "halo.h"
#include "halo1_lamp.h"
#include "json_mode.h"
#include "status_led.h"
#ifndef DIAG_ONLY
#include "matter_bridge.h"
#include "net.h"
#include "net_udp.h"
#endif

bool chipLogging = false;
static vprintf_like_t previousVprintf = nullptr;

// esp-matter n'emet pas ses traces par les macros ESP_LOGx : ni
// esp_log_level_set() par tag, ni le filtre interne de CHIP ne les arretent
// (on n'obtenait qu'une ligne de prefixe vide, repetee toutes les 5 s).
// Le hook de sortie du log est le seul point de passage obligatoire.
static int quietVprintf(const char *fmt, va_list args) {
  if (!chipLogging) {
    // Le tag est un ARGUMENT du format, pas une partie du format : il faut
    // formater la ligne pour pouvoir l'inspecter.
    char line[256];
    va_list copy;
    va_copy(copy, args);
    int n = vsnprintf(line, sizeof(line), fmt, copy);
    va_end(copy);
    if (n > 0 && strstr(line, "chip[") != nullptr) return 0;  // ligne avalee
  }
  return previousVprintf ? previousVprintf(fmt, args) : vprintf(fmt, args);
}

void setChipLogging(bool on) {
  chipLogging = on;
  if (!previousVprintf) previousVprintf = esp_log_set_vprintf(quietVprintf);
#ifndef DIAG_ONLY
  chip::Logging::SetLogFilter(on ? chip::Logging::kLogCategory_Progress : chip::Logging::kLogCategory_None);
#endif
  esp_log_level_t level = on ? ESP_LOG_INFO : ESP_LOG_NONE;
  for (const char *tag : {"chip[DL]", "chip[SVR]", "chip[DIS]", "wifi"}) esp_log_level_set(tag, level);
}

// Sur l'USB natif du C6, un redemarrage fait re-enumerer le port et le moniteur
// ne se rattache pas : une panique passe donc inapercue, sans meme un message.
// Cette cause reste lisible pendant toute la session, d'ou la commande 'cause'.
const char *resetReasonText() {
  switch (esp_reset_reason()) {
    case ESP_RST_POWERON:  return "mise sous tension";
    case ESP_RST_EXT:      return "broche de reset";
    case ESP_RST_SW:       return "redemarrage logiciel";
    case ESP_RST_PANIC:    return "PANIQUE (exception)";
    case ESP_RST_INT_WDT:  return "CHIEN DE GARDE des interruptions";
    case ESP_RST_TASK_WDT: return "CHIEN DE GARDE de tache";
    case ESP_RST_WDT:      return "CHIEN DE GARDE (autre)";
    case ESP_RST_BROWNOUT: return "BAISSE DE TENSION";
    case ESP_RST_USB:      return "reinitialisation par l'USB";
    default:               return "inconnue";
  }
}

void setup() {
  // L'USB Serial/JTAG jette les octets des que son tampon d'emission sature
  // (tx_timeout_ms = 100 par defaut dans le core) : le banner de demarrage
  // arrivait deja tronque. On agrandit le tampon et on demande a write()
  // d'attendre plutot que de perdre des donnees -- les bilans des outils de
  // banc sont des rafales, et c'est la sortie qu'on peut le moins se permettre
  // de perdre.
#if defined(ARDUINO_USB_CDC_ON_BOOT) && ARDUINO_USB_CDC_ON_BOOT && defined(ARDUINO_USB_MODE) && \
    ARDUINO_USB_MODE == 1
  Serial.setTxBufferSize(4096);
  Serial.setTxTimeoutMs(1000);
#endif
  Serial.begin(115200);
  delay(400);
  // Identifiant de ce demarrage (protocole JSON, hello.boot) : avant toute
  // radio de l'ESP32, donc avant matterBridgeBegin().
  jsonBegin();

  statusLedBegin();  // WS2812 au noir, IO15 en entree (bogue B9)
  // Bouton BOOT (redemarrage, desappairage) : releve des le premier tour de
  // loop() ; tenu a ce moment, il est ignore jusqu'a son relachement. Pose
  // aussi la garde de tous les esp_restart() (IO9 relue haute avant le
  // reset) : avant netBegin() et matterBridgeBegin(), pour passer apres
  // leurs gestionnaires d'arret.
  bootButtonBegin();

  // Tant que le noeud n'est pas mis en service, la pile Matter repete une
  // erreur reseau toutes les 5 s. C'est normal (pas encore d'identifiants
  // Wi-Fi), mais ca noie la sortie des captures RF. Reactivable avec 'chiplog'.
  setChipLogging(false);

  Serial.println();
  Serial.println("=== BenQ ScreenBar Halo -> Matter ===");

  Serial.print("  cause du dernier demarrage : ");
  Serial.println(resetReasonText());
  // Meme chaine que le "Programme interne" d'Apple Home : celle du descripteur
  // d'application (src/app_desc.c). Deux controles : le symbole lie, que lit la
  // pile Matter, et le descripteur en tete de l'image flashee, que lisent le
  // chargeur d'amorcage et esptool. Le premier differe si app_desc.c n'est pas
  // lie, le second aussi s'il n'est plus place en tete de .flash.appdesc.
  Serial.printf("firmware %s\n", FW_VERSION_FULL);
  if (strcmp(esp_app_get_description()->version, FW_VERSION_FULL))
    Serial.printf("!! descripteur d'application : %s (src/app_desc.c pas lie ?)\n",
                  esp_app_get_description()->version);
  {
    esp_app_desc_t flashed;
    const esp_partition_t *running = esp_ota_get_running_partition();
    const esp_err_t err = running ? esp_ota_get_partition_description(running, &flashed) : ESP_ERR_NOT_FOUND;
    if (err != ESP_OK)
      Serial.printf("!! descripteur de l'image flashee illisible (%s)\n", esp_err_to_name(err));
    else if (strncmp(flashed.version, FW_VERSION_FULL, sizeof(flashed.version)))
      Serial.printf("!! descripteur de l'image flashee : %.*s (src/app_desc.c plus en tete de l'image ?)\n",
                    (int)sizeof(flashed.version), flashed.version);
  }

  if (!halo.begin()) {
    Serial.println();
    Serial.println("!! Module BM5602 introuvable.");
    Serial.printf("!! Verifie le cablage SPI : SCK=%d MISO=%d MOSI=%d CSN=%d\n", PIN_RF_SCK, PIN_RF_MISO,
                  PIN_RF_MOSI, PIN_RF_CSN);
    Serial.println("!! (MISO va sur GIO2, MOSI sur SDIO -- voir docs/WIRING.md)");
    Serial.println("!! Matter demarre quand meme, mais la lampe ne repondra pas.");
  }
  // Rien n'est emis au demarrage : l'ancien HELLO (protocole Halo 2, pollNow)
  // est retire, la lampe est un Halo 1 (plan du pilote Halo 1, etape C1).
  // Le pilote reprend l'etat sauve et se met en ecoute passive (produit) ou en
  // veille (diagnostic) ; halo.begin() lui sert de relance du module.
  lamp.begin(halo.radio, HALO1_LISTEN_DEFAULT, []() { return halo.begin(); });
  jsonAttach();  // evenements du pilote et de la LED vers le mode machine
  {
    char st[48];
    Halo1Lamp::describe(lamp.target(), st, sizeof(st));
    Serial.printf("Lampe Halo 1 : %s, ecoute %s ('lampe' pour le detail)\n", st,
                  lamp.listening() ? "active" : "coupee");
  }

#ifndef DIAG_ONLY
  netBegin();
  matterBridgeBegin();
  setChipLogging(false);  // l'init de la pile peut avoir repose son propre filtre
#if MATTER_NET_THREAD
  // Transport reseau de l'app (UDP sur Thread) : cle lue en NVS ; le socket
  // s'ouvre au premier tour de loop() ou OpenThread est libre.
  netUdpBegin();
#endif
#else
  Serial.println();
  Serial.println("*** BUILD DIAGNOSTIC : Matter, Wi-Fi et BLE desactives.");
  Serial.println("*** La radio de l'ESP32 est muette : l'environnement RF est propre.");
#endif

#ifndef DIAG_ONLY
  if (!matterIsCommissioned()) {
    Serial.println();
    Serial.println("Noeud Matter pas encore mis en service : ajoute l'accessoire");
    Serial.println("depuis ton application domotique avec les identifiants ci-dessous.");
  }
  matterPrintStatus(Serial);
#endif

  cliBegin();
}

void loop() {
  lamp.tick();
#ifndef DIAG_ONLY
  matterBridgePoll();
#endif
  cliPoll();
#if MATTER_NET_THREAD
  // Commandes de l'app par le reseau, comme celles de l'USB ; emission des
  // datagrammes mis en file au tour precedent.
  netUdpPoll();
#endif
  // Apres toute consigne (tick, Matter, CLI, reseau) et avant la LED : la livraison
  // precede l'eclat vert ou rouge (docs/PROTOCOLE-JSON.md, 12.2).
  jsonPoll();
  // Avant la LED, qui montre sa phase ; peut redemarrer la carte (seulement
  // bouton relache, broche relue haute : IO9 est une broche de strapping).
  bootButtonPoll();
  statusLedPoll();
  // Cede la main a IDLE et aux taches moins prioritaires : tick() tourne ainsi
  // a ~1 kHz, assez pour l'ecoute passive.
  delay(1);
}

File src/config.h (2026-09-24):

#pragma once
#include <Arduino.h>

// ===========================================================================
//  Cablage SPI vers le module BM5602-60-1
//  (les valeurs par defaut sont surchargees par build_flags dans platformio.ini)
// ===========================================================================
#ifndef PIN_RF_SCK
#define PIN_RF_SCK 18
#endif
#ifndef PIN_RF_MOSI          // -> broche SDIO du BM5602
#define PIN_RF_MOSI 23
#endif
#ifndef PIN_RF_MISO          // <- broche GIO2 du BM5602 (mode 4 fils)
#define PIN_RF_MISO 19
#endif
#ifndef PIN_RF_CSN
#define PIN_RF_CSN 5
#endif
// Broches d'ecoute du bus SPI d'un appareil tiers (commande 'sniffspi').
// MISO n'existe pas ici : on n'ecoute que le sens microcontroleur -> puce,
// et surtout on ne pilote JAMAIS une ligne du bus observe.
// Dialogue SWD avec un microcontroleur tiers. SWCLK est connu (trou 3 de J5,
// seul a se tenir pres de 0 V par son tirage interne) ; SWDIO est cherche
// parmi plusieurs broches, pour ne pas avoir a recabler entre chaque essai.
// GIO3 du module (pastille 8), non cablee d'origine. Contrairement a GIO2,
// elle ne sert pas au SPI : on peut donc balayer son selecteur sans perdre
// la liaison avec la puce, et compter les trames recues pendant la mesure.
#ifndef PIN_GIO3_TAP
#define PIN_GIO3_TAP 3

#endif

// --- Module CC2500 (24TRGC5-V4), sur sa propre carte -----------------------
// Valeurs de depart seulement : la commande 'ccpins' les change a chaud, sans
// reflasher, parce qu'on ne sait pas d'avance quelles broches la carte expose.
#ifndef PIN_CC_SCK
#define PIN_CC_SCK 18
#endif
#ifndef PIN_CC_MISO
#define PIN_CC_MISO 19
#endif
#ifndef PIN_CC_MOSI
#define PIN_CC_MOSI 20
#endif
#ifndef PIN_CC_CSN
#define PIN_CC_CSN 14
#endif
#ifndef PIN_CC_GDO0
#define PIN_CC_GDO0 3
#endif
#ifndef PIN_CC_GDO2
#define PIN_CC_GDO2 15
#endif
#ifndef PIN_CC_PA_EN
#define PIN_CC_PA_EN 7
#endif
#ifndef PIN_CC_RX_EN
#define PIN_CC_RX_EN 6
#endif

#ifndef PIN_SWD_CLK
#define PIN_SWD_CLK 18
#endif

#ifndef PIN_TAP_SCK
#define PIN_TAP_SCK 6
#endif
#ifndef PIN_TAP_MOSI
#define PIN_TAP_MOSI 7
#endif
#ifndef PIN_TAP_CS
#define PIN_TAP_CS 11
#endif

#ifndef PIN_STATUS_LED
#define PIN_STATUS_LED 2
#endif

// Le datasheet BC5602 autorise plus, mais le module a des pistes courtes non
// adaptees : 1 MHz est largement suffisant et reste tres fiable.
#ifndef RF_SPI_HZ
#define RF_SPI_HZ 1000000UL
#endif

// ===========================================================================
//  Matter
// ===========================================================================
// FW_VERSION, FW_GIT_REV et FW_VERSION_FULL : fw_version.h (platformio.ini).
#include "fw_version.h"

// Identite du noeud (Basic Information, EP0), decisions de Djoko du 23/09.
// Posee a chaque demarrage avant Matter.begin() (matter_bridge.cpp) ; le VID et
// le PID restent ceux du certificat de test (0xFFF1 / 0x8000) : les changer
// casserait l'appairage. Chaines de 32 caracteres au plus (64 pour la version
// materielle), verifie a la compilation. Numero de serie : prefixe + adresse
// MAC d'usine en 12 chiffres hexa, unique par carte. La version logicielle
// ("Programme interne") est FW_VERSION_FULL, via src/app_desc.c.
#ifndef MATTER_VENDOR_NAME
#define MATTER_VENDOR_NAME "Djoko-CLI"
#endif
#ifndef MATTER_PRODUCT_NAME
#define MATTER_PRODUCT_NAME "Pont ScreenBar Halo"
#endif
#ifndef MATTER_NODE_LABEL
#define MATTER_NODE_LABEL "Halo"              // NodeLabel, reecrit a chaque demarrage
#endif
#ifndef MATTER_HW_VERSION
#define MATTER_HW_VERSION 1
#endif
#ifndef MATTER_HW_VERSION_STRING
#define MATTER_HW_VERSION_STRING "ESP32-C6 SuperMini + BM5602"  // montage de reference
#endif
#ifndef MATTER_SERIAL_PREFIX
#define MATTER_SERIAL_PREFIX "HALO1-"
#endif

// Bouton BOOT : appui court = redemarrage, appui de 8 s puis relachement =
// retrait de toutes les fabriques Matter (decommissioning), pour re-appairer
// l'accessoire de zero. Durees et garde-fous : src/boot_button.h.
#ifndef PIN_DECOMMISSION_BTN
#ifdef BOOT_PIN
#define PIN_DECOMMISSION_BTN BOOT_PIN
#else
#define PIN_DECOMMISSION_BTN 0
#endif
#endif

// Certaines cartes cablent la LED d'etat a l'envers (broche -> LED -> 3V3).
#ifndef STATUS_LED_ACTIVE_LOW
#define STATUS_LED_ACTIVE_LOW 0
#endif

// LED d'etat RGB adressable (WS2812) : PIN_RGB_STATUS_LED, donnee par
// platformio.ini (IO8 sur le C6 SuperMini). Definie, c'est elle le voyant, et
// la LED simple de PIN_STATUS_LED reste en entree ; sinon la LED simple suit les
// memes motifs en tout ou rien (status_led.h). Ordre des couleurs : GRB, celui
// de la WS2812B ; si 'led test' montre du rouge au lieu du vert, passer a
// LED_COLOR_ORDER_RGB.
#ifndef STATUS_RGB_ORDER
#define STATUS_RGB_ORDER LED_COLOR_ORDER_GRB
#endif
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

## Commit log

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2026-09-22 Rendre explicite la longueur de preambule de la balise d'etalonnage
    La chasse par le preambule cherche un motif 'AA AA X', soit deux octets de
    preambule suivis du premier octet d'adresse. La balise emettait jusqu'ici
    avec la valeur par defaut de la puce, un seul octet : le motif n'existait
    pas sur l'air et la validation aurait echoue pour une raison etrangere a la
    technique testee.
    'etalon tx <secondes> <1|2>' fixe desormais CFO1 bit 6 et affiche le motif
    attendu sur l'air, polarite comprise -- celle-ci etant determinee par le
    premier bit de l'adresse (ds.txt:1409).
    [cli.cpp, halo.cpp]
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2026-09-22 Ecoute passive du bus SPI d'un appareil tiers
    L'adresse du lien radio est ecrite en clair sur le bus SPI interne de la
    telecommande au demarrage, par la commande 0x10 (write PTX address). C'est
    la derniere voie pour l'obtenir : le correlateur du BC5602 l'exige, et on a
    demontre qu'aucune ruse ne le contourne.
    La capture passe par le peripherique SPI en mode ESCLAVE plutot que par un
    echantillonnage GPIO : cadence par l'horloge observee, il reconstitue les
    octets exactement, la ou une boucle a 3 MHz raterait des bits face a une
    horloge a 1 ou 2 MHz. MISO reste non assigne, donc la carte ne pilote jamais
    aucune ligne du bus observe.
    [cli.cpp, config.h, halo.cpp]
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2026-09-22 Outiller la capture SPI : etat en direct et cinq correctifs
    Capture a six transactions pre-armees au lieu d'une seule, tri du bruit a la
    volee plutot qu'a l'affichage, file videe avant liberation du peripherique,
    restitution complete sur 32 octets, et affichage place avant tout demontage
    pour qu'un incident ne puisse plus emporter une capture reussie.
    Le suivi du contact devient continu et s'affiche pendant la capture elle-meme :
    niveaux des trois lignes et compteurs une fois par seconde, sans flush, pour
    pouvoir ajuster les fils sans rendre la carte sourde.
    Le test de contact exigeait seulement que les lignes ne suivent pas les
    resistances internes. Sans pile, tout est tire vers la masse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
    [cli.cpp, halo.cpp]
2026-09-22 Dialoguer en SWD avec le microcontroleur de la telecommande
    J5 est le connecteur de programmation : six trous traversants qui acceptent
    une Dupont par friction, ce qui supprime le probleme de contact qui bloque
    la capture du bus SPI. Le trou 1 est la masse, le trou 3 est SWCLK -- seul a
    se tenir pres de 0 V quand les autres sont a 2,49 V.
    Le protocole est genere en bit-banging : reset de ligne, bascule JTAG vers
    SWD, puis requetes de 8 bits, acquittement de 3 bits et donnees de 32 bits
    avec leurs cycles de retournement. La commande cherche elle-meme quelle
    broche est SWDIO parmi plusieurs reliees d'un coup, et ne se contente pas de
    l'IDCODE : elle demande la mise sous tension du domaine de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
    [cli.cpp, config.h, swd.cpp]
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2026-09-22 Demontrer que l'accrochage en milieu de trame est impossible
    La commande 'find' donnait au correlateur trois octets de payload comme
    pseudo-adresse, procede jamais valide. Teste contre la balise dont le
    payload est connu, avec 2895 emissions confirmees et un recepteur valide le
    meme jour : aucune des huit fenetres n'accroche.
    Le correlateur ne se cale qu'apres un preambule valide. 'find' etait donc
    condamnee des le depart, comme l'accrochage sur le preambule, et il ne reste
    plus aucune voie purement RF vers l'adresse.
    Le bandeau de la balise affichait un debit code en dur, devenu faux depuis
    que le debit est reglable -- meme defaut que celui corrige sur 'appaire'.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
    [cli.cpp, halo.cpp]
2026-09-22 Corriger un faux negatif : l'accrochage en plein payload est possible
    La section precedente affirmait le contraire, demonstration a l'appui. La
    demonstration ne valait rien : le payload de balise utilise n'avait aucune
    suite alternee de plus de sept bits, donc aucune de ses huit fenetres
    n'etait precedee d'un octet capable d'armer le detecteur de preambule.
    Refait avec une ancre 0x55 dans le payload : un positif, sept negatifs.
    Seule la fenetre precedee du 0x55 accroche, et la FIFO rend exactement les
    octets qui la suivent. Le script find_addr.py de kuzmin le disait deja --
    le 0x55 y est 'used as preambule and part of the sync word'.
    Le procede de 'find' est donc valide. Ses echecs viennen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
    [cli.cpp, config.h, halo.cpp]
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2026-09-22 Consigner l'etat complet avant reprise
    Le debit est tranche par le rapport FCC : largeur occupee de 430-447 kHz
    croisee avec les excursions du datasheet, ce qui designe 125 kbps et exclut
    les deux autres. A ce debit, la duree de rafale correspond a une trame de
    onze octets contre dix-neuf pour le Halo 2 : deux a quatre octets de payload
    seulement. La structure de trame du Halo 1 n'est donc pas celle du Halo 2,
    ce qui explique l'echec des chasses par fenetre de payload.
    Reste une contradiction ouverte : la telecommande emet et porte un BC5602,
    mais notre BC5602 ne detecte jamais son preambule malgre le balayage de 84
    canaux, 3 debits, 2 longueurs de preambule, 3 largeurs d'adresse et deux
    se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
    [cli.cpp, halo.cpp]
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2026-09-22 Rejouer les reglages analogiques apres chaque reset, et valider le fil GIO3
    Mesure 'survie' : le reset logiciel efface 15 des 19 valeurs recommandees
    par Holtek. Comme toute configuration commence par un reset, ces valeurs
    n'avaient jamais ete actives pendant une ecoute : toutes les chasses ont
    tourne sur un modem aux valeurs d'usine.
    registerConfigure() est desormais rejoue apres chaque reset dans les deux
    chemins de configuration, et la mesure imprime elle-meme son temoin de
    reglage (18 sur 19 en place, contre 4 auparavant).
    Nouvelle commande 'fil' : test purement electrique du fil GIO3, selecteur
    par selecteur, contre les resistances internes de l'ESP32. Il distingue un
    fil debranche d'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
    [bc5602.cpp, bc5602.h, cli.cpp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]
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2026-09-22 Corriger une conclusion fausse : GIO3 n'est pas en amont du correlateur
    Le controle etait confondu : l'adresse dite fausse ne differait de la vraie
    que de deux bits, et le correlateur du BC5602 tolere quelques bits d'erreur.
    Avec une adresse reellement differente, le detecteur reste muet.
    Consequence : les resultats nuls de la journee signifient « on n'a pas la
    bonne adresse », et non « le signal est indetectable ». La voie RF n'est pas
    close, contrairement a ce que le commit precedent affirmait.
    Ajoute la commande 'amont', qui reproduit prepare_halo_receive() du projet
    Termina1 : aucun reset logiciel, CRC et auto-ACK desactives, payload
    statique de 13 octets. Mesure : 789 trames en 15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
    [cli.cpp, halo.cpp]
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2026-09-22 Corriger un redemarrage par le chien de garde des interruptions
    Les boucles de capture masquaient les interruptions pendant toute une
    capture : 32768 bits a 125 kbit/s font 260 ms, et davantage aux debits plus
    lents du balayage. Le chien de garde des interruptions se declenche a 300
    ms -- la carte a redemarre en plein balayage de debit, cause confirmee par
    'cause du dernier demarrage : CHIEN DE GARDE des interruptions'.
    Toutes les captures passent par ccSampleBits, qui masque par tranches de
    8192 bits (65 ms) en rendant la main entre elles. Le prix est au pire une
    trame perdue par tranche.
    Ajoute aussi la lecture large de la FIFO (32 octets) avec extraction des
    retransmissions par recherch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
    [cli.cpp, halo.cpp]
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2026-09-22 Ajouter le reglage du trim de quartz du BM5602 (XO1)
    Mesure a l'appui : sur les retransmissions dont l'adresse est connue, les
    erreurs binaires sont a 100 % des 1 lus comme 0 -- 29 contre 0 sur sept
    retransmissions uniques -- et tombent toujours sur le dernier 1 avant une
    transition. C'est la signature d'un seuil de decision decale, donc d'un
    ecart de frequence porteuse entre la telecommande et le recepteur.
    Le reglage fin de la porteuse du BC5602 est XO_TRIM (XO1, banque 0,
    registre 0x38, bits 4-0), valeur de mise sous tension 16, jamais touche
    jusqu'ici. Le projet amont le regle a 0x15. Commande 'xo [0..31]' ; la
    valeur est memorisee et reappliquee apres chaque reset logiciel, sans quoi
    l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
    [bc5602.h, cli.cpp, config.h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]
2026-09-22 Emettre une trame Halo 1 et verifier l'emission bit pour bit
    Commande 'tx6 <hex12> [n] [ms]' : moteur de paquets, charge utile statique
    de 6 octets, CRC materiel, sans acquittement -- le chemin de la balise.
    Verifie par le CC2500 : la trame 06 B9 21 BB 98 FF est emise avec le CRC 7A
    FF, exactement celui de la trame recue de la telecommande, et relue trois
    fois avec CRC valide. 300 emissions, 300 confirmees par TX_DS.
    Ce controle montre aussi que nos deux radios fonctionnent : le CC2500 relit
    proprement nos trames alors qu'il n'a jamais relu proprement celles de la
    telecommande.
    Ajoute aussi un mode 'valeurs par defaut' a la reception ('holtek 0') :
    teste en alternance contre les valeurs r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
    [cli.cpp, halo.cpp]
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2026-09-22 Emettre et recevoir au format BC5602 standard avec accuse automatique
    Commandes 'txack' (emetteur, charge dynamique, PCF et CRC generes par la
    puce, accuse demande, verdict TX_DS ou MAX_RT par essai) et 'prxack'
    (recepteur de banc qui accuse automatiquement). RT1 = 0x73 (2 ms, 3
    retransmissions). Garde-fous : jamais l'adresse d'appairage ni un octet de
    tete 0x0A ; sur le canal de la lampe, 10 essais au plus espaces de 500 ms.
    Banc entre les deux BM5602, canal 40 et adresse de test, lampe non
    concernee : 8 accuses sur 10 vers l'adresse ecoutee, 0 sur 10 vers une
    adresse que personne n'ecoute. Le recepteur relit 'longueur 2 : C4 FE'.
    Reste a comprendre : apres un premier MAX_RT, les essais su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
    [cli.cpp, halo.cpp]
2026-09-23 Reconfigurer la radio apres un echec d'emission avec accuse
    Banc du 23/09 : apres un premier MAX_RT, les essais suivants echouaient en
    64 us, file d'emission pleine et compteur de pertes montant. Reconfiguration
    complete apres chaque echec, jamais apres un succes (le PID doit avancer).
    Verifie sur le banc, canal 40 : 7 echecs pendant que le recepteur n'ecoutait
    pas, chacun un cycle complet de 11,5 ms, puis 5 accuses d'affilee des son
    demarrage, et 5 trames comptees de l'autre cote.
    [halo.cpp]
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2026-09-23 Ecoute passive au format standard, decodage logiciel du PCF et du CRC
    Commande 'ecoute <adresse> <canal> [ms]' : recepteur qui n'accuse JAMAIS
    (pour ne pas entrer en collision avec l'accuse de la lampe), longueur fixe
    de 8 octets apres l'adresse, decodage logiciel du PCF de 9 bits et du CRC
    init 0xFFFF sur adresse + PCF + charge.
    Valide sur le banc, canal 40, adresse de test : C4 FE puis C4 80, neuf
    trames chacune, toutes au CRC valide. La premiere version recevait une
    rafale puis restait sourde a la suivante : rearmement explicite apres
    chaque trame, et de securite toutes les 100 ms.
    [cli.cpp, halo.cpp]
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2026-09-23 Corriger les points de revue de l'etape C1
    Suite de l'etape C1 (plan du pilote Halo 1, F.1 et J.18 : l'adresse
    d'appairage est refusee partout).
    - cli.cpp : la table des adresses d'appairage (Halo 2 E2 08 00 B0, Halo 1
    59 01 00 B0, dans les deux ordres) devient isPairingAddr(). txack l'appelle
    toujours ; prxack et addr la consultent aussi. prxack accuse tout ce qui
    arrive (ENAA=1) : sur la balise, il clorait l'appairage de la telecommande
    sans que la lampe apprenne rien (PROTOCOL.md, pair-4). addr alimente tx6
    et txraw, qui emettent sur cette adresse.
    - Aide : poll, tail, find, pair, sniff et send n'y figurent plus, une ligne
    les signale retirees ; 'ecoute B0000159 5' pour l'appa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
    [cli.cpp, halo.cpp, main.cpp]
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2026-09-23 Extraire la radio Halo 1
    Etape C3 du plan du pilote Halo 1 (sections B.4, C.1 a C.9, F.4).
    - halo1_radio : configStdAutoAck quitte halo.cpp, decoupe autour de ses
    2 x 20 ms d'attente : halo1StdReset (reset seul), halo1StdConfigure
    (corps identique, relu ligne a ligne), halo1PassiveOverrides (ENAA,
    DPL2, DPL1, PKT1, RXPW0 de l'ecoute). configStdAutoAck = reset +
    delay(40) + configuration : meme sequence et memes durees pour txack,
    ecoute et prxack. L'armement de sniffStd appelle halo1PassiveOverrides
    (memes ecritures, meme ordre). applyXoTrim n'est plus static : le
    pilote applique le trim memorise par 'xo'.
    - Halo1Radio : les memes sequences sans bloquer sur le reset. Reset puis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
    [bc5602.h, cli.cpp, config.h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]
2026-09-23 Corriger les points de revue de l'etape C3
    - Halo1Radio : plus aucune lecture entre un reset et la configuration qui
    le suit. La puce y est en SPI 3 fils et GIO2 n'emet rien : readConfig
    (futur 'lampe regs') rendait des RFCH/DM1/RT1 faux ~7 % du temps en
    ecoute (40 ms de reset toutes les ~540 ms). Un drapeau spi3Wire_, pose
    au reset et leve apres halo1StdConfigure (ou par begin/restartDone,
    apres halo.begin()), survit a un invalidate() qui coupe le reset ;
    readable() l'expose, readConfig rend false tant qu'il est leve.
    - Instantanes : un silence qui suit un silence reprend sa case. Au calme,
    une reconfiguration de silence toutes les ~540 ms chassait en ~2 s les
    instantanes d'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
    [bc5602.h, cli.cpp, halo1_radio.cpp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]
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2026-09-23 Corriger les points de revue de l'etape C4
    - Attente apres la telecommande (D.8) : une tranche armee par une trame
    de la telecommande (reglage differe libere par elle) partait ~40 ms
    apres sa 1re copie, pendant les 2 suivantes. pendingSince_ restait date
    de la demande differee (ou a 0 apres une rafale finie). tick() le remet
    a 0 au repos sans tranche active, et le pose au premier passage ou une
    tranche est active : attente jusqu'a 250 ms apres la derniere copie,
    2 s au plus.
    - 'lampe croire' n'emet plus rien (B.5, D.2, G.2) : believe() ne fait
    suivre la consigne qu'aux tranches deja actives et n'en arme jamais de
    nouvelle ; un reglage differe reste a livrer jusqu'a la prochai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
    [cli_lampe.cpp, halo1_lamp.cpp, halo1_radio.cpp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]
2026-09-23 Brancher le pont Matter sur le pilote Halo 1
    Reecriture de matter_bridge.cpp selon la section E du plan, disposition A1 (a) :
    EP1 "Halo" (lumiere a temperature de couleur : marche, luminosite unique,
    temperature), EP2 "Halo avant" et EP3 "Halo arriere" en lumieres marche/arret
    (marche ET lampe), EP4 "Halo auto" en prise momentanee qui envoie un appui sur
    le bouton A. L'interrupteur capteur, la prise maitre et la luminosite arriere
    disparaissent : le pont ne touche plus a la couche Halo 2 (halo.desired,
    requestPush), il ne parle qu'au pilote 'lamp'.
    Les callbacks par attribut (jamais onChange, qui transmet les valeurs en cache
    des autres attributs) tournent dans la tache CHIP : ils deposent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
    [matter_bridge.cpp]
2026-09-23 Corriger les points de revue de l'etape C5
    - Niveau ecrit par la pile (E.4, E.6-1) : sur EP1, LevelControl a la
    fonction OnOff, et un On/Off y deplace CurrentLevel (minimum, puis
    niveau garde, ou minimum si un controleur a fixe OnLevel). Ce niveau
    arrivait dans la fenetre de l'ordre marche et passait pour un ordre de
    luminosite : apres un simple "eteins", FLD_BRIGHT restait a livrer lampe
    eteinte, et partait (C5 xx) au prochain allumage a la telecommande, en
    reaction a une trame entendue ; avec OnLevel fixe, au minimum.
    resolveMatter ecarte desormais un niveau venu avec EP1 off, ou avec EP1
    on et egal au niveau affiche pour la consigne (A4 (a) envoie deja la
    luminosite a l'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
    [halo.cpp, matter_bridge.cpp]
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2026-09-23 Ajouter une cible Matter sur Thread pour Apple Home
    Etude du 23/09 : avec le core 3.3.8, l'EP0 n'annonce que le Wi-Fi (le pilote
    Thread est fige sur l'EP2, qui est ici Halo avant) et Apple Home passerait en
    Wi-Fi. Le core 3.3.12 (pioarduino 55.03.312-1, PlatformIO >= 6.2.0) apporte
    Matter.selectNetwork(MATTER_NETWORK_THREAD) : mise en service Thread sur l'EP0,
    Wi-Fi jamais initialise (redirection InitWiFiStack verifiee dans l'ELF).
    Nouvel env esp32c6thread ; tous les envs passent au core 3.3.12, PlatformIO
    n'en gardant qu'un. 'matter' affiche le role, le canal Thread (11 = 2405 MHz,
    la frequence de la lampe) et la puissance. Option MATTER_THREAD_MED.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
    [matter_bridge.cpp, net.cpp]
2026-09-23 Faire taire Thread pendant chaque paquet lampe
    Terrain du 23/09 : en Matter sur Thread (+20 dBm, canal 25 = 2475 MHz, a
    quelques cm du BM5602 qui parle a la lampe sur 2405 MHz), des paquets lampe
    finissent en MAX_RT par rafales juste apres chaque commande Apple Home :
    17/250 en routeur, 19/64 en MED, 0 au banc sans Thread. Hypothese : nos
    propres trames Thread (reponse a l'ecriture, rapports) chevauchent l'echange
    de ~1,6 ms.
    Halo1Radio::sendOne appelle desormais deux crochets (Halo1AirGuard) autour
    de chaque paquet, de la premiere ecriture a CE=0, jamais entre deux paquets ;
    le pilote ne depend ni d'OpenThread ni de Matter. Le build Thread les
    fournit : verrou OpenThread (20 ms au plus, si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
    [cli_lampe.cpp, config.h, halo1_lamp.cpp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]
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2026-09-23 Corriger l'affichage Apple Home du minimum et du bouton A
    Retours du terrain (Apple Home sur Thread, 23/09) :
    - Lampe au minimum 0x4C (molette, ou C5 4C renvoye par le switch),
    Apple Home la montrait PLEINE : CurrentLevel valait 1, soit 0,39 %,
    arrondi a 0 %, et une lumiere allumee a 0 % s'y affiche au maximum.
    Aucun niveau sous kMatterLevelFloor = 3 (1,2 %, donc 1 % arrondi ou
    tronque) n'est plus rapporte : levelFromRaw et displayLevel ne
    descendent jamais sous le plancher, et raw(0..3) = 0x4C quel que soit
    gamma, pour que le niveau rapporte du minimum y revienne exactement.
    A gamma 2 la table ne change pas (niveaux 1..14 deja a 0x4C) ; a
    gamma 1 (banc), 0x4D n'est plus att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
    [cli.cpp, config.h, halo1_lamp.cpp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]
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2026-09-23 Laisser IO15 en entree et dater les effets Identify par endpoint
    Suite des relectures du voyant WS2812 (c4aa1b7) :
    - builds produit avec WS2812 : la LED simple d'IO15 passe en entree au
    lieu d'une sortie basse. Eteinte quelle que soit sa polarite (jamais
    verifiee), et plus de conflit avec GDO2 du CC2500 quand la carte de
    capture est branchee (bogue B9). monoWrite() n'existe plus que sans
    WS2812 ;
    - build diagnostic : la WS2812 est mise au noir une fois au demarrage.
    Elle garde sa derniere couleur a travers un reset ou un flash, et le
    bleu d'un build produit restait allume sur le banc ;
    - TriggerEffect : une fin par endpoint au lieu d'une seule partagee
    (un Stop sur un endpoint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
    [config.h, main.cpp, matter_bridge.cpp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]
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2026-09-23 Corriger les suites de revue de l'identite Matter et d'EP4
    README : la note de remise en service (ancienne disposition des
    endpoints) quitte la section Identite et ne vise plus que cette
    disposition ; le passage a la 0.3.0 depuis EP1..EP4 se fait par-dessus,
    sans effacement ni decommission. Les commandes de reflash nomment l'env
    esp32c6thread (la commande sans -e mettrait le build Wi-Fi sur le noeud
    Thread). 'matter' relit l'identite dans la pile sauf le NodeLabel,
    indique comme valeur demandee. esptool se lance par pio pkg exec.
    tools/git_rev.py : git --no-optional-locks, pour ne pas prendre
    .git/index.lock pendant un commit lance en parallele ; un fichier non
    suivi dans src/, include/ ou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
    [cli.cpp, main.cpp, matter_bridge.cpp]
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2026-09-23 Relancer le module sur symptome de puce
    Incident du 24/09 : une pointe de pied a coulisse sur le quartz du BM5602
    l'a bloque 70 min (tous les envois en delai, 99,8 % de CRC faux en
    ecoute) alors que RFCH/DM1/RT1 se relisaient justes : la verification ne
    voyait rien et la reconfiguration L1 ne guerissait pas ; seul 'rfinit'
    (halo.begin()) a gueri.
    - halo1_watch (code pur, teste sur l'hote) : relance L2 sur 3 delais TX
    de suite (un accuse ou un MAX_RT remet la serie a zero, MAX_RT ne
    relance jamais) ou sur un deluge en ecoute (au moins 100 trames en
    10 s dont au moins 90 % de CRC faux) ; rien sur une lampe muette.
    - Une relance au plus par minute ; apres 3 relances de suite sans
    gueri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
    [halo1_lamp.cpp, halo1_watch.h, status_led.cpp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]
2026-09-23 Corriger les suites de revue de la relance sur symptome
    - Chiffres de l'incident corriges (plan C.5, README, halo1_watch.h) :
    1566/1812 DELAI et 96 403 trames (99,8 % de CRC faux) sont comptes
    depuis le demarrage, sans rythme connu ; la phase finale est sourde
    (0 trame, 350 a 450 rearmements par seconde sur OMST != RX, 186 DELAI
    de suite). Elle n'est vue qu'a la commande suivante, par les delais ;
    l'essai hote ne se dit plus "incident".
    - 'lampe stats' compte a part les rearmements hors RX, pour mesurer leur
    rythme normal avant de decider d'un symptome "ecoute sourde" (hors de
    la specification convenue, non ajoute).
    - Guerison par l'ecoute : fenetre sans deluge ET majoritaireme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
    [halo1_lamp.cpp, halo1_radio.cpp, halo1_radio.h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]
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2026-09-23 Corriger les suites de revue de l'ecoute sourde
    - halo1_watch : la guerison apres une relance pour surdite exige aussi
    que l'emission aille : aucun delai dans la fenetre (winTimeout_) et pas
    de serie de delais en cours (close par un accuse ou un MAX_RT). Sinon,
    une relance 4 qui guerit l'ecoute mais pas l'emission (l'incident
    montrait les deux) levait EN PANNE, eteignait la LED et ramenait les
    relances a 60 s pendant que chaque envoi echouait.
    - Reglage de l'ecoute : ChipWatch::calmVisible (rearmement <= 200 ms,
    silence > 2 rearmements) garantit les 20 periodiques en 10 s de piece
    calme dont la guerison a besoin (au pire 22, simule avec un tour toutes
    les 1 a 10 ms ; 250/500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
    [cli_lampe.cpp, halo1_lamp.cpp, halo1_watch.h]
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2026-09-24 Corriger les suites de revue du retrait Halo 2
    Suites des deux revues de l'etape C6 (46dcbd1).
    - CLI : une commande inconnue n'invalide plus la radio du pilote. Depuis
    le retrait de 'debug', une faute de frappe forcait une reconfiguration
    complete et effacait les indices du chien de garde L2.
    - 'rafale' juge le debit sur la trame Halo 1 (commande 81 bits, accuse
    65 bits : 648/520 us a 125 kbps) et non plus sur une trame Halo 2 de
    19 octets, qui lisait la telecommande comme du 250 kbps, conclusion
    refutee. La balise d'etalonnage reste la reference de la bande
    800-1499 us.
    - isPairingAddr tire ses adresses de halo1::kPairingH1Reg/kPairingH2Reg
    et airOrder : meme ensemble, une se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
    [bc5602.h, cli.cpp, config.h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]
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2026-09-24 Corriger les suites de revue du mode machine JSON
    - La reponse fin d'une commande historique n'est plus perdue quand le
    texte de la commande a rempli le tampon d'emission (help ecrit ~7 Ko en
    ecritures bloquantes) : tout de suite si une ligne entiere tient, sinon
    par la file des qu'elle tient (jsonReplyEnd), sans jamais bloquer.
    - Les reponses differees (json 1, json etat, json hello) ne sont plus
    perdues apres 500 ms de retard : elles partent des que 1024 octets sont
    libres ; seules les lignes periodiques restent soumises au retard et aux
    2048 octets libres (Queue::dropLate, Queue::frontReady).
    - Une demande explicite fondue dans une ligne periodique deja en file
    compte son re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
    [cli.cpp, json_mode.cpp]
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
